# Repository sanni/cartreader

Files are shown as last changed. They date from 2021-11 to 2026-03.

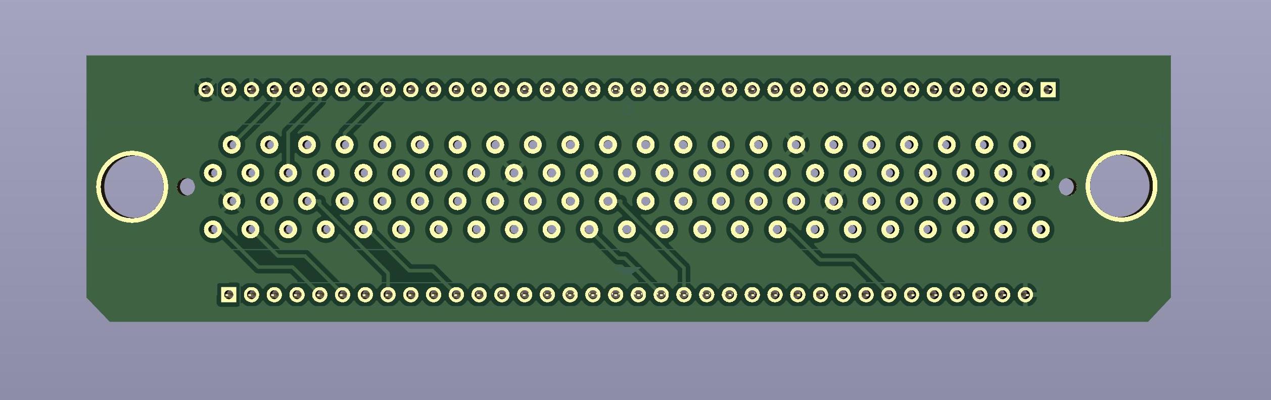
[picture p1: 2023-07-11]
hardware/loopy_adapter/loopy_adapter.jpg

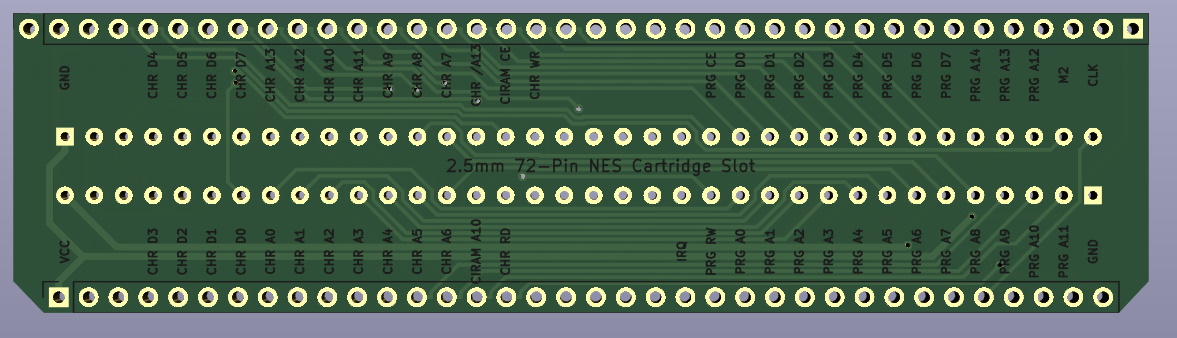
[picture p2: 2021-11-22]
hardware/nes_adapter/nes_adapter.jpg

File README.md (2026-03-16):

<br>    
<br>    
<br>   
<br>
We have moved, please visit us at https://github.com/oscartreader 🚀
<br>    
<br>    
<br>   
<br>
<br>    
<br>    
<br>   



# Open Source Cartridge Reader
This project represents a community-driven effort to provide an easy to build and easy to modify cartridge dumper.
Its main purpose is to dump a video game's ROM and save file to an SD card without the need of a PC.

For any questions you can use the [Discussions](https://github.com/sanni/cartreader/discussions) and/or [Issues](https://github.com/sanni/cartreader/issues) section here on GitHub, visit the accompanying thread in the [Arduino Forum](http://forum.arduino.cc/index.php?topic=158974.9001) or check out our [community discord server](https://discord.gg/YVxv7BnzXt), where you can reach most of the devs directly.

Also be sure to check the guides in the [Wiki](https://github.com/sanni/cartreader/wiki) too.

Happy making. 🔧🔨😊



#### Features:
- Modular design
- Stand-alone operation
- Easy to modify open-source code
- Portable when used together with a power bank



#### Supported Systems:
- NES/Famicom/Family Basic
- Super Nintendo/Super Famicom (including SF Memory, Satellaview, Sufami Turbo, and Game Processor RAM Cassettes)
- Nintendo 64 (including Controller Pak, Gameshark, and Xplorer 64)
- Game Boy Color (including GB Memory, Codebreaker, and Gameshark)
- Game Boy Advance
- Sega Mega Drive/Genesis
- Sega Master System



#### Supported with adapters:
- Virtual Boy
- Pokémon Mini
- Sega Game Gear
- Sega Mark III
- Sega SG-1000/SC-3000
- Sega Cards
- PC Engine/TurboGrafx-16/SuperGrafx
- WonderSwan (Color)
- NeoGeo Pocket (Color)
- Intellivision
- ColecoVision
- Benesse Pocket Challenge W
- Benesse Pocket Challenge V2
- Watara Supervision
- Atari 8-bit Computer (400/800/XL/XE)
- Atari 2600/5200/7800
- Atari Lynx
- Atari Jaguar
- Emerson Arcadia 2001
- Fairchild Channel F
- Magnavox Odyssey 2/Philips Videopac+
- Super A'Can
- MSX
- Casio PV-1000
- Casio Loopy
- Commodore VIC-20
- Commodore 64
- Vectrex
- Bally Astrocade
- Bandai Little Jammer
- Bandai Little Jammer Pro
- LeapFrog Leapster (L-MAX/Leapster2)
- RCA Studio II
- Texas Instruments TI-99
- Tomy Pyuuta
- TRS-80 Color Computer
- Vtech V.Smile (Baby/V.Motion)
- CPS3

#### Open Source Licenses:
- Software(everything in Cart_Reader folder) = GPL v3
- Hardware(everything in hardware folder) = CC BY 4.0
- Documentation(everything in the Wiki) = CC0 1.0

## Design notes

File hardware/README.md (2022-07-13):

## All the files in this directory are licensed under the Attribution 4.0 International (CC BY 4.0)     

### This means that you are free to:    
- Share - copy and redistribute the material in any medium or format    
- Adapt - remix, transform, and build upon the material for any purpose, even commercially.  

The licensor cannot revoke these freedoms as long as you follow the license terms.    

### Under the following terms:    
- Attribution - You must give appropriate credit, provide a link to the license, and indicate if changes were made. You may do so in any reasonable manner, but not in any way that suggests the licensor endorses you or your use.    
- No additional restrictions - You may not apply legal terms or technological measures that legally restrict others from doing anything the license permits.    

More details: https://creativecommons.org/licenses/by/4.0/

##

You can view the schematic and PCB files using [KiCad](https://www.kicad.org/).   
To design your own adapters you can follow this [tutorial](https://github.com/sanni/cartreader/wiki/Designing-your-own-Adapters)   
Also check out the user contributions for even more adapters: https://github.com/sanni/cartreader/discussions/354

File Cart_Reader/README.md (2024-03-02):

## This Arduino sketch is licensed under the GNU GENERAL PUBLIC LICENSE Version 3 (GPL v3)    

### This means that you are free to:    
- use, modify and distribute this software, even commercially    

### Under the following terms:    
- state changes   
- disclose source   
- same license   

### Limitations:
- Liability   
- Warranty   

More details: https://www.gnu.org/licenses/gpl-3.0.en.html    

## 

Every submodule has it's own setup_XX() function that configures the needed pins and a submenu that lets you choose what you want to do. 
The code directly addresses the pins via the DDR, PIN and PORT registers.   
Please also refer to the [pinout Open Office sheet](https://github.com/sanni/cartreader/blob/master/pinout.ods).    
```
void setup_N64_Controller() {  
  // Output a low signal  
  PORTH &= ~(1 << 4);  
  // Set Controller Data Pin(PH4) to Input  
  DDRH &= ~(1 << 4);  
}  
```

Would be the same as this in a more traditional Arduino sketch:  
```
int dataPin = 7;   

void setup(){    
  // Output a low signal   
  digitalWrite(dataPin, LOW);   
  // Set controller data pin to input  
  pinMode(dataPin, INPUT);  
}  
```
To preserve memory every string is saved into the flash of the Arduino, also called progmem. This is done by using the F() macro.   
```
println_Msg(F("Press Button."));  
```
Also all the menus are stored in progmem and are only recalled to sram when needed.  
```
// N64 controller menu items  
const char N64ContMenuItem1[] PROGMEM = "Test Controller";  
const char N64ContMenuItem2[] PROGMEM = "Read ControllerPak";  
const char N64ContMenuItem3[] PROGMEM = "Write ControllerPak";  
const char* const menuOptionsN64Controller[] PROGMEM = {N64ContMenuItem1, N64ContMenuItem2, N64ContMenuItem3, FSTRING_RESET};
```
In an effort to keep the codebase as portable as possible instead of using the functions supplied by the OLED library directly to print out text, auxiliary functions like `println_Msg` are being used. So if you want to change to another display library you don't need to change all the code but only the helper functions. 
```
void print_Msg(long unsigned int message) {
  if (ENABLE_OLED)
    display.print(message);
  if (ENABLE_SERIAL)
    Serial.print(message);
}
```

Before uploading the code to your Arduino you need to select your hardware version in Cart_Reader.ino        
```
//******************************************
// !!! CHOOSE HARDWARE VERSION !!!
//******************************************
// Remove // in front of the line with your hardware version
// #define HW5
// #define HW4
#define HW3
// #define HW2
// #define HW1
// #define SERIAL_MONITOR

```

For more info please have a look at [this wiki article](https://github.com/sanni/cartreader/wiki/How-to-flash-the-Arduino).   

Needed libraries(already included in the portable Arduino IDE under Releases)   

SD lib: https://github.com/greiman/SdFat    
LCD lib: https://github.com/olikraus/U8g2_Arduino     
Neopixel lib: https://github.com/adafruit/Adafruit_NeoPixel    
Rotary Enc lib: https://github.com/mathertel/RotaryEncoder    
SI5351 lib: https://github.com/etherkit/Si5351Arduino        
RTC lib: https://github.com/adafruit/RTClib (needs BusIO lib: https://github.com/adafruit/Adafruit_BusIO)     
Frequency Counter lib: https://github.com/PaulStoffregen/FreqCount

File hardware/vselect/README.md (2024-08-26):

# VSELECT: Automatic Voltage Selection Module

The VSELECT module automates voltage selection on HW5 by allowing the firmware to set the voltage. The module version is intended to be soldered in place of the voltage selection switch. You cannot use the VSELECT module and a power LED at the same time.

## Ordering the PCB and Installing the components

The VSELECT module requires SMD/SMC (surface-mounted devices/components) soldering. The pads have been extended slightly to aid in hand-soldering. While files suitable for use with JLCPCB's PCBA service have been included, these are unsuitable for most people to use due to the minimum order quantity. If you want fewer than 10 modules it will be cheaper to order them from someone selling pre-built ones.

## Installation

Instructions to build as well as to install the module have moved [to the wiki](https://github.com/sanni/cartreader/wiki/Automatic-Voltage-Selection).

## Configuration

The module requires code to function properly. The OSCR should still power on even without the code changes but the voltage will not automatically toggle. To enable automatic toggling, locate this bit of code:

```
/*==== HARDWARE MODULES ===========================================*/

/* [ Automatic Voltage Selection ---------------------------------- ]
    Enable this if you have the VSELECT module.
*/

//#define ENABLE_VSELECT
```

...and change it to:

```
/*==== HARDWARE MODULES ===========================================*/

/* [ Automatic Voltage Selection ---------------------------------- ]
    Enable this if you have the VSELECT module.
*/

#define ENABLE_VSELECT
```

After that simply update/program/flash your Arduino/OSCR as normal. Make sure you enable this every time you update. You can test that voltage switching is occurring with a multimeter by checking between ground and VCC.

## Updating
When the OSCR is using VSELECT-enabled firmware there are a few extra steps you need to take when flashing firmware. First, before connecting the OSCR to a computer, remove the SD card. Next, connect the OSCR to your computer and wait. Once it prompts you, press the button to set the voltage to 5V. Although you can flash the ATmega2560 while running at 3.3V it does not always work and seems more likely to cause the firmware to randomly be corrupt (sometimes right away, sometimes not for a few days). Although you can just reflash the firmware to it to resolve it, having to deal with it is rather inconvenient.

## Troubleshooting
If the 3.3V rail is not powered (i.e. you forgot to solder the jumper on the LCD) then when the module tries to switch to that it will power off the VCC rail. This will appear as a reboot loop where you'll see it briefly power on and then immediately power off only to immediately power on again. This is because the module starts in 5V mode and switches to 3.3V after the system boots and tells it to do so.

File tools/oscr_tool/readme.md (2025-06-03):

A small tool for Windows 10/11 that helps manage the portable release.

oscr_tool

Copy the files to the root directory of the portable release and double click on launch_oscr_tool.bat to start it.

launch

If you get an error you need to first allow the script to run by right-clicking oscr_tool.ps1, Properties and then tick the Unblock checkbox.

unblock

You can also create an apply_config.txt with the settings you always want to have applied, see example apply_config.txt.

This tool was made by ChatGPT, Claude AI and Github Copilot. Console descriptions are taken from the respective Wikipedia sites.

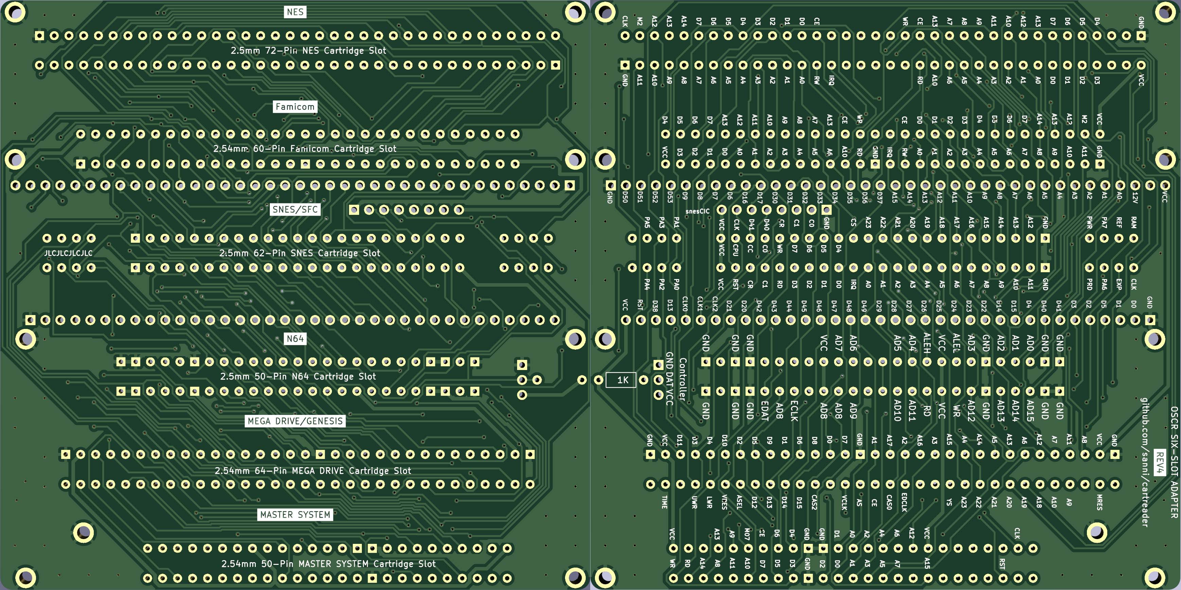
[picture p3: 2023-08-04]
hardware/six_slot_adapter/six_slot_adapter.jpg

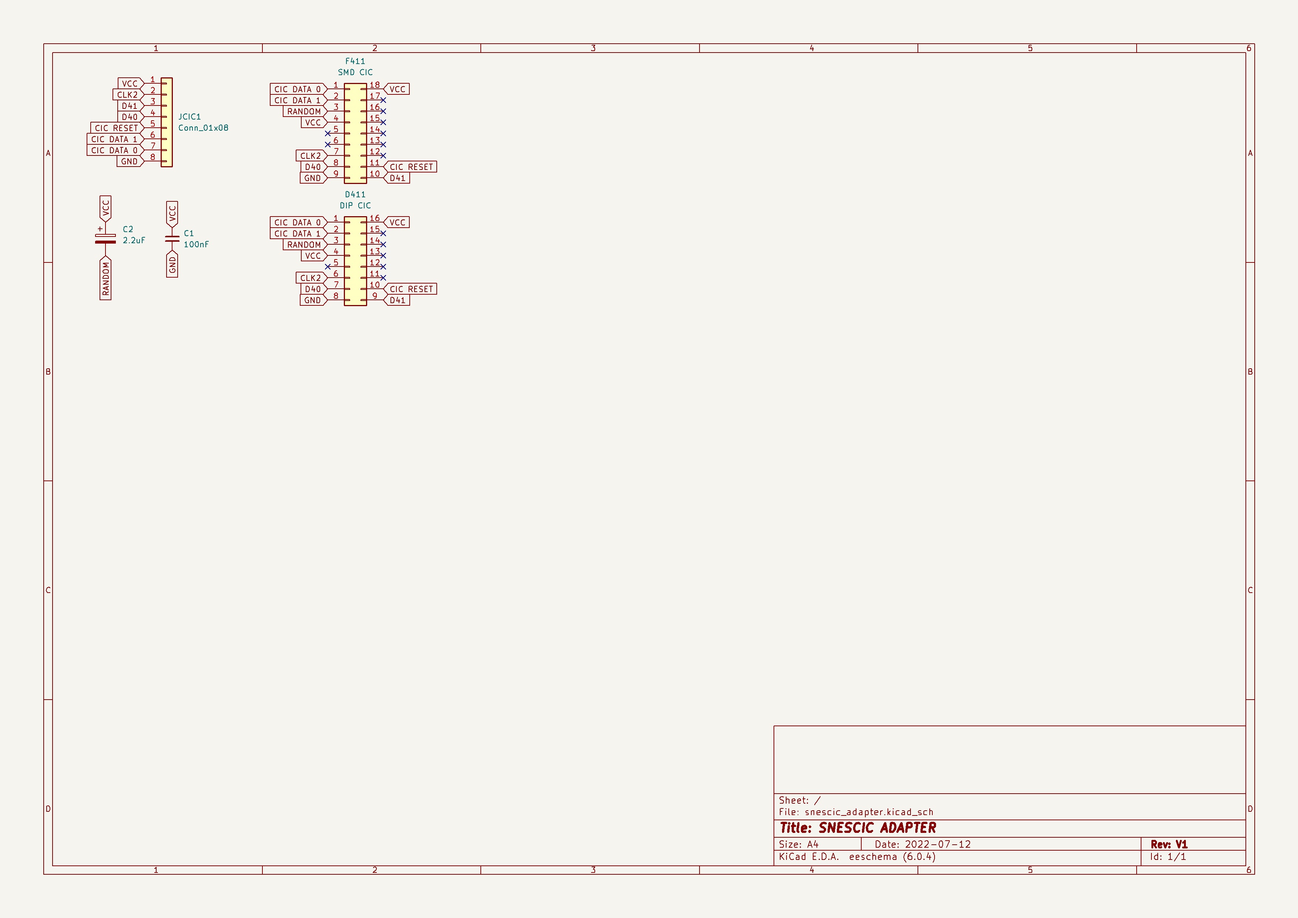
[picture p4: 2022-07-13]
hardware/cic_adapter/D411_F411_adapter_schematics.jpg

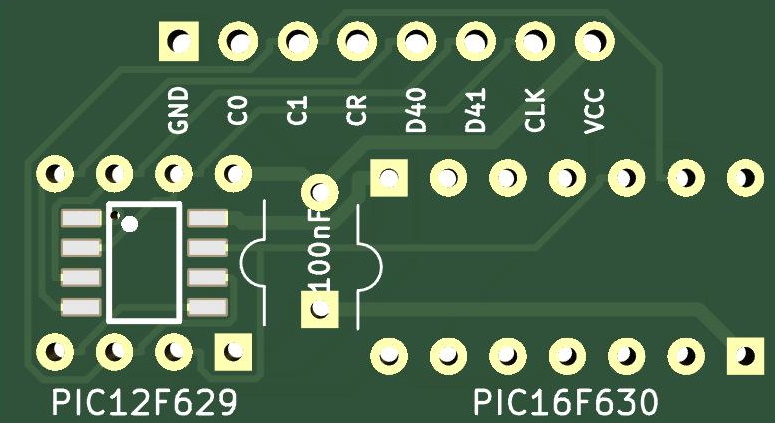
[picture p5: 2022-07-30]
hardware/cic_adapter/PIC_adapter.jpg

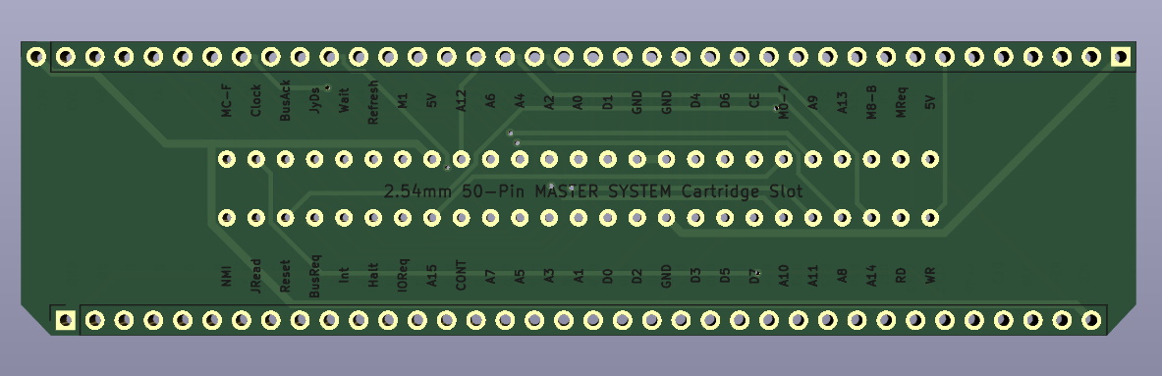
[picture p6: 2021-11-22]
hardware/mastersystem_adapter/mastersystem_adapter.jpg

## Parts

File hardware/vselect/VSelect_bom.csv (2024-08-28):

Designator | Footprint | Quantity | Value | LCSC Part #
C1, C2 | 0402 | 2 | 0.1u | C1525
C3 | 0402 | 1 | 10u | C15525
R1 | 0402 | 1 | 560R | C25123
U1 | IC - VSELECT - TPS2113 | 1 | TPS211x | C354512

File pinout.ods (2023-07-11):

Arduino | Alt. Arduino | ATMega2560 | Game Boy | GBA | NES | SNES | snesCIC | N64 ROM | N64 Controller | N64 EEP | Master System | Megadrive | PCE/TG16 | Wonderswan | Loopy | LED | SD Card | OLED | LCD | Button | Rotary Encoder | Neopixel | 16bit Flash | 8bit Flash | 16bit Flash in 8bit Mode | 27C322 Eprom
A0 | D54 | PF0 | A0 | AD0 | M2 | A0 |  | AD0 |  |  | A0 | A1 | A0 | A-1 | D10 |  |  |  |  |  |  |  | A0 | A0 | D15 | A0
A1 | D55 | PF1 | A1 | AD1 | PRG_CE | A1 |  | AD1 |  |  | A1 | A2 | A1 | A0 | D8 |  |  |  |  |  |  |  | A1 | A1 | A0 | A1
A2 | D56 | PF2 | A2 | AD2 | CHR_WR | A2 |  | AD2 |  |  | A2 | A3 | A2 | A1 | D6 |  |  |  |  |  |  |  | A2 | A2 | A1 | A2
A3 | D57 | PF3 | A3 | AD3 | CIRAM_CE | A3 |  | AD3 |  |  | A3 | A4 | A3 | A2 | D4 |  |  |  |  |  |  |  | A3 | A3 | A2 | A3
A4 | D58 | PF4 | A4 | AD4 | CHR_/A13 | A4 |  | AD4 |  |  | A4 | A5 | A4 | A3 | D14 |  |  |  |  |  |  |  | A4 | A4 | A3 | A4
A5 | D59 | PF5 | A5 | AD5 | CHR_RD | A5 |  | AD5 |  |  | A5 | A6 | A5 | A4 | D3 |  |  |  |  |  |  |  | A5 | A5 | A4 | A5
A6 | D60 | PF6 | A6 | AD6 | IRQ | A6 |  | AD6 |  |  | A6 | A7 | A6 | A5 | D2 |  |  |  |  |  |  |  | A6 | A6 | A5 | A6
A7 | D61 | PF7 | A7 | AD7 | PRG_RW | A7 |  | AD7 |  |  | A7 | A8 | A7 | A6 | RESET |  |  |  |  |  |  |  | A7 | A7 | A6 | A7
A8 | D62 | PK0 | A8 | AD8 | D0 | A8 |  | AD8 |  |  | A8 | A9 | A8 | A7 | D0 |  |  |  |  |  |  |  | A8 | A8 | A7 | A8
A9 | D63 | PK1 | A9 | AD9 | D1 | A9 |  | AD9 |  |  | A9 | A10 | A9 | A8 | A0 |  |  |  |  |  |  |  | A9 | A9 | A8 | A9
A10 | D64 | PK2 | A10 | AD10 | D2 | A10 |  | AD10 |  |  | A10 | A11 | A10 | A9 | A1 |  |  |  |  |  |  |  | A10 | A10 | A9 | A10
A11 | D65 | PK3 | A11 | AD11 | D3 | A11 |  | AD11 |  |  | A11 | A12 | A11 | A10 | A21 |  |  |  |  |  |  |  | A11 | A11 | A10 | A11
A12 | D66 | PK4 | A12 | AD12 | D4 | A12 |  | AD12 |  |  | A12 | A13 | A12 | A11 | A3 |  |  |  |  |  |  |  | A12 | A12 | A11 | A12
A13 | D67 | PK5 | A13 | AD13 | D5 | A13 |  | AD13 |  |  | A13 | A14 | A13 | A12 | A20 |  |  |  |  |  |  |  | A13 | A13 | A12 | A13
A14 | D68 | PK6 | A14 | AD14 | D6 | A14 |  | AD14 |  |  | A14 | A15 | A14 | A13 | A15 |  |  |  |  |  |  |  | A14 | A14 | A13 | A14
A15 | D69 | PK7 | A15 | AD15 | D7 | A15 |  | AD15 |  |  |  | A16 | A15 | A14 | A13 |  |  |  |  |  |  |  | A15 | A15 | A14 | A15
D0 | RX0 | PE0
D1 | TX0 | PE1 |  |  |  |  |  |  |  |  |  |  |  |  |  | build-in (LCD blink)
D2 | PWM | PE4 |  |  |  | WRAM |  |  |  |  |  | (YS) |  | IO | D11
D3 | PWM | PE5 |  |  |  | REFRESH |  |  |  |  |  | CAS2 |  | CLK | D9
D4 | PWM | PG5 |  |  |  | EXPAND |  |  |  |  |  | ASEL |  | Int | D15
D5 | PWM | PE3 |  |  |  |  |  |  |  |  |  | EDCLK
D6 | PWM | PH3 | CS | CS_ROM |  | CS |  |  |  |  | A15/M0-7 | CS | OE | CART | RAMWE |  |  |  |  |  |  |  | BYTE | OE | OE
D7 (1K Pullup) | PWM | PH4 | Sound | IRQ |  | IRQ |  |  | DATA | DATA |  | WR HIGH | IRQ2 | MMC | RAMCS2 |  |  |  |  |  |  |  | WE
D8 | PWM | PH5 | WR | WR |  | WR |  | WR |  |  | WR | WR LOW | WR | WE |  |  |  |  |  |  |  |  | WP | WE | WE | To NPN transistor controlling VPP 12V stepup regulator module
D9 | PWM | PH6 | RD | RD |  | RD |  | RD |  |  | OE | OE |  | OE |  |  |  |  |  |  |  |  | CE | CE | CE | CE
D10 | PWM | PB4 |  |  |  |  |  |  |  |  |  |  |  |  |  | Blue (OLED blink) |  |  | Reset
D11 | PWM | PB5 |  |  |  |  |  |  |  |  |  |  |  |  |  | Green |  |  | DC/A0
D12 | PWM | PB6 |  |  |  |  |  |  |  |  |  |  |  |  |  | Red |  |  | CS
D13 | PWM | PB7 |  |  |  |  |  |  |  |  |  |  |  |  |  | build-in (Serial blink) |  |  |  |  |  | Neopixel
D14 | TX3 | PJ1 |  |  |  | PAWR |  |  |  |  |  | AS |  |  | D12
D15 | RX3 | PJ0 |  |  |  | PARD |  |  |  |  |  | Time |  |  | D13
D16 | TX2 | PH1 | CLK | CLK |  |  |  |  |  |  | CLK | VCLK
D17 | RX2 | PH0 | Reset | CS_RAM |  | Reset |  | Reset |  | Reset | Reset | (MRES),VRES | RST | Reset |  |  |  |  |  |  |  |  | Reset | Reset | Reset
D18 | TX1 | PD3 |  |  |  |  |  |  |  |  |  |  |  |  |  |  |  |  |  |  | ENC1
D19 | RX1 | PD2 |  |  |  |  |  |  |  |  |  |  |  |  |  |  |  |  |  |  | ENC2
D20 | SDA | PD1 |  |  |  |  |  |  |  |  |  |  |  |  |  |  |  | SDA
D21 | SCL | PD0 |  |  |  |  |  |  |  |  |  |  |  |  |  |  |  | SCL
D22 |  | PA0 |  |  | A8 | PA0 |  |  |  |  |  | D8 |  | D8 | D1 |  |  |  |  |  |  |  | D8 |  |  | D8
D23 |  | PA1 |  |  | A9 | PA1 |  |  |  |  |  | D9 |  | D9 | A2 |  |  |  |  |  |  |  | D9 |  |  | D9
D24 |  | PA2 |  |  | A10 | PA2 |  |  |  |  |  | D10 |  | D10 | A4 |  |  |  |  |  |  |  | D10 |  |  | D10
D25 |  | PA3 |  |  | A11 | PA3 |  |  |  |  |  | D11 |  | D11 | A19 |  |  |  |  |  |  |  | D11 |  |  | D11
D26 |  | PA4 |  |  | A12 | PA4 |  |  |  |  |  | D12 |  | D12 | A18 |  |  |  |  |  |  |  | D12 |  |  | D12
D27 |  | PA5 |  |  | A13 | PA5 |  |  |  |  |  | D13 |  | D13 | A16 |  |  |  |  |  |  |  | D13 |  |  | D13
D28 |  | PA6 |  |  | A14 | PA6 |  |  |  |  |  | D14 |  | D14 | A17 |  |  |  |  |  |  |  | D14 |  |  | D14
D29 |  | PA7 |  |  |  | PA7 |  |  |  |  |  | D15 |  | D15 | A14 |  |  |  |  |  |  |  | D15 |  |  | D15
D30 |  | PC7 | D7 | A23 |  | D7 |  |  |  |  | D7 | D7 | D7 | D7 |  |  |  |  |  |  |  |  | D7 | D7 | D7 | D7
D31 |  | PC6 | D6 | A22 |  | D6 |  |  |  |  | D6 | D6 | D6 | D6 |  |  |  |  |  |  |  |  | D6 | D6 | D6 | D6
D32 |  | PC5 | D5 | A21 |  | D5 |  |  |  |  | D5 | D5 | D5 | D5 |  |  |  |  |  |  |  |  | D5 | D5 | D5 | D5
D33 |  | PC4 | D4 | A20 |  | D4 |  |  |  |  | D4 | D4 | D4 | D4 |  |  |  |  |  |  |  |  | D4 | D4 | D4 | D4
D34 |  | PC3 | D3 | A19 |  | D3 |  |  |  |  | D3 | D3 | D3 | D3 | A12 |  |  |  |  |  |  |  | D3 | D3 | D3 | D3
D35 |  | PC2 | D2 | A18 | CIRAM_A10 | D2 |  |  |  |  | D2 | D2 | D2 | D2 | A10 |  |  |  |  |  |  |  | D2 | D2 | D2 | D2
D36 |  | PC1 | D1 | A17 |  | D1 |  | ALE_H |  |  | D1 | D1 | D1 | D1 | A8 |  |  |  |  |  |  |  | D1 | D1 | D1 | D1
D37 |  | PC0 | D0 | A16 |  | D0 |  | ALE_L |  |  | D0 | D0 | D0 | D0 | A6 |  |  |  |  |  |  |  | D0 | D0 | D0 | D0
D38 |  | PD7 |  |  |  |  |  |  |  |  |  |  |  |  |  | HW5 status LED |  |  |  | Button1 (10K Pullup)
D39 |  | PG2 |  |  |  |  |  |  |  |  |  |  |  |  |  |  |  |  |  | Button 2 (10K Pullup) | ENC Button
D40 |  | PG1 |  |  |  |  | Reset In (Pin 4) |  |  |  |  |  |  |  | D5
D41 |  | PG0 |  |  |  |  | Reset Out Host (Pin 3) |  |  |  |  |  |  |  | D7
D42 |  | PL7 |  |  | A7 | A23 |  |  |  |  |  |  | Card Detect |  | CE
D43 |  | PL6 |  |  | A6 | A22 |  |  |  |  |  | A23 | Audio In |  | OE |  |  |  |  |  |  |  |  |  | A21
D44 | PWM | PL5 |  |  | A5 | A21 |  |  |  |  |  | A22 | HSM |  |  |  |  |  |  |  |  |  | A21 | A21 | A20
D45 | PWM | PL4 |  |  | A4 | A20 |  |  |  |  |  | A21 | CE |  |  |  |  |  |  |  |  |  | A20 | A20 | A19 | A20
D46 | PWM | PL3 |  |  | A3 | A19 |  |  |  |  |  | A20 | A19 | A18 | A11 |  |  |  |  |  |  |  | A19 | A19 | A18 | A19
D47 |  | PL2 |  |  | A2 | A18 |  |  |  |  |  | A19 | A18 | A17 | A9 |  |  |  |  |  |  |  | A18 | A18 | A17 | A18
D48 |  | PL1 |  |  | A1 | A17 |  |  |  |  | CE | A18 | A17 | A16 | A7 |  |  |  |  |  |  |  | A17 | A17 | A16 | A17
D49 |  | PL0 |  |  | A0 | A16 |  |  |  |  |  | A17 | A16 | A15 | A5 |  |  |  |  |  |  |  | A16 | A16 | A15 | A16
D50 | MISO | PB3 |  |  |  |  |  |  |  |  |  |  |  |  |  |  | MISO
D51 | MOSI | PB2 |  |  |  |  |  |  |  |  |  |  |  |  |  |  | MOSI |  | MOSI
D52 | SCK | PB1 |  |  |  |  |  |  |  |  |  |  |  |  |  |  | SCK |  | SCK
D53 | SS | PB0 |  |  |  |  |  |  |  |  |  |  |  |  |  |  | SS
CLK0 |  |  |  |  |  | CLK
CLK1 |  |  |  |  |  | CPUCLK |  |  |  | EEP CLK
CLK2 |  |  |  |  |  | CICCLK | CLK (Pin 2)
 |  |  |  |  |  | Reset In | Reset Out Slave (Pin 5)
 |  |  |  |  |  | CIC1 | CIC1 (Pin 6)
 |  |  |  |  |  | CIC0 | CIC0 (Pin 7)
GND |  |  |  |  |  |  |  |  |  |  |  |  |  |  |  |  |  |  |  |  |  |  |  |  | BYTE

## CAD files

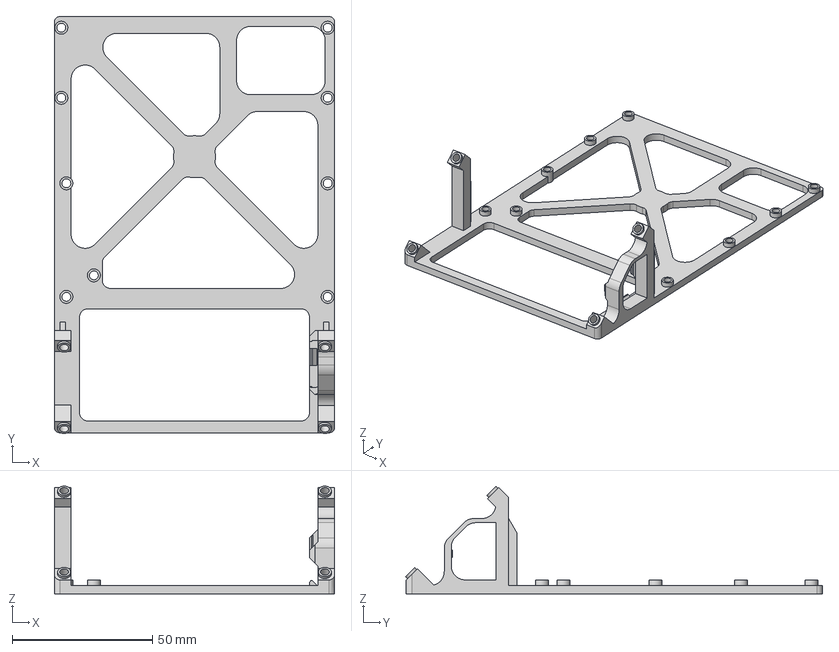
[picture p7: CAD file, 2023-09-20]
hardware/main_pcb_hw5/Main PCB Stand - Right N64 Adapter with Battery Access.step
100.0 x 148.7 x 38.5 mm

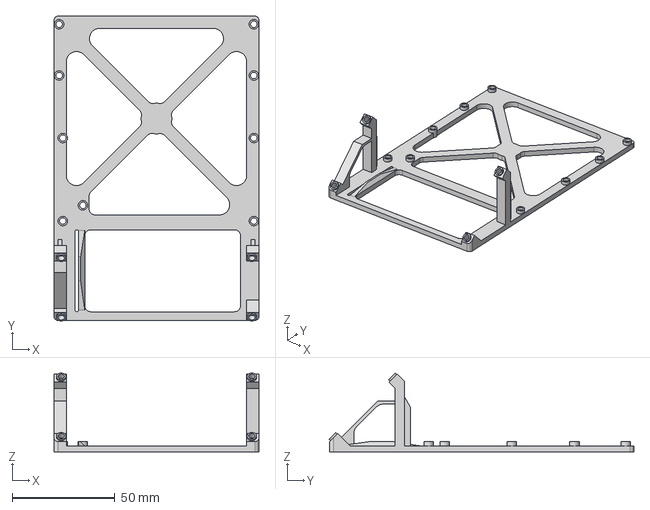
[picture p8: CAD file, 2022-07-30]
hardware/main_pcb_hw5/Main PCB Stand - Left N64 Adapter.step
100.0 x 148.7 x 38.5 mm

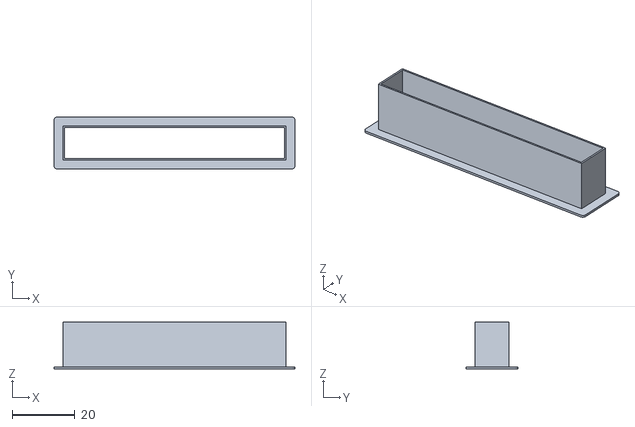
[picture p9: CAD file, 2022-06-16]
hardware/six_slot_adapter/n64sleeve.stl
77.0 x 16.6 x 15.0

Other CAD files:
hardware/main_pcb_hw5/Main PCB Stand - Right N64 Adapter.step
hardware/main_pcb_hw5/Main PCB Stand - No N64 Adapter.step
hardware/main_pcb_hw5/Main PCB Stand - Left N64 Adapter.stl
hardware/main_pcb_hw5/Main PCB Stand - No N64 Adapter.stl
hardware/main_pcb_hw5/Main PCB Stand - Right N64 Adapter.stl

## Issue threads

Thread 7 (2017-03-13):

PCB does not convert logic level of SD card

nvsofts, 2017-03-13:
cartreader PCB uses "LC Studio" SD card module.
This module does not convert logic level of SD card.
This will be damaged or caused unexpected behavior to SD card.

I used this module to fix the problem.

microSD card module (Parts no: MCSD125A)
http://www.aitendo.com/product/10192 (Sorry, this page is written in Japanese)

The module uses SN74LV125A buffer IC to convert logic level.
However, the module does not contain 3.3V pin.
Therefore I applied small hack to the module (desolder AMS1117, short 5V-3.3V solder pad).

nvsofts, 2017-03-13:
similar item found in US Amazon
https://www.amazon.com/dp/B00SL0QWDU/

tamanegitaro, 2017-05-30:
nvsoft is correct.
Level shifter is not implemented on LC studio SD card module if the schematic in this thread is correct:
https://forum.arduino.cc/index.php?topic=369079.0
So you need to use level shifter for CS, SCK, MOSI, MISO pins or use microsd card adapter nvsoft provided.
I don't think you need to remove AMS1117 though because microsd card adapter also support 3.3V.
You don't need to remove AMS1117.

So best solution is to use microsd adapter and connect 5V to VCC on microsd adapter. So all CS, SCK, MOSI, MISO, and VCC will be 5V in 5V mode and be 3V in 3V mode.

sanni, 2017-07-10:
I added an option to install the suggested microSD module to the pcb. Since the cartreader shield already has an AMS1117 I desoldered it from the microSD module and shorted the 5V-3.3V solder pads on the AMS1117's footprint.

But be aware that from my tests microSD cards are twice as slow as standard sized cards with the sdfat library I'm using for the cart reader. I don't know why though.

tamanegitaro, 2017-08-02:
Ahh my bad. Desoldering AMS1117 and connect 3.3V is best way to get around.

Supplying 3.3V to AMS1117 on micro SD card module is not enough because AMS1117 dropout voltage is 1.1V.
Which means voltage of sd card's signal line will become 2.2V and SD card require 2.7V-3.6V as minimum to maximum, respectively.
Another option will be to supply 5V (from slide switch) to AMS1117 on microsd module so I'm gong to try that.

Closed 2018-04-21.

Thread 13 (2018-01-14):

Gerber files

AireagoirSteam, 2018-01-14:
Are there Gerber files for the all in one variant? The wiki lists ones for another variant.

sanni, 2018-01-15:
The currently uploaded "github version" pcb design has been tested many times and works great.
The all-in-one variant is still in development and therefore no gerber files are available.
Both variants are functionally equivalent so you're not missing out on anything if you order the github version.

If you really really want the all-in-one then I can send you a prototype pcb, just the pcb no parts.
Message me on the Arduino forum in case you're interested.

Closed 2018-04-21.

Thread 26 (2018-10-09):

Status of firmware compatibility with SNES and N64 old version

vogelfreiheit, 2018-10-09:
Hi,

I have built an older version of the hardware, with N64 and SNES slots. Does the current firmware support that version? Or I need to modify any pin settings or such?

sanni, 2018-10-09:
It's 100% compatible with the newest firmware. I'm still using one of the earlier Cart Reader PCBs myself.

vogelfreiheit, 2018-10-09:
Thanks man! I might consider selling some kits or bare PCBs if you are OK with that. I just made too many. I can also send you some. Got photos of the silkscreening and all. I will flash the  board now and check back.

BTW I populated the capacitor at the USB input. I never saw it mentioned anywhere in the guides but it shouldn't hurt (the electrolytic).

vogelfreiheit, 2018-10-09:
One issue I encountered with some N64 carts: flashram unknown is reported. I have the external clock ref enabled and plugged in through a pin header. What could possibly cause this?

vogelfreiheit, 2018-10-09:
Re-tested with both Arduino-sourced power and using the port on the shield. I'm using 3.3V, no EEP and EEP and the clock settings turned off. No improvement there.

sanni, 2018-10-10:
Have you tested dumping the rom of the cartridge to make sure everything works with the N64 cart slot? Also try to write a save game to a cartridge with the sram save type to verify that writing to a N64 cartridge in general works so you can rule out a cold solder joint.

vogelfreiheit, 2018-10-12:
I will upload a patch later, I had to add support for two cartridges that use one of the 'alternative' configurations (they can either have a MN63F81MPN or 29L1100KC) that identify as different ICs, but are still supported by the present code for 29L1100KC-15B0.

The codes were 0x84 and 0x8e if I recall correctly. The hardware itself presents no issues. I get more problems out of the GBA/GBC slot adapter+cartridge setup than anything else. N64 carts and anything with direct slot plugging works fine.

It might be worth considering adding a PCB that takes a salvaged GBC cart slot, which are arguably the best for that system (no pin wear and no issues with the cart moving slightly and causing contact problems).

sanni, 2018-10-13:
Yes that's the reason why the current PCB design has both the MD and GB slot directly on the main PCB without any adapters.

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

Closed 2018-11-20.

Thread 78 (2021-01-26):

Only post issues with existing code for already supported stuff.

sanni, 2021-01-26:
For general questions or help with currently unsupported stuff please post in the Discussions section.

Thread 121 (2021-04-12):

Problem when reading save from Nintendo 64 EEPROM cartidges

parski, 2021-04-12:
I've been dumping Nintendo 64 SRAM games without issue but now attempting to dump EEPROM save files it appears to crash. These are my steps:

DIPS:

```
+-------+-------+
| 3V/5V | 3V  < |
+-------+-------+
| EEP   | ON  > |
+-------+-------+
| CLK0  | OFF < |
+-------+-------+
| CLK1  | OFF < |
+-------+-------+
```

1. Turn the unit ON.
2. Select **Nintendo 64**
3. Select **Game Cartridge**

```
N64 Cartridge Info

Name: MARIOKART64
ID: NKTJ Size: 12MB
Save: 4K Eeprom
Version: 1.0

Press Button...
```

4. Press button
5. Select **Read Save**

LED flashes blue maybe five times in rapid succession, then LED is persistently off. Stuck on the screen is the following:

```
Reading Eep...
```

I've tried leaving the unit on for a good 20 minutes and I'm assuming something is wrong and that this is not an overnight operation. How can I troubleshoot this? As previously mentioned, dumping SRAM is not a problem.

parski, 2021-04-12:
When checking the SD card after an attemt it has created a directory structure like so:
```
/N64/SAVE/{game}/{integer}/
```
With one `{integer}` directory per attempt. These directories are empty.

sanni, 2021-04-13:
Make sure its an original cartridge and not a Chinese reproduction.
Reading the eeprom needs two connections, data and clock. Try resoldering all the points on the PCB involved and make sure the 1K resistor in the data line is connected properly too.

You can also use a multimeter to check all the traces.

This is the clock line on the PCB, it comes from the Arduino pin D16 at the top, goes through the CLK1 switch(switched to off) and then finally into the CLK pin on the N64 cart slot:
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

This is the data line, it goes from Arduino pin D7 straight into the DAT pin on the N64 cart slot, but is also connected to the EEP switch and through the EEP switch(switched to on) it goes to the 1K resistor to VCC:
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

If you got the N64 controller plug installed you can also test the DAT pin with a N64 controller, if the controller test works the DAT pin is ok. However the CLK pin is not used with the controller.

If all the physical connections are ok you can clean the cart edge connector of the game with a q-tip and some rubbing alcohol.
Lastly you can try another eeprom game to see if the issue maybe is specific to the particular eeprom chip in Mario Kart. I always wanted to rewrite the current eeprom code to utilise the clock generator to be more precise, but so far all the carts I tested worked with the current somewhat crude implementation that doesn't need a clock gen.

parski, 2021-04-14:
Thank you for your exceptional response.

I get continuity between D16 on the Arduino and the CLK pin in the Nintendo 64 cartridge slot with the CLK1 switch set to the OFF position, as you described.

I also get continuity between D7 on the Arduino and the DAT pin in the Nintendo 64 cartridge slot regardless if the EEP switch is set to ON or OFF.

I've tried several cartridges including a launch copy of Super Mario 64 so I'm certain they are not counterfit.

I'll see if I can find an expansion pack and try to dumb saves via a controller since I'm less sure about the DAT pin as it involves a resistor and VCC.

I'll also grab a bottle of isopropyl alhohol and a few other EEPROM based games and report back.

sanni, 2021-04-14:
The EEP switch enables the 1K resistor on the DAT line. To test that, switch the Cart Readers On/OFF switch to OFF then use the multi-meter in Ohm mode and measure the resistance between the DAT pin and the VCC pin on the N64 cart slot. It should be around 1 kOhm when the EEP switch is set to ON.

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

parski, 2021-04-14:
I'm getting within reasonable tolerances the same 1kΩ I expect between DAT and VCC when the main power switch is set to OFF and EEP switch is set to on.
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

sanni, 2021-04-15:
I just added an alternative way to read/write the Eeprom if you have the Adafruit Clockgen module installed with V5.7:

In options.h change:
```
// Read N64 Eeprom with Adadruit clockgen, CLK1 switch needs to be switch to ON
//#define clockgen_installed
```

to:
```
// Read N64 Eeprom with Adadruit clockgen, CLK1 switch needs to be switch to ON
#define clockgen_installed
```

Then setup the switches like this:

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

parski, 2021-04-15:
I'm happy to report that your clockgen fix **solved the issue**. I've dumped the EEPROM saves of a PAL version of Super Mario 64 as well as an NTSC-J version of Mario Kart 64 successfully using what's currently the latest `master`.

Thank you for your kind help. This issue can be closed.

sanni, 2021-04-15:
Glad I could help. 👍

Closed 2021-04-15.

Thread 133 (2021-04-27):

Dumping N64

Coaleb2, 2021-04-27:
Dumping Pokemon Stadium 2 and Conkers Bad Fur Day Will give a crc error. Cleaning the port and cleaning the pins did not fix the issue. I tried multiple dumps to no avail

sanni, 2021-04-27:
- If those games are reproductions then the CRC error is to be expected.

- If they are original then please check the voltage between those two points, it needs to be 3.3V when the switch is in 3V mode:

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

Other than that I can only think of the cart being seated not perfectly centered into the cart slot.

Coaleb2, 2021-04-27:
Okay mine is staying at 5v so that could be my problem. The rest of my games worked fine which is weird

sanni, 2021-04-27:
My Pokemon Stadium does the same. It needs 3.3V to dump. Older/smaller carts also work with 5V.

Make sure you followed the [build guide](https://github.com/sanni/cartreader/wiki/How-to-build-the-PCB) and did not forget to desolder the 5V regulator and the transistor from the Arduino board:
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

Coaleb2, 2021-04-27:
Yeah thats where I am confused. I did de-solder that on mine. I re-soldered the points with a 470uf capacitor added in

Coaleb2, 2021-04-27:
I see what I did wrong. I missed removing the transistor. That explains a lot. I must have added it back in when I was flashing the Arduino.

Coaleb2, 2021-04-27:
Once I removed it it instantly worked dumping one of the games I could not before. Thank you for the help. I would not have noticed that transistor being there

Closed 2021-04-28.

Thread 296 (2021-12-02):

Gameboy dump issue

drpaneas, 2021-12-02:
I've just got mine (pre-assembled) but any Gameboy cartridge I try to dump is not recognized. No name, no rom, just some broken files. How can I troubleshoot what's wrong there?

sanni, 2021-12-02:
The most efficient way would be to contact your seller and ask for a replacement but if that is not an option or if you like the challenge of fixing it yourself then I found that the fastest way to troubleshoot the hardware is to compare a broken dump to a known good one of the same game in an hex editor and then try to see a pattern which points to a specific address or data line being the culprit.

It's important to know that with the hardware V3 all slots are connected in parallel so the hardware defect could be on any of the slots and still have an effect on the Gameboy slot. This is something I changed with hardware V4.

To find the issue you should use a standard Game Boy (Color) game, not Game Boy Advance since GB(C) has an easier protocol where address lines and data lines are split.

Here is an example of this way to troubleshoot from the perspective of the N64 slot: https://forum.arduino.cc/t/rom-reader-for-super-nintendo-super-famicom-game-cartridges/155260/1270?u=sanni

And here the same issue but seen from the GB slot: https://forum.arduino.cc/t/rom-reader-for-super-nintendo-super-famicom-game-cartridges/155260/1272?u=sanni

So using different slot you can also crosscheck the issue. In this case the user had a bad solder connection on Arduino Pin A8.

Dakkaron, 2021-12-03:
Looks like the kickstarter mess is rolling in... If you can't get the device fixed by the seller, try to resolder every single solder connection on the board.

Androxilogin, 2021-12-03:
> Looks like the kickstarter mess is rolling in... If you can't get the device fixed by the seller, try to resolder every single solder connection on the board.

Unfortunately this is my problem. I used Kester solder rosin core. The flux apparently backfed into the switches and hardened even after vigorously cleaning the board and components afterwards. So it was working fine while in my hands then presented itself later on. We've been in contact about this issue and walking through it.

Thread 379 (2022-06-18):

5V works, 3.3V does not

sanni, 2022-06-18:
### As discussed in https://github.com/sanni/cartreader/discussions/369

There seems to be a new Mega 2560 Pro variant that does not turn on when the Cart Reader is switched to 3V.

# Update 2:
This method now has been confirmed to work with HW5 too. You just need to take 3.3V from another point on the PCB since the Cartridge Port Adapter pin header doesn't carry 3.3V with HW5 anymore.

HW5 Rev3: Close solder jumper TP3/TP4

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

HW5 Rev2: Connect 3V from voltage switch on right side to 3V of Arduino

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

HW5 Rev1: Connect 3V from voltage switch on left side to 3V of Arduino

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

Reminder: This is only needed if your Mega 2560 Pro has the "new PCB design" that does not turn on with the switch set to 3.3V.
Why this works is unknown so far. According to the schematics the 3.3V pin of the Arduino does not power anything so it should not be needed.

# Update 1:
A first clue has been found as to what could be causing the issue (HW4):

[0xyzzyx wrote](https://github.com/sanni/cartreader/discussions/369#discussioncomment-3005485):
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

sanni, 2022-06-18:
It seems that newer Arduino Mega Pro's can't be run at 3.3V anymore. I have ordered one and will have a look as to why.

sanni, 2022-06-24:
A first clue has been found as to what could be causing the issue:

[0xyzzyx wrote](https://github.com/sanni/cartreader/discussions/369#discussioncomment-3005485):
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

stewartspicer, 2022-06-27:
Hey there,

I'm having a similar issue, and I'd just like to try to verify that it's the SAME issue before I attempt the same fix.

I'm just now starting to build my reader. The only parts I have installed on the main PCB are the battery holder and the GBA reader board (with slot, headers, and switch).

5v mode, works fine. Same voltage as the 5v out on the battery. 3v mode, I get nada. Looking at the traces, I also fail to see how the power gets from the battery mount to the 3V pin there. I've read through the schematics and followed the traces, but I don't see how the 3.3V actually gets to the 3V pin

stewartspicer, 2022-06-28:
I think I'm an idjit and the power comes from the screen. Identified the voltage regulator on the LCD module, and it looks like it has a 3.3V output. I just assumed it was input, but I think I'm just gonna send it and try the above fix if I don't have voltage after the screen in installed

Closed 2022-08-19.

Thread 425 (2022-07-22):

Problems with STL files (frame & n64sleeve)

Ancyker, 2022-07-22:
I'm having issues with getting the STL files for the frame and N64 sleeve printed. I ordered my PCBs from JLCPCB and also tried to order the 3D prints from them as well.

Here's what they said about...

**frame.stl**
Automated: https://prnt.sc/Ea2gph5ZHrud
Human reviewed: https://prnt.sc/nEG_2CumNznb

**n64sleeve.stl**
Automated: https://prnt.sc/C4l1jcY--la5
Human reviewed: https://prnt.sc/0hOJn1jjVEEA

I'm not sure if I'm doing something wrong as I'm not super familiar with 3D printing so I apologize in advance if this is some sort of user error. Also, since I'm posting anyway, what's the recommended material/method for these?

sanni, 2022-07-23:
I just fixed the frame.stl, can you please try again.

The n64sleeve.stl I can't fix, it needs 0.4mm thick walls or else the N64 cartridge won't fit over it. Just make sure you get the correct 2.5mm N64 slot, then you won't need it.

Ancyker, 2022-07-25:
They did approve it but it has a warning for the walls only being 0.8mm. I think they want 1mm, but I'll have them print it anyway and see what happens.

Closed 2022-08-19.

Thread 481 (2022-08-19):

Unable to dump SA1 games with Six Slot Adapter Rev1.

splash5, 2022-08-19:
In six slot adapter, snes slot pin 25 connects to D40, but in HW4 or HW3 it connects to CIC_RESET.
After rewiring pin 25 back to CIC_RESET, I can dump SA1 games with HW5 flawlessly.
Is there any reason that pin 25 connects to D40?
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

sanni, 2022-08-19:
You're absolutely right. My mistake. I uploaded a fixed Six Slot Adapter Rev2.

Summary: CIC Reset (marked CR on PCB) was not connected between CIC adapter and SNES slot. Instead D40 was connected both to D40 and CIC Reset. Two cuts to traces need to be made and D40 and CR need to be rewired on Rev1.

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

kamalawala, 2022-08-20:
Wait, so can SA1 games be dumped with HW5 now? How to build wiki page still says the snesCIC adapter hasn't been made yet.

Mythris29, 2022-08-20:
I'm not sure if this is helpful or not but I built the v3 CIC adapter and put it on a rev1 6 slot adapter board and have been able to dump the 1 SA game I have (Super Mario RPG). I've had to reboot 5-6 times in some cases but it does seem to have worked or at least the CRC check passed. I haven't had time to actually try it in an emulator yet.

splash5, 2022-08-21:
@kamalawala I build CIC adapter using universal PCB. You can check [https://github.com/sanni/cartreader/tree/master/hardware/cic_adapter](url) which sanni uploaded last month.

@Mythris29 After I built CIC adapter I first test "Super Mario RPG" but it just not recognized even I reboot about 10 times. After correcting wiring around CIC_RESET all my SA1 games can be correctly detected and dumped without problem (both checksum and CRC32 passed).

TCorgard82, 2022-08-23:
So this was really helpful, I just checked my Rev 1 board and they have this issue, so that might be my issue with SA-1 games. thank you, will update if it fixes my issue.

TCorgard82, 2022-08-23:
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

So the mod got me to read SA-1 games, but I get checksum and CRC32 error, but I took a close up of the PCB and marked the traces to be cut.

Mythris29, 2022-09-17:
Not to necro this topic but has anybody ordered revision 2 and tested it yet? I just got mine a few days ago and I can't dump my SA1 game but I was able to on revision 1 it just took 4-5 times of rebooting for it to work.

I'm testing with Super Mario RPG. I'm able to read non SA1 games just fine but after 20 reboots I still haven't been able to read Super Mario RPG once with my revision 2 six slot on HW5.

TCorgard82, 2022-09-18:
So I think I have rev 1 6 slot, and I had to modify the pcb to get the
right connections to the CIC PCB.

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

KytorIndustries, 2023-02-11:
Thank you this was very helpful, I was able to get CIC working on HW5 rev 1.

Closed 2022-08-24.

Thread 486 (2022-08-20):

Famicom Wars won't write save dump

sanni, 2022-08-20:
### Discussed in https://github.com/sanni/cartreader/discussions/485

<div type='discussions-op-text'>

<sup>Originally posted by **Mythris29** August 20, 2022</sup>
So I think the dump is working for sram on my copy of Famicom Wars because it has info in it if I look at it in a hex editor but I can't seem to write the file back to the cartridge.

I don't get any errors during the process so I'm unsure what the issue is. I have 2 famicom carts and both dump the carts just fine so I don't think the slot and or ver5 cart reader is the issue but I only have a sample size of 2 and only a sample of 1 for this sram issue so I'm unsure if this is a hw5 issue or an issue just with my setup

I'm attaching a copy of the sram dump is case it helps.

[RAM.zip](https://github.com/sanni/cartreader/files/9386408/RAM.zip)
.</div>

PsyK0p4T, 2022-08-25:
Don't know if I can help on anything here, tests or so...
I've a Famicom Wars cartridge here, and hw v3 + FC adapter.

sanni, 2022-08-25:
Would be great if you could play the game until there is a save on the cart. Then dump the save. Then overwrite a copy of the save with 0xFF on all bytes and flash that 0xFF copy back to erase the save in the cartridge. Confirm there are no write errors and that the save is gone when playing the game and then write the backed up save back to the cartridge and confirm that the save is there again when playing the game.

PsyK0p4T, 2022-08-25:
Understood your plan. Unfortunately I have the cart, but not a Famicom to play it.
I can eventually :
- dump the current save, whatever is on it
- Then prepare a 0xFF save. Flash it to the cart.
- Try to dump the save from cart, confirm it is 0xFF
- Flash back the original save.
- Dump it again to confirm the content ?

Mythris29, 2022-08-25:
I'm happy to do this I would just need to know how to prepare a 0xFF save. I have a retron that I can create and test the save with.

Mythris29, 2022-08-25:
[RAM.zip](https://github.com/sanni/cartreader/files/9428767/RAM.zip)

If it's easier to just modify this file and send it back to me that's fine as well (just dumped this save from my cart). But I'd love to learn how to be more helpful testing this so either way is fine with me :)

sanni, 2022-08-26:
> I can eventually

That would work too

PsyK0p4T, 2022-08-26:
@Mythris29 I grabbed your bin file to get the expected RAM size, then made another one fully filled with 0xFF value.
As listed above, the goal would be to flash it to the cart, then read the cart again to confirm 0xFF save it was written fine.
Then upload the original bin save you did. Dump it again, and confirm than old save was written fine.

@sanni Ok i will try it and let you know the results

Mythris29, 2022-08-26:
Writing the 0xFF file didn't erase my save game. (I assume that's what it was supposed to do)

PsyK0p4T, 2022-08-29:
Finally took the time to test this. Here are my results :
- used Famicom Wars (HVC-FW) on hw3 + Famicom-to-SNES adapter + software v9.6
- switches set to NES mode (right left left left)
- game is automatically recognized and info loaded from database
- dumping rom worked
- dumping sram worked : "RAM.bin"
- created a 8KB file "blank.bin" only filled with 0xFF and put it on my sd
- flashed that blank file to the cartridge SRAM
- dumped again the SRAM
- the file obtained was matching "blank.bin"
- then flashed the original save back to SRAM
- dumped again the SRAM
- the file obtained was matching "RAM.bin"

So everything worked as expected from my side. SRAM backup and restore operations had no problem.

Also adding my files here, even if they will not be really useful... can you maybe retry once more by using the blank.bin file @Mythris29  ?
[saves.zip](https://github.com/sanni/cartreader/files/9448378/saves.zip)

Mythris29, 2022-09-05:
Still troubleshooting this but I may need to get my hands on some original famicom hardware to troubleshoot this.

1. Backed up current save on cartridge
2. Wrote blank save to cartridge
3. Backed up save again then compared hex files
4. First backup has data as expected second backup is blank or all 0xFF as expected
5. Put Famicom wars into Retron 5 to play and the save is gone
6. Put Backup save with data back onto the cartridge and did another dump to confirm it's on the cartridge. No save game data is on the cartridge though when I try to play it on the retron. If I look at the CRCs they don't match even though the save data looks similar via hex editor view.

I've disabled save states and save backups on the Retron and wipes it's directories but something still isn't right and I can't rule out the retron might be messing with something but the CRCs not matching is very strange.
[Saves.zip](https://github.com/sanni/cartreader/files/9492283/Saves.zip)

sanni, 2022-09-06:
Judging from PsyK0p4Ts and your test it seems to me like either the battery in the cartridge is empty or the Retron is messing with the save somehow.

Mythris29, 2022-09-07:
Just to leave some useful notes. I got a Famicom to NES adapter today to test this out with and it seems to work perfectly. Even with save states and save backups turned off the retron5 seems to still do strange things with saves and can't be trusted to test saving issues.

Closed 2022-09-06.

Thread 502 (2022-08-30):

Release 9.5 Screen Corruption on 3V HW5 R3

WindyBison, 2022-08-30:
Software
- Release 9.5 (then downgraded to 9.4 to solve the issue)
- Portable method used for flashing the Arduino via the "How to Flash"
- Windows OS used for the Arduino flashing operations

Hardware (PCB from JLPCB and Parts from "What to order" links)
- 2 slot configuration (GBX, N64)
- HW5 R3
- N64 Adaptor
- KeyStudio MEGA PRO 2560
- SI5351 clock generator
- MKS MINI12864 V3 LCD

Please excuse me for I am new to GitHub. If this is not the right place to report issues, I apologize.

5volt worked perfectly, no screen issues and was able to read the ROMs of Tetris (Gameboy) successfully

3volt, however, showed corruption on the letter "b". (attached 2 photos) and would have a checksum error when trying to look up GBA Games from the database file (Tested 3 cartridges, all failed)

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

I decided to re-flash the Arduino with Version 9.4 with NES module disabled and Megadrive disabled in the code

Refreshing the Adrino with Version 9.4 solved the corruption and I was to dump GameBoy, GBA, and N64 cartridges no problem.

Could this be an issue only in release 9.5?

Edit 1: Fixed spelling of Arduino

sanni, 2022-08-31:
Can you try what happens when you reduce the file name character limit in 9.5 again to the same as it was in 9.4?
The setting is found in [Cart_Reader.ino in line 363](https://github.com/sanni/cartreader/blob/master/Cart_Reader/Cart_Reader.ino#L363)

Change:

````
// File browser
#define FILENAME_LENGTH 100
#define FILEPATH_LENGTH 132
#define FILEOPTS_LENGTH 20
````

to:

````
// File browser
#define FILENAME_LENGTH 32
#define FILEPATH_LENGTH 64
#define FILEOPTS_LENGTH 20
````

WindyBison, 2022-08-31:
```
// File browser
#define FILENAME_LENGTH 32
#define FILEPATH_LENGTH 64
#define FILEOPTS_LENGTH 20
```
The above change you suggested resolved the screen letter "b" corruption on version 9.5 while 3V was selected. I was able to dump Bomberman Tournament (GBA) and also read the save

Tested the ROM on mGBA and it worked no problem.

sanni, 2022-09-06:
If you find the time it would be interesting to see when exactly the issue appears. E.g. you could try only changing either #define FILENAME_LENGTH 32 or #define FILEPATH_LENGTH 64 to see which line is causing it. And then once the culprit is found slowly increase the size until it breaks.

Also interesting would be if using shorter cables from the display to the main PCB changes anything.

WindyBison, 2022-09-13:
I had to re-download the latest v9.5 portable release as I deleted the previous one due to cleanup.

Not sure if there were any changes to v9.5 between now and when I opened the issue, but I cannot replicate the issue anymore. (I also did not change anything hardware wise)

To try and replicate the base issue to test out changing FILENAME_LENGTH or FILEPATH_LENGTH, I flashed the Arduino with the latest v9.5 release (on Sept 12) with no edits on FILENAME_LENGTH or FILEPATH_LENGTH and only edited the code to define HW5.

I did not get any screen corruption issues on the letter "b" as before with 3volt.

I also tried disabling all modules but n64, GBX, flash, and flash16 and flashing the Arduino again.

I still was not able to replicate the issue, everything worked just fine for dumping a n64 cart, gba cart, gba save, and Gameboy cart.

Closed 2022-09-18.

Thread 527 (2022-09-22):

Issue dumping Sega Master System Carts with memory paging chip

ccfman2004, 2022-09-22:
Every time I try to dump a Master System cart I get a different CRC value which is not found. I have the HW5 R3 board with the Rev1 Six Slot Board.  The one cart I tried to dump was Mono Poly which is in the database on the SD card but the CRC value is different every time I dump. When I open what is dumped it does have some plaintext that is definitely from the game.

I select SMS and then the first option and click to read rom but each dump yields a different CRC value.

I have no issues dumping SNES games including SA1 games and as far as I can tell the solder joints look good so I'm not quite sure what is wrong.

Also the WIKI NEEDS to be updated with instructions for using the HW5 boards since there are a number of differences between HW3 and HW5.

sanni, 2022-09-22:
Monopoly is one of those special games with a ton of additional chips, it most likely will need some extra code to be dumped correctly.

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

List of more games that use Sega's 315-5208, 315-5235 or 315-5365 memory paging chips:
Action Fighter
After Burner
Alex Kidd in Miracle World
Altered Beast
Astro Warrior
Bubble Bobble
Casino Games
Chase HQ
Galaxy Force
Gangster Town
Ghostbusters
Golden Axe
Hang-On/Astro Warrior
Kenseiden
Mercs
Monopoly
Operation Wolf
Penguin Land
Phantasy Star
R-Type
Rastan
Sagaia
Space Gun
Space Harrier
Spellcaster
The Ninja
Wonder Boy III: The Dragon's Trap
World Grand Prix
Source: https://www.smspower.org/Development/SMSPagingChips

ccfman2004, 2022-09-22:
Of course the 3 games I have are on that list. Although the 3rd game is Hang Out/Safari Hunt not Hang Out/Astro Warrior.

Can I send you one of the games or send it to someone who can help develop the code? I bought the games to make sure the cart reader I was building was 100% working. Had no idea there were games that couldn’t be dumped.

PsyK0p4T, 2022-10-20:
I looked a bit around this. Not sure if it's only due to these games having paging chips embedded, but more that it's hard to detect/predict the exact rom size for SMS/GG.

The current SMS.ino tries to read the info in rom header first, by checking the checksum area value. This often gives a correct size, but not always.
Then makes an additionnal check to see where the "TMR SEGA" string is repeated. This will eventually correct/adjust the rom size and will work for the very large majority of games (Ex : "Double Dragon" or "Super Monaco GP" need this).

But this adjustment sometimes oversizes other games, like the ones you're discussing here. As a temporary solution, I commented the "size fix" part. Try to use the SMS.ino attached and let us know the results. I dumped "Operation Wolf" or "Altered Beast" correctly with it.
But be warned that by using this ino, some other games will now have their size badly detected.

Hope that someone here can figure out an universal trick...

[SMS.zip](https://github.com/sanni/cartreader/files/9827885/SMS.zip)

PsyK0p4T, 2023-02-13:
Just deleted my previous old post here, where I reported issues to dump "Galaxy Force".
I retried today after cleaning the cart once again. And it dumped fine with the current code (v12.2), and all the different adapters tested so far (raphnet, retrode, retron).

The PCB only includes two chips : the MPR-12566A (game) and a 315-5235 (paging).
So "just" a paging chip is not a problem. But Monopoly or others games which contain more chips, could be...

Ancyker, 2023-03-23:
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

PsyK0p4T, 2023-04-11:
@sanni we can probably close this issue ?
Paging chips seem to be out of cause, since I dumped Galaxy Force and Ancyker did Monopoly too.

If @ccfman2004 comes back on this topic, try to update to v12.5 and follow the quick guide posted above to get the expected crc.

Closed 2023-04-11.

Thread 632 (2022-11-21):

[NES] 72-pin slot too shallow for some carts

nsx0r, 2022-11-21:
There are reports of contact issues with some (early?) NES PCB versions that have shorter contact pins, and I can confirm this myself.

bad contact "no data found" when fully inserted:
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
same game, different (newer?) PCB, good dump:
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

It seems like the 72-pin slot isn't deep enough to allow proper contact with these shorter pins.
I'm trying to find a different slot than the one recommended on the wiki, but they all look the same and rarely specify their exact dimensions.

Meanwhile you can *force* the pins to make contact but I don't like pushing/yanking the PCB in the slot and the results are random.

Stanton54, 2022-12-13:
I had an issue like this with my dragon warrior and when I took off the back screws it worked for my v5.

MattroidPrime, 2022-12-17:
I too had this issue with my Dragon Warrior cart along with a couple of others. While the others I was able to dump by holding down on the cart with a bit of force, The DW cart just wouldn't have it, even when removed from the shell. I ended up getting an adapter board and pushing the back row of pins up using a pair of needle nose pliers just to the edge of the socket before soldering it to the board (I pushed all the back pins up even though they're not all necessary for this particular game which is all I needed it for but hey, I was on a roll).

It still took a bit of fiddling but my v5 finally auto-recognized the cart and I eventually managed to get successful ROM and SRAM dumps.

If I do another full build at some point, I might just push those pins up from the start unless another socket can be found by then.

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

Cephiros, 2023-02-04:
I did this on my second build, i cut the stands off so the connector was flush with the board and pushed all the back pins up to sticking up about 1mm above the top. Reads everything without an issue. If you add this as a step in the build process wiki, you can probably close this, otherwise I wouldnt count on a fixed slot from the famiclone producers.

PeteCologne, 2024-08-01:
The EUR Version of Megaman 1 PAL B also doesn't work. It's an UNROM-08 pcb https://nescartdb.com/profile/view/1416/mega-man - the only game of my collection. Rest works great.

Closed 2023-02-10.

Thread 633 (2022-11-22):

NP GB Flashcart

dannygonzalez0861, 2022-11-22:
Hi,

I am having an issue flashing to a Nintendo Power Gameboy memory Cartridge.

I purchased the cartridge with only one large ROM file so I had to start from scratch. I am trying to load Pokemon Blue alone w/o the menu but when I try and flash the ROM or MAP files, the Cart reader reboots.

When I "Erase Flash" I get the warning message and press to confirm, the next page shows Erasing... but no "OK" and then asks to press the button.

Next, I Blankcheck which immediately says "Blankcheck...OK" and asks to press the button to continue..

Pressing Read Flash and Read Mapping, generate corresponding files in the NP folder of the SD card.

Please help me, literally purchased this cart and built your reader for each other.

Thanks!

Daniel G.

sanni, 2022-11-22:
Try updating to [V11.4](https://github.com/sanni/cartreader/archive/refs/heads/master.zip)

dannygonzalez0861, 2022-11-22:
> Try updating to [V11.4](https://github.com/sanni/cartreader/archive/refs/heads/master.zip) And if that doesn't fix it you can disable some modules that you don't need and see if that resolves the issue.

Hello,

So I am writing this for future reference but to save those who don't care, yes this V11.4 did indeed work with the NP GB Memory Cart and the menu allowed me to select the appropriate files on the SD card.

Well to dive into what I did, my Arduino is modified (Fuse removed) so I simply left it installed on the main board and powered it on via USB as normal. I then followed the steps to flash a new Arduino as on the instructions but the files above do not contain the libraries nor portable IDE so I simply installed a fresh copy of IDE and used the libraries folder found in the prior (V10) version. Note I had to transfer the files from the download location to the Arduino IDE files in the My Documents Folder, again the instructions page was extremely helpful here in finding the location of the folders in question (The bottom of the page describes IDE standalone install vs. Portable). After IDE updated the libraries and added the Cart_.... file to IDE I defined v5, installed drivers, and selected the board and port verbatim to the instructions. I did remove a few unused modules as well but my prior version also excluded these modules so I do not think that was the issue. Once flashed the Arduino and the screen rebooted and like magic, I was able to erase the flash, Blankcheck...OK and then when writing to the GBMC instead of rebooting as before, I am welcomed to a file browser and allowed to select the appropriate ROM and MAP files.

All is well in my world again and I want to formally thank you Sanni for the assistance, the project, and the joy it has been to put together and get working.

Thanks!

Daniel G.

Closed 2022-11-22.

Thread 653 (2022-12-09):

Sega Genesis/Master Drive /Cart - D40 Pin Issue

dannygonzalez0861, 2022-12-09:
Hi Sanni,

I think I might have just discovered an issue with the six-slot PCB Rev. 3.

I have been trying, w/o success, for the past week to get Mega Drive/Genesis Carts to read but the moment I plug one in and try to turn the reader on, it just stays off. I disconnect the game and try again and the reader powers on like usual. If the reader is powered on and I try to connect the game, it just shorts out and turns off.

I had a bit of free time and decided to see if I could find a short on my PCB but did not find a defect from my soldering. Well after a few hours of testing/probing for shorts and looking over your schematics/ Sega PCBs I physically have, I noticed that D40 which has continuity to VCC goes connected to the /cart pin of the genesis port which on all of my games is actually a ground pin.

I confirmed the result by applying a piece of tape to the /cart pin to avoid getting VCC to the pin as it shares ground on the game itself and the reader stays on as well as successfully pulls the ROM and passes the checksum.

Can you confirm if this is a one-off or a design issue?

dannygonzalez0861, 2022-12-09:
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

Ancyker, 2022-12-09:
D40 should not have continuity to VCC.

Ancyker, 2022-12-09:
I was looking over the PCB layouts and the only place I see D40 ever getting close enough to VCC that it could accidentally be bridged is on the CIC adapter:

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

dannygonzalez0861, 2022-12-13:
I can't seem to find where the short on this board is. It is not on the CIC unfortunately, I disconnected the board as a quick test and the short still exists. I half-built a second unit over the weekend with the spare parts I had and it does not present these issues. It must be a one-off problem with this PCB.

Thanks for the help!

Ancyker, 2022-12-13:
I think I had a similar issue with my first one. It was caused by a bridge
under one of the headers. You could try reflowing all the headers to see if
it helps.

On Tue, Dec 13, 2022, 12:58 PM dannygonzalez0861 ***@***.***>
wrote:

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

dannygonzalez0861, 2022-12-30:
Well, i though i would share what I found was the issue after all. I have no idea how this happened but the header for the SNES_CIC PCB was shorted almost completely. Not sure if I had a few too many that day but here is what I found when I started to disect the PCB, hope you all can laugh at my pain LMAO
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

@Ancyker your help was much appreciated, all of your ideas were indeed acurate and I just needed to fins exactly where the isse was.

Thanks!

Closed 2022-12-13.

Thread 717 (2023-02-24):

GB(C): Add support for EEPROM save (Kirby Tilt 'n' Tumble/Koro Koro Kirby)

PW5190, 2023-02-24:
Hey there. I recently got my hands on the Open Source Cartridge Reader. I put Kirby Tilt 'n' Tumble into the Game Boy slot, and I was able to dump the ROM. But, when I attempted to backup the save file, I get an error message.

```
Cart has no Sram

Press Button...
```

Any chance this issue can be fixed? I really need to backup my save file. As far to my knowledge, this is one of the few Game Boy (Color) games to not use battery-backed SRAM for saving, and instead utilizing EEPROM. And this is one of two Game Boy Color games to have a tilt sensor. The other game that has it is Enix's Command Master.

Trust me, I followed the guide on the PCB. Made sure the voltage switch was in 5V, and the EEP, CLK0, and CLK1 switches are off. Do I also need to turn the EEP switch on, since the cart used EEPROM?

sanni, 2023-02-25:
There currently is no code to read/write eeprom in GB.ino.
If you wanna give it a try yourself here is the needed information about the eeprom: https://gbdev.gg8.se/wiki/articles/MBC7#Ax8x_-_EEPROM_.28Read.2FWrite.29

Closed 2023-06-08.

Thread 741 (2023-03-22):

Order list mistake?

BenoitCaron, 2023-03-22:
I recently purchased all the items on the list, assembled my cart reader, and realized those long male pin headers are actually too long?

```
Male pin headers:
two 1x40 2.54mm 20mm long(total length)
```

The PCB can't sit flush with the 18mm spacers, because male pin headers + female pin header combined are 18.5mm. I triple checked, I did order according to the list, my male pin headers are indeed 20mm long.

At that point, I would advise either to change the list to 19mm long spacers, or 19mm long male pin headers :)

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

Ancyker, 2023-03-22:
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

Ancyker, 2023-03-22:
Mine is like that too, I just screwed it down anyway 🤷‍♀️

Ancyker, 2023-03-22:
I think it's fine, but I also didn't wrench them down super tight; I just made them snug on both sides; there's still a tiny gap.

Ancyker, 2023-03-22:
@sanni  I checked a few, and with the variance, I think increasing it more might lead to being too short at 19mm. I don't think that will affect usage, but I'm not sure. Since washers are on the list, anyone concerned could just add washers between the PCB and standoffs...

BenoitCaron, 2023-03-22:
Huh, that's strange, I had the feeling that it could be shortened even more, like 18mm pins wouldn't be an issue :o

Ancyker, 2023-03-22:
If you are super concerned, you can just put a washer between the top PCB and standoff. I just didn't tighten them all the way, but if you are worried about it, then it's an option. If you bought everything on the list, you likely have a huge pack of washers sitting around doing nothing anyway, lol.

BenoitCaron, 2023-03-22:
Maybe we misunderstand each other. My only concern is the flex. I'm not concerned about shortening the pins (which I did) nor using washers. I'm designing a shell that I might release. If people use my shell, I'll need them to have the exact same height as I do, and the more reliable way to have the same height, in my opinion, is to use shorter pins, as different washer might vary in height. Either way, both solutions are perfectly valid I think :)

Ancyker, 2023-03-22:
The washers are nice because of the material they are made of they do compress a little unlike metal. This means you can get a pretty reliable height out of them. None of these things are super high tolerance, though. These are cheap parts from China. I'd expect a 0.1-1mm variance on both the standoffs and headers. Hell, I've accidentally pushed the header pins through their plastic holder.

1-2mm shouldn't affect your housing as long as you design it for the max height/worst case, as either way, the cutouts for the slots need to allow the entire cart to pass through. You shouldn't design it so that the housing is touching the PCB. There's a reason no consoles (that I know of, at least) do that. Even the GBA isn't completely flush.

BenoitCaron, 2023-03-22:
You have a point.

Ancyker, 2023-03-22:
Also, what is your housing doing differently? There's already a full-enclosure available if that's what you wanted.

I'd like to see one for SLA, as I don't have an FDM printer, and I'll be getting an SLA printer soon. But resin doesn't melt; it burns, so it will need a different design for mounting the LCD.

BenoitCaron, 2023-03-22:
My printer's bed is 150mm long, so I can't print the ones that I have found so far, which are a tad too long. Plus, I'm often not satisfied with the models I find, and try to make my own both as practice and to get better results than current offerings :)

Ancyker, 2023-03-22:
Ah, that's fair. The one someone posted a few weeks ago (#723) is a bit larger @ ~162mm. The printer I'm looking at is 250x123x219mm (HWD, supposedly, but I'm pretty sure they meant WDH, though I'm not totally sure).

The OSCR has seemed a bit chunky looking when it has fully enclosed housing on it. I'm interested in seeing what you come up with. ☺

Ancyker, 2023-03-22:
I saw a cart reader with this housing on eBay:

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

It looks smaller like it would fit on your printer, but as far as I know, the creator did not make the files available. Still, could be used for inspiration, perhaps.

BenoitCaron, 2023-03-22:
Yep, this one would most definitely fit ! But I'm almost done, so I don't think I will draw much inspiration from it :/
At first glance I though "oh the 3V and 5V labels are a smart addition", but then remembered that the software actually tells you which cartridges are 3V.
Thanks for sharing this!

Ancyker, 2023-03-22:
Yeah, I'm pretty sure that was listed/created before the software said that. Also, if you use Vselect, you don't even have a voltage switch, lol.

I put my N64 controller port in a different place as well.

BenoitCaron, 2023-03-22:
I wanted to put it in the back near the GBA port, on the site. I was almost perfect, but ultimately just too tight.

Ancyker, 2023-03-22:
I put mine on the side under the six-slot, lol.

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

Also, now that you mentioned the flex, I can't unsee it 😅

BenoitCaron, 2023-03-22:
Yeah that's exactly what I wanted to do, but on the opposite side ;)
Hope you still have those spacers somewhere :D

Closed 2023-03-23.

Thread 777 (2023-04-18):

Flashrom Progammer : Can't flash + Menu error 255

Slyazku, 2023-04-18:
When using the flashrom PCB adapter with a 29L3211 inside, plugged into the SNES port, I've got no result.
Blanckcheck, reading, etc takes 0sec and dumped files are blank.
When the first operation is complete, and after "Press Button..." prompt, I've got a
"MenuError
Mode = 255
Press BUtton..."
Then to the tiel screen.

Did someone managed to flash a flashchip with 12.4 HW5 ?

Thanks !

sanni, 2023-04-20:
There was an error in the menu resulting in the flash ID function being skipped. Fixed now.

Also since there are currently no HW4/5 flash adapters you have to modify the HW3 adapter:
- cut the trace going to SNES CPU Clock and rewire Flashrom OE to SNES CS
- cut the trace going to SNES IRQ and rewire Flashrom WE to SNES WR

(you need to scratch away the solder mask of the edge connector pins to expose the copper to solder to)

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

sanni, 2023-04-20:
You can update to the current github code like explained here: https://github.com/sanni/cartreader/wiki/Troubleshooting#updating-to-the-latest-github-code

Slyazku, 2023-04-21:
Thanks !
I may be late but did you plan to make the eeprom  section appear again in the wiki, since the menu is able to do it ?

sanni, 2023-04-22:
You can always enable the eprom menu option by setting #define enable_FLASH16 in [config.h line 108](https://github.com/sanni/cartreader/blob/master/Cart_Reader/Config.h#L108)

I have updated the [M27C322 wiki entry](https://github.com/sanni/cartreader/wiki/M27C322-Adapter) with the notion that it doesn't work, just so people don't order it and get disappointed.

Closed 2023-04-21.

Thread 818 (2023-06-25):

vSelect not working beyond 12.4 - stuck on 3.3v

PsychoFox11, 2023-06-25:
I know 12.4 is the latest stable release, but wanted to note this as I've been using 12.5 and now 12.6. I just got a new Sanni with vSelect in addition to the one I already had (both HW5). I always comment out the line to enable vSelect in the appropriate file (different place in 12.4 than later). I'm enabling that, clockgen, and 4 additional systems for adapters.

Using a multimeter, the voltage only ever switches to 5v when using 12.4. Anything later, 12.5 or 12.6, and it stays at 3.3. I've tested this on the Coleco and Intellivision adapters while dumping a real cart. I've tested this on the SNES and Genesis slots while dumping with an empty slot (easier to get to with the multimeter). It only goes to 5v on 12.4.

It isn't especially apparent as many of the built-in slots that are 5v still usually give decent dumps at 3.3v. I have tried SNES and NES and they dumped just fine. I also tried them in my older one with the physical switch set to 3.3v and they dumped fine there as well. Probably not the best for them, but they don't make the issue obvious.

However, Intellivision and ColecoVision will not give me consistent CRC32 at all, unless I use 12.4, or my older HW5 with the manual voltage switch. They seem to really need 5v. Just trying all my adapters, Game Gear, PCE, and Atari gave me good dumps (only tried one cart each) at 3v as well. So even if you're getting good dumps, and have vSelect, you should probably stick with 12.4 until this is changed, for any 5v systems. At least test with a multimeter, as I doubt it is any issue with my setup, given that 12.4 works. I think it would affect everyone.

To note how I'm flashing 12.5/6, I'm downloading the file at:
https://github.com/sanni/cartreader/archive/refs/heads/master.zip
Using a 12.5 that was there a few days ago, and now the current version which reports 12.6. Tested those plus the official 12.4 release.

I'm replacing the contents of my portable/sketchbook/Cart_Reader folder with the contents of the above file's Cart_Reader folder, then launching the Arduino software, setting my config options, and flashing.

By the way I've checked and reflashed back and forth a lot and am positive I'm uncommenting the line to enable vSelect every time, and recommenting it for my older reader. I've verified the heck out of that, unless more than one line needs uncommented in 12.5/6 that I'm missing.

sanni, 2023-06-26:
Can you try the latest commit?  I moved the automatic voltage switching forward in the code so it now switches in the setup function instead of the menu function of the module.

Ancyker, 2023-06-26:
This is now fixed. I made the image below to explain what the issue was, for anyone curious:

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

I probably shouldn't have used "volts" as the input, I should change that to something like "requestedVoltage" or "newVoltage" as that would have likely made the issue more clear. My fault, this is why what you name variables is important and I definitely know better 😅

Closed 2023-06-26.

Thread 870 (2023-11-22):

Vselect doesn't work as expected

Snkfear, 2023-11-22:
### OSCR firmware version

13.1

### OSCR hardware version

HW5 Rev5

### Attach OSCR_LOG.txt file here

_No response_

### System used

all/none/doesn't matter

### Describe the issue.

I've populated everything like the wiki says but when I do the last test, Pin 8 doesn't switch to 3.3V it remains 5V.
When I poer on the system, I measure the expected voltages:
Pin 6 and GND -> 5V
Pin 8 and GND -> 3.3V
Pin 7 and GND -> 3.3V
Once I select "Mega Drive/Genesis" :

Pin 6 and GND -> 5V
Pin 8 and GND -> 3.3V (should be 5V)
Pin 7 and GND -> 3.3V

All smd components are soldered as they should and there isn't any bridge between the legs of the IC.

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

What else should I check?

sanni, 2023-11-23:
I don't use Vselect myself so I can't really help but to me it sounds like a typo in the Wiki.

Pin 8 is a voltage input so it should always be 3.3V.
Pin 7 should be 3V in the main menu and 5V after Mega Drive/Genesis->Game Cartridge was chosen.

Can you check the voltage on pin 7 again after Mega Drive/Genesis->Game Cartridge was chosen?

Snkfear, 2023-11-23:
Yeah, like you said, it was a typo on the Wiki. It's working great and I've dumped GBA/GBC game without issues.

The only thing that annoys me is that the menu isn't displayed correctly.

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

But as you can see on the last photo, some menus are displayed perfectly.

sanni, 2023-11-25:
Is there a pattern like it only happens with 3V systems but 5V systems are ok?

The Vselect by default switches the Cart Reader to 3V and only after a 5V system has been setup it switches to 5V.
In case of Mega Drive, the "Mega Drive Reader" menu would be the first menu where the Cart Reader running at 5V.
By this logic the menu should be ok again e.g. when you select Game Boy (Color).

If this is the case then it might be that your Mega Pro can't run at 3V. This seems to happen more frequently in the last years.

Snkfear, 2023-11-25:
You nailed it!

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

This is weird because I ordered the mega with a row of 5 smds according to the Wiki... and I've dumped GBA and N64 games that work without issues.

Ancyker, 2023-11-25:
@Snkfear try enabling 3V3FIX in the config. It might help as I wrote it to try to address the 3.3V issue but no one has reported if it helps or not.

```c
/* [ 3.3V Stability Fix (3V3FIX) ---------------------------------- ]
    Enable this if you are having stability issues when using 3.3V,
    works best with VSELECT.

    If not using VSELECT, always turn the cart reader on with the
    voltage switch set to 5V and switch to 5V before selecting a
    cartridge from the menu.
*/

#define ENABLE_3V3FIX
```

Snkfear, 2023-11-26:
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

The fix solved my problem!

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

I had to remove the mega and bridge the fuse because the board was restarting every time the ide started uploading the sketch... I guess it's because of the Vselect.

By the way, would  be great to add test points for the TPS in future hardware revisions, it was a nightmare to test each leg for shorts.

Closed 2023-11-26.

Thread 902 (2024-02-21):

Handling of GAME and EXROM lines of C64 cartridges is wrong

pdaehne, 2024-02-21:
### OSCR firmware version

all versions affected

### OSCR hardware version

HW5 Rev6

### Attach OSCR_LOG.txt file here

_No response_

### System used

all/none/doesn't matter

### Describe the issue.

The handling of GAME and EXROM lines of C64 cartridges is wrong (in C64.ino). The code configures the lines as output (going from the cartreader to the cartridge), and pulls the lines up or down. Actually, these lines are inputs, going from the cartridge to the cartreader. They are pulled to GND on the cartridge or left open to tell the C64 which memory configuration the cartridge uses (8k cartridge, 16k cartridge, Ultimax cartridge, C128 cartridge). See the schematics in the following link for more information (blog post "Making a C64 Cartridge" on "World of Jani"):

http://blog.worldofjani.com/?p=879

So currently, when the cartridge pulls these lines to GND and the code tries to pull them high, a direct short is created. I do not know how robust the output pins of the Mega 2560 are, but this does not seem to be a good idea.

I'm willing to create a pull request which removes the whole GAME/EXROM code from C64.ino, but I would like to get a "go" first before I put some effort into this.

BTW, I cannot select "C64" in the "System used" drop down of this issue, the template needs to be extended.

sakman55, 2024-04-26:
I've made the changes to the handling of the GAME and EXROM lines.

I still have to test the modified code with Normal and Ultimax carts.

If everything works as expected, I'll update the sketch in the repository.

Thanks for posting the info on the issue!

pdaehne, 2024-04-26:
Thanks for working on this issue @sakman55.

Unfortunately, there is an even worse problem with the adapter PCB. The C64 cartridge line PHI2 (pin E) is crucial for more complex cartridges that use bank mapping. PHI2 is a delayed copy of the CPU clock, but more importantly it tells external components when the CPU address and data lines as well as R/W and other signal lines are stable/valid (namely at the falling edge of PHI2). PHI2 is not needed for simple 8K/16K cartridges that can only be read from, but needed when writing to a cartridge, e.g. when setting bank registers.

Currently, pin E of the cartridge is connected to pin 57 of the SNES connector, which in turn is connected to CLK1 of the SI5351 clock generator. Since a few days there is a commit 4c8f826 by @smesgr9000 which initializes the clock generator, but what is the point of a clock signal which is completely out sync with all the other lines controlled by the Atmega? In my opinion, the adapter PCB needs to be changed to connect PHI2 to a regular Atmega output, and the code needs to toggle that output after setting the address and R/W lines.

sakman55, 2024-04-26:
Control of the CPU clock line depends on the HW version.  Older HW versions included a switch that allowed manual control of the clock line.  For newer HW versions, users have been able to configure the clock generator to provide the necessary signals needed by other systems.

smesgr9000, 2024-04-27:
yeah I'm also not happy with the clock gen stuff. I have the gut feeling this messes up dumping with other systems too. Couldn't proof it yet. But what to do? Without the code dumping of back switch games does not work on HW5.

sakman55, 2024-04-27:
One thing to keep in mind is that we don't need cycle accurate emulation of the clock.  For the most part, the clock just needs to be close enough to get the cart to respond.

For instance, I'm currently working on the Atari 8-bit carts and the XE bankswitch only needs a single clock pulse to latch the bank.  Another system that I worked on recently was the TI-99 that only needs a short sequence of pulses to latch the GROM address.  For these systems, the manual clock signal is only called when needed.

A recommendation that I would make for the HW versions that don't have the manual CPUCLK switch is to disable the clock generator line and only enable it for the routines that need it.  This could also prevent random effects due to the clock running out of sync where it isn't needed.

The change to the dedicated clock generator connection is not something that I would have adopted since we lose the ability to finely control the clock pulses.  I mainly worry about breaking support for serial EEPROMs.

A solution might be to adjust the clock frequency to where an enable/disable cycle equates to a single clock pulse.  If it could be timed right, then an enable/disable cycle can be invoked when we need a clock pulse (basically acting like a manual pulse).

sakman55, 2024-04-27:
I redumped all of my C64 carts (Normal, Ultimax, Ocean) and they all dump properly with the new code.

I'll update the C64.ino later today.

The c64cart.txt for the SD card will also need to be replaced since we eliminate the port state from the file.

smesgr9000, 2024-04-28:
I can confirm my few cards are working to.

pdaehne, 2024-04-28:
@sakman55: Why did you remove the information about the EXROM/GAME lines from the database? That's valueable information which could be used to filter the cartridges in the selection menu...

sakman55, 2024-04-28:
It wasn't needed anymore since we read the port state from the cart.

There's no stopping someone from adding the info back if they write code to filter the cart list by port state.

I can't see an overall benefit with saving a little time scrolling the cart list versus adding code to do the filtering.

As an alternative, you could probably achieve similar results by filtering by mapper.

Closed 2024-07-14.

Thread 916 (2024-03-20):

Support for Atari 7800 Bankset Bankswitch (needs adapter update)

smesgr9000, 2024-03-20:
### OSCR firmware version

main 2024-03-24

### OSCR hardware version

HW5 Rev1

### Attach OSCR_LOG.txt file here

_No response_

### System used

all/none/doesn't matter

### Describe the issue.

I have extended the current code to support Bankset Bankswitch
http://7800.8bitdev.org/index.php/Bankset_Bankswitching

needs some hardware modification on the adapter. Currently @sakman55  7800 adapter has HALT not wired in v0.1. Thus I used a jumper wire 7800 /HALT (pin 2) to SNES /RST (Pin 26)
I have also added some additional NOPs at write bank switching code. Without switch those 16k was not reliable for me. Those seems to be more stable now for me - also for normal supercard games.
I have successfully dumped Petscii robot with the diff below.

```diff --git a/Cart_Reader/7800.ino b/Cart_Reader/7800.ino
index c8584f0..73078a2 100644
--- a/Cart_Reader/7800.ino
+++ b/Cart_Reader/7800.ino
@@ -44,6 +44,7 @@
 // CONTROL PINS:
 // CLK(PH1) - SNES CPUCLK
 // R/W(PH6) - SNES /RD
+// HALT(PH0) - SNES /RESET

 //******************************************
 //  Supported Mappers
@@ -58,9 +59,10 @@ static const byte PROGMEM a7800mapsize[] = {
   4, 4, 4,  // Double Dragon/Rampage 128K [78AC]
   5, 3, 3,  // Realsports Baseball/Tank Command/Tower Toppler/Waterski 64K [78S4]
   6, 3, 3,  // Karateka (PAL) 64K [78S4 Variant]
+  7, 1, 4,  // Bankset switching
 };

-byte a7800mapcount = 7;  // (sizeof(a7800mapsize) / sizeof(a7800mapsize[0])) / 3;
+byte a7800mapcount = 8;  // (sizeof(a7800mapsize) / sizeof(a7800mapsize[0])) / 3;
 byte a7800mapselect;
 int a7800index;

@@ -96,7 +98,7 @@ void setup_7800() {
   DDRL = 0xFF;

   // Set Control Pins to Output
-  //       ---(PH0)   ---(PH3)   ---(PH4)   ---(PH5)   R/W(PH6)
+  //       HALT(PH0)  ---(PH3)   ---(PH4)   ---(PH5)   R/W(PH6)
   DDRH |= (1 << 0) | (1 << 3) | (1 << 4) | (1 << 5) | (1 << 6);

   // Set TIME(PJ0) to Output (UNUSED)
@@ -106,7 +108,7 @@ void setup_7800() {
   DDRC = 0x00;

   // Setting Control Pins to HIGH
-  //       ---(PH0)    ---(PH3)   ---(PH4)   ---(PH5)   R/W(PH6)
+  //       HALT(PH0)   ---(PH3)   ---(PH4)   ---(PH5)   R/W(PH6)
   PORTH |= (1 << 0) | (1 << 3) | (1 << 4) | (1 << 5) | (1 << 6);

   // Set Unused Data Pins (PA0-PA7) to Output
@@ -263,7 +265,32 @@ void writeData_7800(uint32_t addr, uint8_t data) {
   NOP;
   NOP;
   NOP;
+  NOP;
+  NOP;
+  NOP;
+  NOP;
+  NOP;
+  NOP;
+  NOP;
+  NOP;
+  NOP;
+  NOP;
   PORTH |= (1 << 6);  // R/W(PH6) HIGH = READ
+  NOP;
+  NOP;
+  NOP;
+  NOP;
+  NOP;
+  NOP;
+  NOP;
+  NOP;
+  NOP;
+  NOP;
+  NOP;
+  NOP;
+  NOP;
+  NOP;
+  NOP;

   DDRC = 0x00;  // Reset to Input
 }
@@ -321,20 +348,11 @@ void readROM_7800() {

   switch (a7800mapper) {
     case 0:  // Standard 16K/32K/48K [7816/7832/7848]
-      if (a7800size > 1)
-        readSegment_7800(0x4000, 0x8000);  // +16K = 48K
-      if (a7800size > 0)
-        readSegment_7800(0x8000, 0xC000);  // +16K = 32K
-      // Base 16K
-      readSegment_7800(0xC000, 0x10000);  // 16K
+      readStandard_7800();
       break;

     case 1:  // SuperGame 128K [78SG]
-      for (int x = 0; x < 7; x++) {
-        writeData_7800(0x8000, x);         // Banks 0-6
-        readSegment_7800(0x8000, 0xC000);  // 16K * 7 = 112K
-      }
-      readSegment_7800(0xC000, 0x10000);  // Bank 7 +16 = 128K
+      readSupergame_7800();
       break;

     case 2:                              // SuperGame - Alien Brigade/Crossbow 144K [78S9]
@@ -392,6 +410,24 @@ void readROM_7800() {
         readSegment_7800(0x8000, 0xC000);  // 16K * 4 = 64K
       }
       break;
+
+    case 7: // Bankset switching
+      if (a7800size > 3) {
+        setHalt_7800(1);
+        println_Msg(F("READ Supergame"));
+        display_Update();
+        readSupergame_7800();
+        setHalt_7800(0);
+        println_Msg(F("READ Supergame"));
+        display_Update();
+        readSupergame_7800();
+      } else {
+        setHalt_7800(1);
+        readStandard_7800();
+        setHalt_7800(0);
+        readStandard_7800();
+      }
+      break;
   }
   myFile.close();

@@ -405,6 +441,38 @@ void readROM_7800() {
   wait();
 }

+void readStandard_7800() {
+  if (a7800size > 1)
+    readSegment_7800(0x4000, 0x8000);  // +16K = 48K
+  if (a7800size > 0)
+    readSegment_7800(0x8000, 0xC000);  // +16K = 32K
+  // Base 16K
+  readSegment_7800(0xC000, 0x10000);  // 16K
+}
+
+void readSupergame_7800() {
+  for (int x = 0; x < 7; x++) {
+    writeData_7800(0x8000, x);         // Banks 0-6
+    readSegment_7800(0x8000, 0xC000);  // 16K * 7 = 112K
+  }
+  readSegment_7800(0xC000, 0x10000);  // Bank 7 +16 = 128K
+}
+
+void setHalt_7800(byte on) {
+  if(on == 1) {
+    PORTH |= (1 << 0);  // HALT(PH0) HIGH = SALLY
+  } else {
+    PORTH &= ~(1 << 0); // HALT(PH0) LOW = MARIA
+  }
+  NOP;
+  NOP;
+  NOP;
+  NOP;
+  NOP;
+  NOP;
+  NOP;
+}
+
 //******************************************
 // ROM SIZE
 //******************************************
@@ -560,6 +628,8 @@ void checkStatus_7800() {
     println_Msg(F("BASEBALL/ETC [78S4]"));
   else if (a7800mapper == 6)
     println_Msg(F("KARATEKA(PAL)[78S4]"));
+  else if (a7800mapper == 7)
+    println_Msg(F("BANKSET"));
   print_Msg(F("ROM SIZE: "));
   print_Msg(a7800[a7800size]);
   println_Msg(F("K"));
@@ -582,6 +652,8 @@ void checkStatus_7800() {
     Serial.println(F("Realsports Baseball/Tank Command/Tower Toppler/Waterski [78S4]"));
   else if (a7800mapper == 6)
     Serial.println(F("Karateka (PAL) [78S4 Variant]"));
+  else if (a7800mapper == 7)
+    Serial.println(F("Bankset"));
   Serial.print(F("ROM SIZE: "));
   Serial.print(A7800[a7800size]);
   Serial.println(F("K"));
@@ -637,6 +709,8 @@ void setMapper_7800() {
         println_Msg(F("BASEBALL/ETC  [78S4]"));
       else if (a7800mapselect == 6)
         println_Msg(F("KARATEKA(PAL) [78S4]"));
+      else if (a7800mapselect == 7)
+        println_Msg(F("BANKSET"));
       display_Update();
       if (i == (a7800mapcount - 1))
         i = 0;
@@ -665,6 +739,8 @@ void setMapper_7800() {
         println_Msg(F("BASEBALL/ETC  [78S4]"));
       else if (a7800mapselect == 6)
         println_Msg(F("KARATEKA(PAL) [78S4]"));
+      else if (a7800mapselect == 7)
+        println_Msg(F("BANKSET"));
       println_Msg(FS(FSTRING_EMPTY));
 #if defined(ENABLE_OLED)
       print_STR(press_to_change_STR, 1);
@@ -702,6 +778,8 @@ void setMapper_7800() {
         println_Msg(F("BASEBALL/ETC  [78S4]"));
       else if (a7800mapselect == 6)
         println_Msg(F("KARATEKA(PAL) [78S4]"));
+      else if (a7800mapselect == 7)
+        println_Msg(F("BANKSET"));
       println_Msg(FS(FSTRING_EMPTY));
 #if defined(ENABLE_OLED)
       print_STR(press_to_change_STR, 1);
@@ -738,6 +816,8 @@ void setMapper_7800() {
         println_Msg(F("BASEBALL/ETC  [78S4]"));
       else if (a7800mapselect == 6)
         println_Msg(F("KARATEKA(PAL) [78S4]"));
+      else if (a7800mapselect == 7)
+        println_Msg(F("BANKSET"));
       println_Msg(FS(FSTRING_EMPTY));
 #if defined(ENABLE_OLED)
       print_STR(press_to_change_STR, 1);
@@ -770,7 +850,8 @@ setmapper:
   Serial.println(F("4 = Double Dragon/Rampage [78AC]"));
   Serial.println(F("5 = Realsports Baseball/Tank Command/Tower Toppler/Waterski [78S4]"));
   Serial.println(F("6 = Karateka (PAL) [78S4 Variant]"));
-  Serial.print(F("Enter Mapper [0-6]: "));
+  Serial.println(F("7 = Bankset"));
+  Serial.print(F("Enter Mapper [0-7]: "));
   while (Serial.available() == 0) {}
   newmap = Serial.readStringUntil('\n');
   Serial.println(newmap);
```

PsyK0p4T, 2024-03-20:
Hey, thanks for that !
Could you attach the full 7800.ino file please ? and some pics of your adapter once modified, it could help people to do the same :)

sakman55, 2024-03-21:
Updated Gerbers uploaded (UNTESTED):  [Atari 7800 Adapter v0.2.zip](https://github.com/sanni/cartreader/files/14680657/Atari.7800.Adapter.v0.2.zip)

PsychoFox11, 2024-03-21:
I would like a pic - I don't know the first thing about Gerber files, but if someone could explain the modification to me or show pics, I've got a few carts this would likely help

smesgr9000, 2024-03-22:
> Updated Gerbers uploaded (UNTESTED): [Atari 7800 Adapter v0.2.zip](https://github.com/sanni/cartreader/files/14680657/Atari.7800.Adapter.v0.2.zip)

great thanks :)

smesgr9000, 2024-03-22:
> Hey, thanks for that ! Could you attach the full 7800.ino file please ? and some pics of your adapter once modified, it could help people to do the same :)

please either download the file and do in your local repository:
git apply patch.diff
or copy the stuff via button into your clipboard and do, paste clipboard, enter and CTRL+D
git apply -

PsychoFox11, 2024-03-22:
@sakman55 Are you adding this to the ino permanently as well, since you updated the gerbers? Viewing the diff I could make a good guess but worried I'll make a mistake there and don't use git myself currently. Also not sure what version that diff applies to as I'm always on the latest nightly build and sometimes an ino from 2 days ago won't work anymore.

Sharing the full one should just be a drag and drop if it isn't too much to ask, but if it gets merged into the project, that works too!

sakman55, 2024-03-23:
> @sakman55 Are you adding this to the ino permanently as well, since you updated the gerbers? Viewing the diff I could make a good guess but worried I'll make a mistake there and don't use git myself currently. Also not sure what version that diff applies to as I'm always on the latest nightly build and sometimes an ino from 2 days ago won't work anymore.

Sorry, no.  I'm not running the latest version.

smesgr9000, 2024-03-23:
@PsychoFox11 I created a pull request. Maybe that is easier for you? With this I also removed two additional debug lines still left in the above diff.

PsychoFox11, 2024-03-23:
Thanks, I just want to be sure I get it right and haven't used git for actual coding in about a decade!
Hopefully it can be merged in, though I'd still love to see a pic of that bodge. I understand the instructions and can count pin numbers haha, but it is always good to see just to ensure that like we aren't referring to pins somehow differently or anything.

PsyK0p4T, 2024-03-24:
Fix merged ! I don't have retail carts anymore under my hands so... I can't test if it brokes anything, I'm relying on you ^^
Yup as PsychoFox said, a picture of the adapter fix would be welcome :)

smesgr9000, 2024-03-24:
i have tested one 32k, 48k game and one "supergame". The bankset with normal is not tested atm, because afaik there is no cartridge yet.
I close this issue

PsychoFox11, 2024-03-29:
@smesgr9000  I bodged mine and testing with Pescii Robots. Can you tell me what the proper CRC32 you got was? Or the header user to test the dump? I think I'm just not applying to right header info but would like to confirm this is working.

PsychoFox11, 2024-03-30:
@smesgr9000 @sakman55 I'd appreciate some help - sorry for the double tag - I realized my dump is garbage, but also this doesn't make sense. You stated the tested game as Petscii Robots, which is 256kb, but this only allows selection up to 128kb. What option did you choose to dump it with this diff? I still think I made the bodge right but getting garbage dumping at 128kb setting.

PsychoFox11, 2024-03-30:
Ok sorry for all the noise - I got it to work. I think I had a cart seating issue at one point. I found the demo was the same size and used its header which worked great.
Though it was not clear at all that I'd get a 256kb dump by picking 128kb. Does it just autodetect at that point, or are these supposed to be twice size?

Closed 2024-03-24.

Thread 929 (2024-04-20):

Atari 2600 menu broken

plaidpants, 2024-04-20:
### OSCR firmware version

built latest from github and V13.1

### OSCR hardware version

HW3

### Attach OSCR_LOG.txt file here

NA

### System used

Atari 2600

### Describe the issue.

Atari2600 menu does not work, cannot move menu selection dot to next item, present in V13.1 and latest github release. Last working version was V12.8

smesgr9000, 2024-04-27:
I have reworked cart selection today. Could you retest - please update your SD card with the newest files. If not could you describe your issue in more detail. I see no change between 12.8 and 13.1 with menu interaction.

plaidpants, 2024-04-28:
Thanks, I will give it a go tomorrow.

plaidpants, 2024-04-28:
Sill not working, here is a video of both the atari2600 menu not working and the SNES menu working from the same build.

https://github.com/sanni/cartreader/assets/8979271/38e9b746-215b-4ded-8c2b-d0e6e8709adf

https://github.com/sanni/cartreader/assets/8979271/9696f09c-b4f4-462e-ad48-2b591bda2d98

smesgr9000, 2024-04-29:
thats odd. The code handling the menu is the same for SNES and Atari 2600.  Could you please check if all other systems are working. Sadly I don't have the hardware to debug this issue. Another solution to pinpoint the issue would be to https://git-scm.com/docs/git-bisect this issue until the commit can be narrowed down.

sanni, 2024-04-30:
I am not able to recreate this issue with my HW3. Both V13.1 and the current GitHub code work fine. Also the Atari 2600 module was not changed between V12.8 and V13.1, it's the same file.

Have you enabled any other additional modules or options besides Atari 2600? If not try disabling a big module like NES to see if it's a memory issue.

Are you using the portable Arduino IDE from the release section or your own Arduino IDE setup? If you're using your own Arduinio IDE try using the libraries from of the portable release.

plaidpants, 2024-04-30:
Gameboy menu works
**NES menu does not work**
SNES menu works
N64 menu works
Genesis menu works
Sega Master System menu works
**Atari 2600 menu does not work**

plaidpants, 2024-04-30:
[Config.h.txt](https://github.com/sanni/cartreader/files/15172054/Config.h.txt)
Here is the modified config.h file I used.

plaidpants, 2024-04-30:
OK, I think I figured it out, if I turn off ENABLE_VSELECT the atari 2600 menu works, now the question is do I have the ENABLE_VSELECT or not?

PsychoFox11, 2024-04-30:
Not sure what you're asking, but if you have a voltage switch, vselect is off. Vselect is an optional board that sets the voltage for you. If you don't have a voltage switch you probably have one, and can test its functionality with a multimeter, should be 5v on most and 3.3v on GBA/N64.
I have no idea what happens if you configure it incorrectly. I have one unit with it, one without it, but always set it for the specific one.

smesgr9000, 2024-05-01:
@PsychoFox11  could you check with his configuration on your device? I think @sanni is right and has properly something to do with rom used. VOLTAGE_SELECT does require more program memory than without.

PsychoFox11, 2024-05-01:
> @PsychoFox11 could you check with his configuration on your device? I think @sanni is right and has properly something to do with memory used. VOLTAGE_SELECT does require more program memory than without.

@smesgr9000 Sure, though I'm on HW5 - is vSelect a HW3 option? (I haven't really paid attention to pre-HW5 stuff as it is where I came in).

I can try with vSelect enabled when it shouldn't be though, and use the config file but changing the HW version. Will try to look into that tomorrow (well much later today as it is 4am) most likely.

smesgr9000, 2024-05-01:
ah ok sorry thought you had a HW3 - no i don't think this is useful.

PsychoFox11, 2024-05-01:
@smesgr9000 @plaidpants From the page on vSelect - [https://github.com/sanni/cartreader/wiki/Automatic-Voltage-Selection](https://github.com/sanni/cartreader/wiki/Automatic-Voltage-Selection) - it is only an option for HW5, so if they say it works when disabled, and are on HW3, it sounds like working as intended...

PsychoFox11, 2024-05-01:
It does seem like a good update to throw a compile error of some sort if vselect is enabled and HW is <5

Ancyker, 2024-05-01:
> It does seem like a good update to throw a compile error of some sort if vselect is enabled and HW is <5 I'd prefer that over having the code ignore it cause people need to know what they are setting.

A warning would also work, i.e.
```c
#warning VSELECT enabled but is only supported on HW5, disabling.
```

Ancyker, 2024-05-01:
> @smesgr9000 @plaidpants From the page on vSelect - https://github.com/sanni/cartreader/wiki/Automatic-Voltage-Selection - it is only an option for HW5, so if it works when disabled, on HW3, it sounds like working as intended...

There's nothing technically preventing someone from using VSELECT on HW3, it's just that it doesn't make much sense to since you'd still need to switch the clock. I targeted HW5 with it because it was the only switch left on it other than the power switch.

Ancyker, 2024-05-01:
@plaidpants I'm curious, what happens if you update with https://oscr.tools/update ?

Ancyker, 2024-05-01:
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

Reset your `Config.h` to untouched and only enable the options you checked in the updater.

Specifically, you probably want `HW3`, `ENABLE_UPDATER`, and `clockgen_installed` (if you have the clock generator). Don't enable anything else.

Once you do that, see if it still works. If it does, enable the Atari core (`ENABLE_2600`) and see if it continues to work.

Don't touch anything other than those options while testing. Enable things one at a time so that if it breaks you know the last option you enabled is what broke it.

-

The Firmware Updater on OSCR.Tools is a good test because the binaries are cached forever once built -- that means anyone selecting the same options as you is getting literally the exact same binary. This helps rule out a compilation bug specific to your system.

plaidpants, 2024-05-01:
Rebuild with HW3, ENABLE_UPDATER, and clockgen_installed, all menus work, added ENABLE_2600, still works.

smesgr9000, 2024-05-20:
is there a TODO open?

plaidpants, 2024-05-20:
There was a discussion about adding a compile warning or error if the wrong
combinations of defines was encountered. That's all I think was to-do.

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

Ancyker, 2024-05-20:
Yeah, there's not much to do here. They enabled a hardware option in the firmware that their hardware doesn't have.

Ancyker, 2024-05-20:
Btw, the reason it caused that is VSELECT on HW5 connects to PD7 for toggling the voltages. On HW5 this was the status LED, but on HW3 it's the input button:

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

So on HW3, a different pin would need to be chosen for VSELECT's toggle if we were to want to add support for it on HW3.

Closed 2024-06-02.

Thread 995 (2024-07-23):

Support for Evercade

TopHatHipster, 2024-07-23:
### OSCR firmware version

14

### OSCR hardware version

HW3 Alter

### Attach OSCR_LOG.txt file here

_No response_

### System used

all/none/doesn't matter

### Describe the issue.

Would it be possible to add Evercade cartridge support at some point?

Doing a bit of searching, it should be possible to read Evercade cartridges for backing up and possibly restoring corrupted ones.

- The Evercade cartridge looks like to be a "[microSD card flash soldered onto a GBA cartridge](http://retrotechr.blogspot.com/2020/06/evercade.html?m=1)" with the layout being known as:
    - Pin 1 - DAT2
    - Pin 2 - DAT3
    - Pin 3 - CMD
    - Pin 4 - VDD
    - Pin 5 - CLK
    - Pin 6 - GND
    - Pin 7 - DAT0
    - Pin 8 - DAT1
- The same article as above also points out that the cartridge is formatted as FAT16 - which should be possible with the [SdFat library existing out there for Arduino devices](https://github.com/greiman/SdFat). I'm unsure if this is used for regular SD card support on the cartreader?
- [No-Intro seemingly suggests dd'ing cartridges](https://forum.no-intro.org/viewtopic.php?t=5248) for proper back up.

Would adding this as a software update feature be feasible, with the pre-existing GB/GBA slot present in cartreader builds?

Can't make hardware myself nor am I knowledgeable in Arduino software, but I'd love to help out testing if possible.

PsychoFox11, 2024-07-24:
I only know what I've learned from this project, but if speeds are comparable to current carts it would be a SLOW dump on those 512MB ones for sure. I can just about go for dinner during a 128MB ROM dump lol.

PsychoFox11, 2024-07-24:
Also, looks like pin 1 is used for power on GBA, and ping 4 on Everdrive. Software can move some pins but not the voltage/power, so it would likely need an adapter at the least. At that point, why not just make an evercade to SD adapter and skip the additional hardware?

TopHatHipster, 2024-07-24:
> At that point, why not just make an evercade to SD adapter and skip the additional hardware?

As stated in my issue - I can't make hardware myself hence my suggestion to make it a possible software feature.

However, thanks for the clarification why it wouldn't be possible with another adapter due to the power pins. Will close the issue, due to this blocking problem. 👍

nsx0r, 2024-07-24:
@smesgr9000 made a cool and simple adapter that uses a GameBoy slot and plugs directly to a microSD port: https://github.com/smesgr9000/microcade
However, no 2 Evercade cartridges are identical so there's no way to compare/verify 2 dumps of the same game.

TopHatHipster, 2024-07-24:
> However, no 2 Evercade cartridges are identical so there's no way to compare/verify 2 dumps of the same game.

It's more so about the files used by said cartridges. AFAIK they should be exactly the same and are checksum checked by the OS present on Everdrive devices.

nsx0r, 2024-07-24:
> > However, no 2 Evercade cartridges are identical so there's no way to compare/verify 2 dumps of the same game.
>
> It's more so about the files used by said cartridges. AFAIK they should be exactly the same and are checksum checked by the OS present on Everdrive devices.

the files are identical, yes, I'm talking about image (dumps) of the entire cartridge/media, which the OSCR does for cartridges. So even if the OSCR could backup Evercade cartridges, there would be no easy way to automatically identify the cartridge and set the proper settings for dumping.

smesgr9000, 2024-07-24:
yes and no
yes the files are mostly identical. BUT because save states, statistics and _UPDATES_ to the cartridge are stored on card you need to track which files are actually the ROM for every cartridge. There are reports where updates to the cart have bricked the cards file structure and aren't detected by Evercade anymore. Plus an update could also replace ROMs of course.  After all it is just a SD-Card in odd housing.
To be honest I would bother supporting this on cardreader if you could just use your ordinary PC.

Closed 2024-07-24.

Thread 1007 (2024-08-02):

Batman Forever (Sega Genesis) not dumping padding correctly

PsychoFox11, 2024-08-02:
### OSCR firmware version

14

### OSCR hardware version

HW5

### Attach OSCR_LOG.txt file here

OSCR HW5 V14.0

[+] Mega Drive/Genesis

[+] Game Cartridge

Cart Info

Name: BATMANFOREVER
bramCheck: 0100
Size: 32 MBit
ChkS: BC5F
Sram: None

Press Button...

[+] Read ROM

Saving to MD/ROM/BATMANFOREVER/1123/...
[*******************]
Internal checksum...Error
533C

CRC32... 795F8C5E -> Not found

### System used

Select a system

### Describe the issue.

Creating a new issue for this specifically, as I can reproduce it and gathered more info about the behavior. The other issue also mentions Turrican, but I can dump that fine consistently, and may be an issue with a bad cart. Batman Forever seems to be an actual OSCR issue though.

I am not able to get a good dump of Batman Forever (World) using the OSCR, and another user is experiencing the same which led to me looking into this.

It is a 4MB chip with a 3MB game on it (older ROMs were trimmed). However, starting at the beginning of the 4th MB, according to No-Intro's dump, which includes one from a Retrode, it should be all FF for the last 1MB. The first 3MB dump fine, but then the 4th MB seems random - always a different checksum/CRC32. The game plays fine.

Typically this would lead me to believe that the last MB isn't mapped to the edge connector, and desoldering would be the only way to dump the full chip - however, a Retrode was able to do it, so it appears to be possible. It is a single chip, and any time Sega used chip sizes that were not a power of 2, multiple chips were used. It also doesn't overdump and return to the beginning.

Here's a comparison of one of my dumps (top) compared to what's known (bottom).

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

Every value I get in the padding is either 3C, 3E, 7C, or 7E - and 1C a few times at the beginning then not again - but never in the same order.

Here's the PCB (thanks to @fakkuyuu for reporting that this game didn't dump properly in general and providing this pic - my PCB is the same).
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

Anyone know what might be going on here?

sanni, 2024-08-02:
Try enabling the internal pull-up resistors on the data pins, then open bus should become 0xFF.

In [MD.ino line 696](https://github.com/sanni/cartreader/blob/master/Cart_Reader/MD.ino#L696)

Change:
````
// Switch data pins to read
void dataIn_MD() {
  DDRC = 0x00;
  DDRA = 0x00;
}
````

to:
````
// Switch data pins to read
void dataIn_MD() {
  DDRC = 0x00;
  DDRA = 0x00;
  // Enable Internal Pullups
  PORTC = 0xFF;
  PORTA = 0xFF;
}
````

PsychoFox11, 2024-08-02:
That works, should I keep it there permanently or would it cause issues with others, and we need to make it only do it for this cart?
@fakkuyuu making sure you see this

sanni, 2024-08-02:
I'll add it to the github code and make a remark about what it does for future reference.

fakkuyuu, 2024-08-02:
I've rewritten the code and was able to dump it. Thank you.
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

PsychoFox11, 2024-08-05:
While it does give us a dump that matches No-Intro now, if I understand correctly, the last 1MB isn't properly mapped, and this is more of a "write FF instead of random noise when you can't read it" type code.
So while it results in a cleaner, properly sized file, I don't think it confirms that FF is really on the chip - which is fine, I don't think that can be confirmed from the edge reader, and this matches what No-Intro has recorded. I'm guessing the Retrode does something similar as it only creates a match if you force the size to 4MB instead of the default trimmed 3MB.
If I get a chance, I'm going to desolder this chip and see if I can find out what's on it - something I'm still new to.
My guess is that it probably DOES continue the FF that the 3MB ends with, but I have encountered a few where the ROM written to the cart ended in FF but the blank padding after the end of the ROM was 00.
It only matters for full-chip preservationists. The game is being recorded just fine even in the noisy dump, but I like to be sure what's in there. If I find anything other than FF, I might revisit this (via a new issue) as I'd update No-Intro as welll.
I think it is good to mark this closed now.

Closed 2024-08-05.

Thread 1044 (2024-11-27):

Six-Slot PCB Text error

ccfman2004, 2024-11-27:
### OSCR firmware version

N/A

### OSCR hardware version

HW5 Rev6

### Attach OSCR_LOG.txt file here

_No response_

### System used

all/none/doesn't matter

### Describe the issue.

The text on the Six-Slot adapter says "2.5mm 50-Pin N64 Cartridge Slot". Shouldn't it say 2.54mm as the pin spacing was changed a while ago.

nsx0r, 2024-11-27:
The N64 slot does have a 2.5mm pitch, not 2.54mm (that's for the Sega Master System).

ccfman2004, 2024-11-27:
I feel like an idiot. I completely misread the change log. I didn't see the word "controller" in "Change N64 controller connector pitch to 2.54mm" for some reason. I hate it when my brain does that.

Sorry about that.

Closed 2024-11-27.

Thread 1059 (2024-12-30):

Cant dump NES Tetris (USA) ver

pandidand, 2024-12-30:
### OSCR firmware version

14.3

### OSCR hardware version

HW3

### Attach OSCR_LOG.txt file here

OSCR HW3 V14.3

[+] NES/Famicom

No data found.
Using manual selection
Select Mapping from List

NES CART READER

CURRENT SETTINGS

MAPPER:   1
PRG SIZE: 32K
CHR SIZE: 16K
RAM SIZE: 0K

Press Button...

[+] Read iNES Rom

Saving to NES/ROM/Tetris/12/...
[*******************]
CRC32... FE55AE10 -> Not found

Press Button...

### System used

NES/Famicom/Family Basic

### Describe the issue.

When dumping NES Tetris cartridge data (ROM), the cartridge is not recognized (which may be fine), so I select the Tetris version from the menu. Then it fails after dumping with CRC32... FE55AE10 -> Not found.

The cart itself is working (verified on original hardware afterwards), the dumped file looks weird and does not work in an emulator.
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

All my other carts (Zelda 1,2, Super Mario, ...) were dumped successfully, so I think my hardware is working fine. Its weird that especially tetris is not working ... I thought that this game has been dumped a thousand times.

Also the cart looks genuine to me:
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

nsx0r, 2024-12-31:
Hi, this should be fixed now https://github.com/sanni/cartreader/blob/2100cd55f60e8d6e411469f082990edf50dacdc4/Cart_Reader/NES.ino#L1853

JakubWaikat, 2024-12-31:
Hi, thanks for the very fast response. I have tested the fix, but it unfortunately did not work.

```
OSCR HW3 V14.5

[+] NES/Famicom

No data found.
Using manual selection
Select Mapping from List

NES CART READER

CURRENT SETTINGS

MAPPER:   1
PRG SIZE: 32K
CHR SIZE: 16K
RAM SIZE: 0K

Press Button...

[+] Read iNES Rom

Saving to NES/ROM/Tetris/19/...
[*******************]
CRC32... 892B4EC0 -> Not found

Press Button...
```

Is there anything I can do (send you some data or smth) to support you with debugging?

gemarcano, 2024-12-31:
Does Tetris not have a signature that can be picked up on by the OSCR? I find it odd you have to specify its information. With another SEROM cart, Dr. Mario, the firmware correctly identified the cart (even before the fix, I just couldn't dump it).

If you can analyze the dumped game, that can help to figure out what's going on. Specifically you'll want to look for repetitions of large blocks of data usually at some address power of two.

If I under the mapper for Tetris, your game dump should be structured as:
 - 16 bytes of header
 - 32 * 1024 (0x8000) bytes of PRG ROM
 - 16 * 1024 (0x4000) bytes of CHR ROM

Pre-fix, my PRG section was repeating every 16 * 1024 bytes (or, after removing the first 16 bytes, the first 0x4000 bytes were the same as the next 0x4000 bytes).

JakubWaikat, 2024-12-31:
I put the dump into HxD, there is only FF until 0x8000 and also the remainder does not look right IMO. Attached the .nes file:
[Tetris.zip](https://github.com/user-attachments/files/18283718/Tetris.zip)

gemarcano, 2024-12-31:
Interesting. I can try to take a look at the ROM, but if there's only FF until 0x8000 that sounds like a problem reading from PRG ROM. Even pre-fix at least one of my PRG pages looked right.

gemarcano, 2024-12-31:
We might need help from someone that knows more about the NES than me, because it sounds to me like some control signals are being ignored by your PRG (bad chip), or they're just not making it to the ROM (broken traces on cart, problems with socket, bad traces on adapter board).

Does your OSCR dump other NES games? And does Tetris work on a NES?

JakubWaikat, 2025-01-01:
Yes this is the weird thing ... the OSCR dumps other NES games well (Zelda 1,2; Super Mario Bros + Duckhunt, Mega Man 3; ...) without any issues and the NES cart works in the original hardware without any problems

gemarcano, 2025-01-01:
That's really odd. If other games are dumping, that most likely means that at least the normal control signals for the PRG ROM work. And honestly that should be all that's needed for a SEROM PCB cart, I think. And if Tetris works on the original cart, clearly the NES is reading the PRG ROM.

Hm. This is a wild guess, but if you have a way to check the voltage on the cart while it's plugged in, I wonder if your cart doesn't like that the voltage might be drooping below 4.7V? At least on my OSCR the Vcc on the cart was around 4.6V. Although in _theory_ the chips of that generation should work with voltages down to 4.5V.

Sadly I'm out of ideas. If this is something you want to continue investigating I'd hop on the OSCR Discord and see if there's someone there that might know more.

JakubWaikat, 2025-01-02:
I can probably try that tomorrow, otherwise I will ask in the discord. Thanks for the support!

JakubWaikat, 2025-01-05:
I took a measurement between pins 1 and 36 and got something between 4.640V to 4.720V but never going below 4.6V. I will try to consult discord.

splash5, 2025-01-07:
Could you try modify
`#define MODE_READ \
  { \
    PORTK = 0xFF; \
    DDRK = 0; \
  }`
to
`#define MODE_READ \
  { \
    PORTK = 0x00; \
    DDRK = 0; \
  }`
in NES.ino and try dump it again?

pandidand, 2025-01-07:
Thanks for the suggestion, I tried, but did not work, see the dump attached.
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
[Tetris.zip](https://github.com/user-attachments/files/18337434/Tetris.zip)

splash5, 2025-01-08:
Ok, so this means PRG ROM is never been activated.
Could you try add one line in read_prg_byte function and try again?
<code>
static unsigned char read_prg_byte(unsigned int address) {
  MODE_READ;
  PRG_READ;
  ROMSEL_HI;  // add this line
  set_address(address);
  PHI2_HI;
  set_romsel(address);
  _delay_us(1);
  return PINK;
}
</code>

pandidand, 2025-01-08:
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

I tried with `MODE_READ \ { \ PORTK = 0x00` and `MODE_READ \ { \ PORTK = 0xFF`, but unfortunatelly both did not work:
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

splash5, 2025-01-09:
Hmm that's strange. At least the CHR ROM should be able to dump without problem, because CHR ROM enable signal
is pretty simple.
I also tried wiring my MMC1 dev cart like SEROM and it dumped correctly, this means cartreader itself is able to dump SEROM.

Maybe you can try to check/clean cartridge connector on cartreader and cartridge's gold finger and try it again.

pandidand, 2025-01-14:
OK I checked the contacts anyways although I knew they were fine (since all my carts are in a good condition and I clean the contacts regularly), and I noticed that it may be the case, that my NES connector (of the OSCR) does not reach the contacts on the back side of the PCB.
See images here:
Front side:
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
Back side:
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

I have then inserted the cart into my NES adapter:
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

The fingers of the adapter are not going up that much, so I took a multimeter and checked the contacts and indeed they were not connecting. I have then managed with some strange angled insertion method to get the contacts connected (I assume barely) and then the dumping was working.

I have then verified with the latest main branch if the current code does dump that cart and it did also work.

So thanks everyone :)

I will close the issue now.

Closed 2025-01-14.

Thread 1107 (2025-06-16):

GBA: Nintendo e-reader always fails flash erasure

CaitSith2, 2025-06-16:
### OSCR firmware version

14.7

### OSCR hardware version

HW3

### Attach OSCR_LOG.txt file here

_No response_

### System used

Game Boy Advance

### Describe the issue.

I have figured out that the Nintendo e-reader does not allow read access to the last 128 bytes of the flash, regardless of the bank.  The reason for that, is that the hardware to access the e-reader card scanning camera lives in that region.  The end result is that when a blank check is done on the flash, the blank checking fails, because the last 128 bytes always returns zero.   The pitfall, is that if the flashing isn't allowed to proceed because of this, the e-reader ends up being bricked, as the e-reader calibration data lives on the flash.   This means a special case needs to be added for the Nintendo e-reader, (all 3 versions),  to ignore blank checking of the last 128 bytes of each flash bank.

sanni, 2025-06-17:
Is it the e-Reader+ with 1M flash since you mention banks?

from GBA.txt;
````
Card e-Reader (Japan).gba
A4EF4E95,PEAJ,04,FLASH_V124

Card e-Reader+ (Japan).gba
4139E7C3,PSAJ,08,FLASH1M_V103
````

If so would this work?

Replace [GBA.ino line 199-208:](https://github.com/sanni/cartreader/blob/master/Cart_Reader/GBA.ino#L199)
````
          // 131072 bytes are divided into two 65536 byte banks
          for (byte bank = 0; bank < 2; bank++) {
            switchBank_GBA(bank);
            setROM_GBA();
            // Card e-Reader+ does not allow access to last 128 bytes of a bank
            if (strcmp("PEAJ", cartID) == 0) {
              println_Log(F("Skipping last 128 bytes"));
              if (!blankcheckFLASH_GBA(65408))
                break;
              writeFLASH_GBA(!bank, 65408, bank ? 65536 : 0, 0);
              if (verifyFLASH_GBA(65408, bank ? 65536 : 0))
                break;
            }
            else {
              if (!blankcheckFLASH_GBA(65536))
                break;
              writeFLASH_GBA(!bank, 65536, bank ? 65536 : 0, 0);
              if (verifyFLASH_GBA(65536, bank ? 65536 : 0))
                break;
            }
          }
````

CaitSith2, 2025-06-18:
Some further tweaks were required to the code, specifically in blankcheckFLASH_GBA,  writeFLASH_GBA and verifyFLASH_GBA,  the inner loop that operates on 512 bytes at a time, needed to check if the end of declared flash size was reached, and stop if so.

For one thing, the two e-reader carts with the 1M flash, have game card IDs PSAJ and PSAE.  The other e-reader with only the 512K flash (and also lacks a link port passtrhough) has the ID PEAJ.

Regardless, All 3 of them are going to operate in the same way, in terms of the last 128 bytes not being writable to the flash.

For the 512K flash

```
            eraseFLASH_GBA();
            if (strcmp("PEAJ", cartID) == 0) {  // Japanese e-reader
              println_Log(F("Skipping last 128 bytes"));
              if (blankcheckFLASH_GBA(65408)) {
                writeFLASH_GBA(1, 65408, 0, 0);
                verifyFLASH_GBA(65408, 0);
              }
            }
            else {
              if (blankcheckFLASH_GBA(65536)) {
                writeFLASH_GBA(1, 65536, 0, 0);
                verifyFLASH_GBA(65536, 0);
              }
            }
```

And for the 1M flash
```
          // 131072 bytes are divided into two 65536 byte banks
          for (byte bank = 0; bank < 2; bank++) {
            switchBank_GBA(bank);
            setROM_GBA();
            // Card e-Reader+ does not allow access to last 128 bytes of a bank
            if (strcmp("PSAE", cartID) == 0 || strcmp("PSAJ", cartID) == 0) { // Japanese e-reader+, USA e-reader
              println_Log(F("Skipping last 128 bytes"));
              if (!blankcheckFLASH_GBA(65408))
                break;
              writeFLASH_GBA(!bank, 65408, bank ? 65536 : 0, 0);
              if (verifyFLASH_GBA(65408, bank ? 65536 : 0))
                break;
            }
            else {
              if (!blankcheckFLASH_GBA(65536))
                break;
              writeFLASH_GBA(!bank, 65536, bank ? 65536 : 0, 0);
              if (verifyFLASH_GBA(65536, bank ? 65536 : 0))
                break;
            }
          }
```

In blankcheckFLASH_GBA
```
  for (uint32_t currAddress = 0; currAddress < flashSize; currAddress += 512) {
    // Fill buffer
    for (int c = 0; c < 512; c++) {
      // Read byte
      sdBuffer[c] = readByteFlash_GBA(currAddress + c);
    }
    // Check buffer
    for (uint32_t currByte = 0; currByte < 512 && (currByte + currAddress) < flashSize; currByte++) {
      if (sdBuffer[currByte] != 0xFF) {
        print_Error(F("Erase failed"));
        currByte = 512;
        currAddress = flashSize;
        blank = 0;
      }
    }
  }
```

In writeFLASH_GBA
```
    if (!isAtmel) {
      for (uint32_t currAddress = 0; currAddress < flashSize; currAddress += 512) {
        //fill sdBuffer
        myFile.read(sdBuffer, 512);

        for (int c = 0; c < 512 && (currAddress + c) < flashSize; c++) {
          // Write command sequence
          writeByteFlash_GBA(0x5555, 0xaa);
          writeByteFlash_GBA(0x2aaa, 0x55);
          writeByteFlash_GBA(0x5555, 0xa0);
          // Write current byte
          writeByteFlash_GBA(currAddress + c, sdBuffer[c]);

          // Wait
          busyCheck_GBA(c);
        }
      }
    }
```

In verifyFLASH_GBA
```
  for (unsigned long currAddress = 0; currAddress < flashSize; currAddress += 512) {
    myFile.read(sdBuffer, 512);

    for (int c = 0; c < 512 && (currAddress + c) < flashSize; c++) {
      // Read byte
      if (sdBuffer[c] != readByteFlash_GBA(currAddress + c)) {
        wrError++;
      }
    }
  }
```

Closed 2025-07-09.

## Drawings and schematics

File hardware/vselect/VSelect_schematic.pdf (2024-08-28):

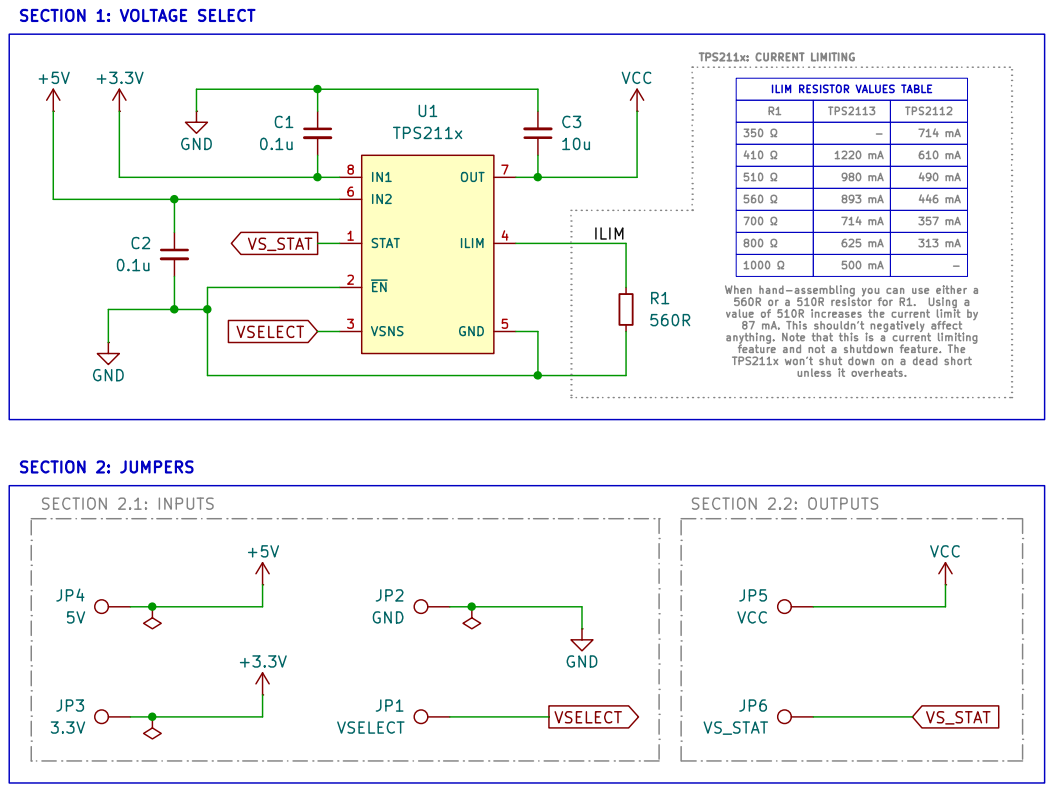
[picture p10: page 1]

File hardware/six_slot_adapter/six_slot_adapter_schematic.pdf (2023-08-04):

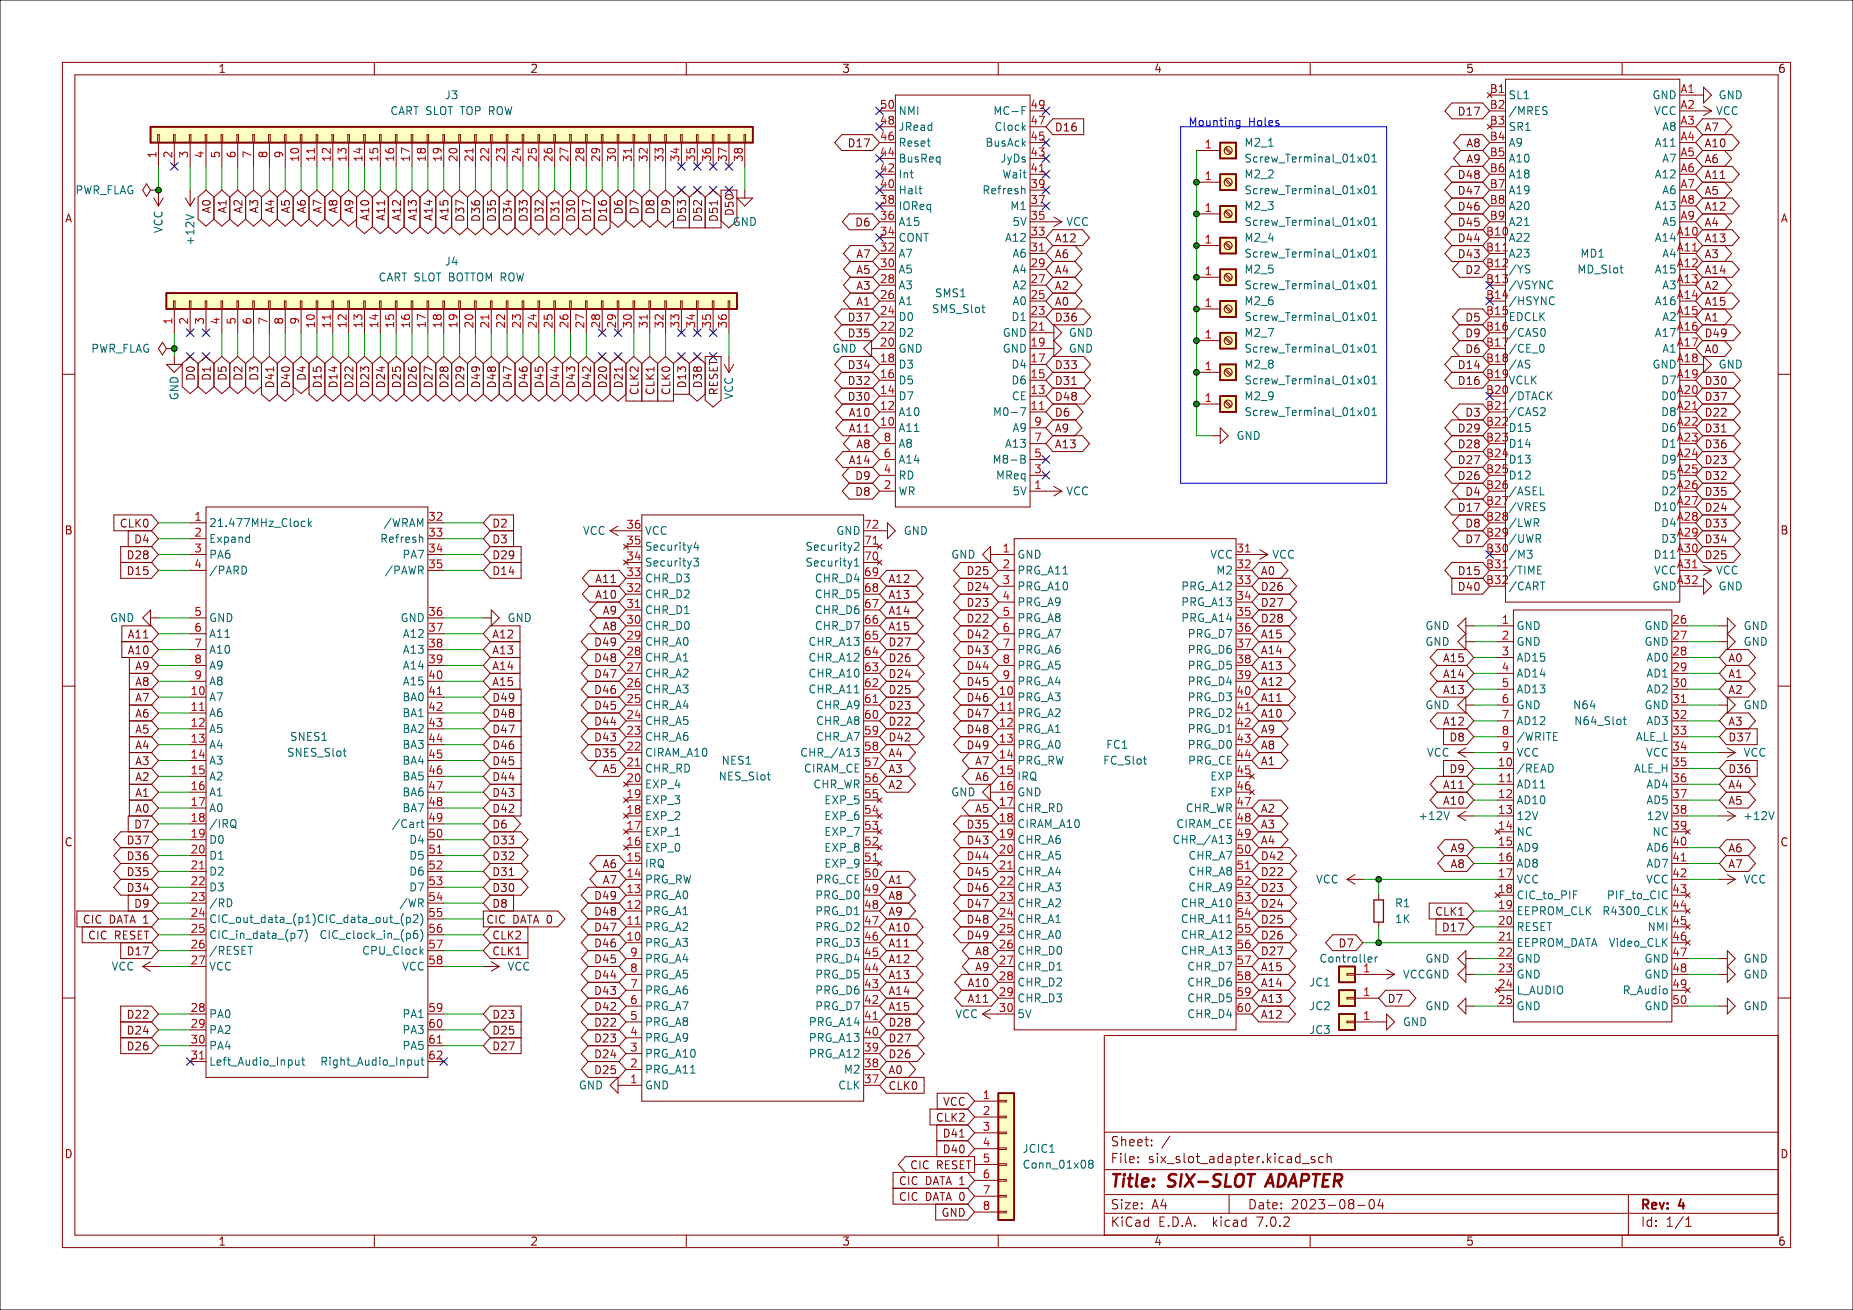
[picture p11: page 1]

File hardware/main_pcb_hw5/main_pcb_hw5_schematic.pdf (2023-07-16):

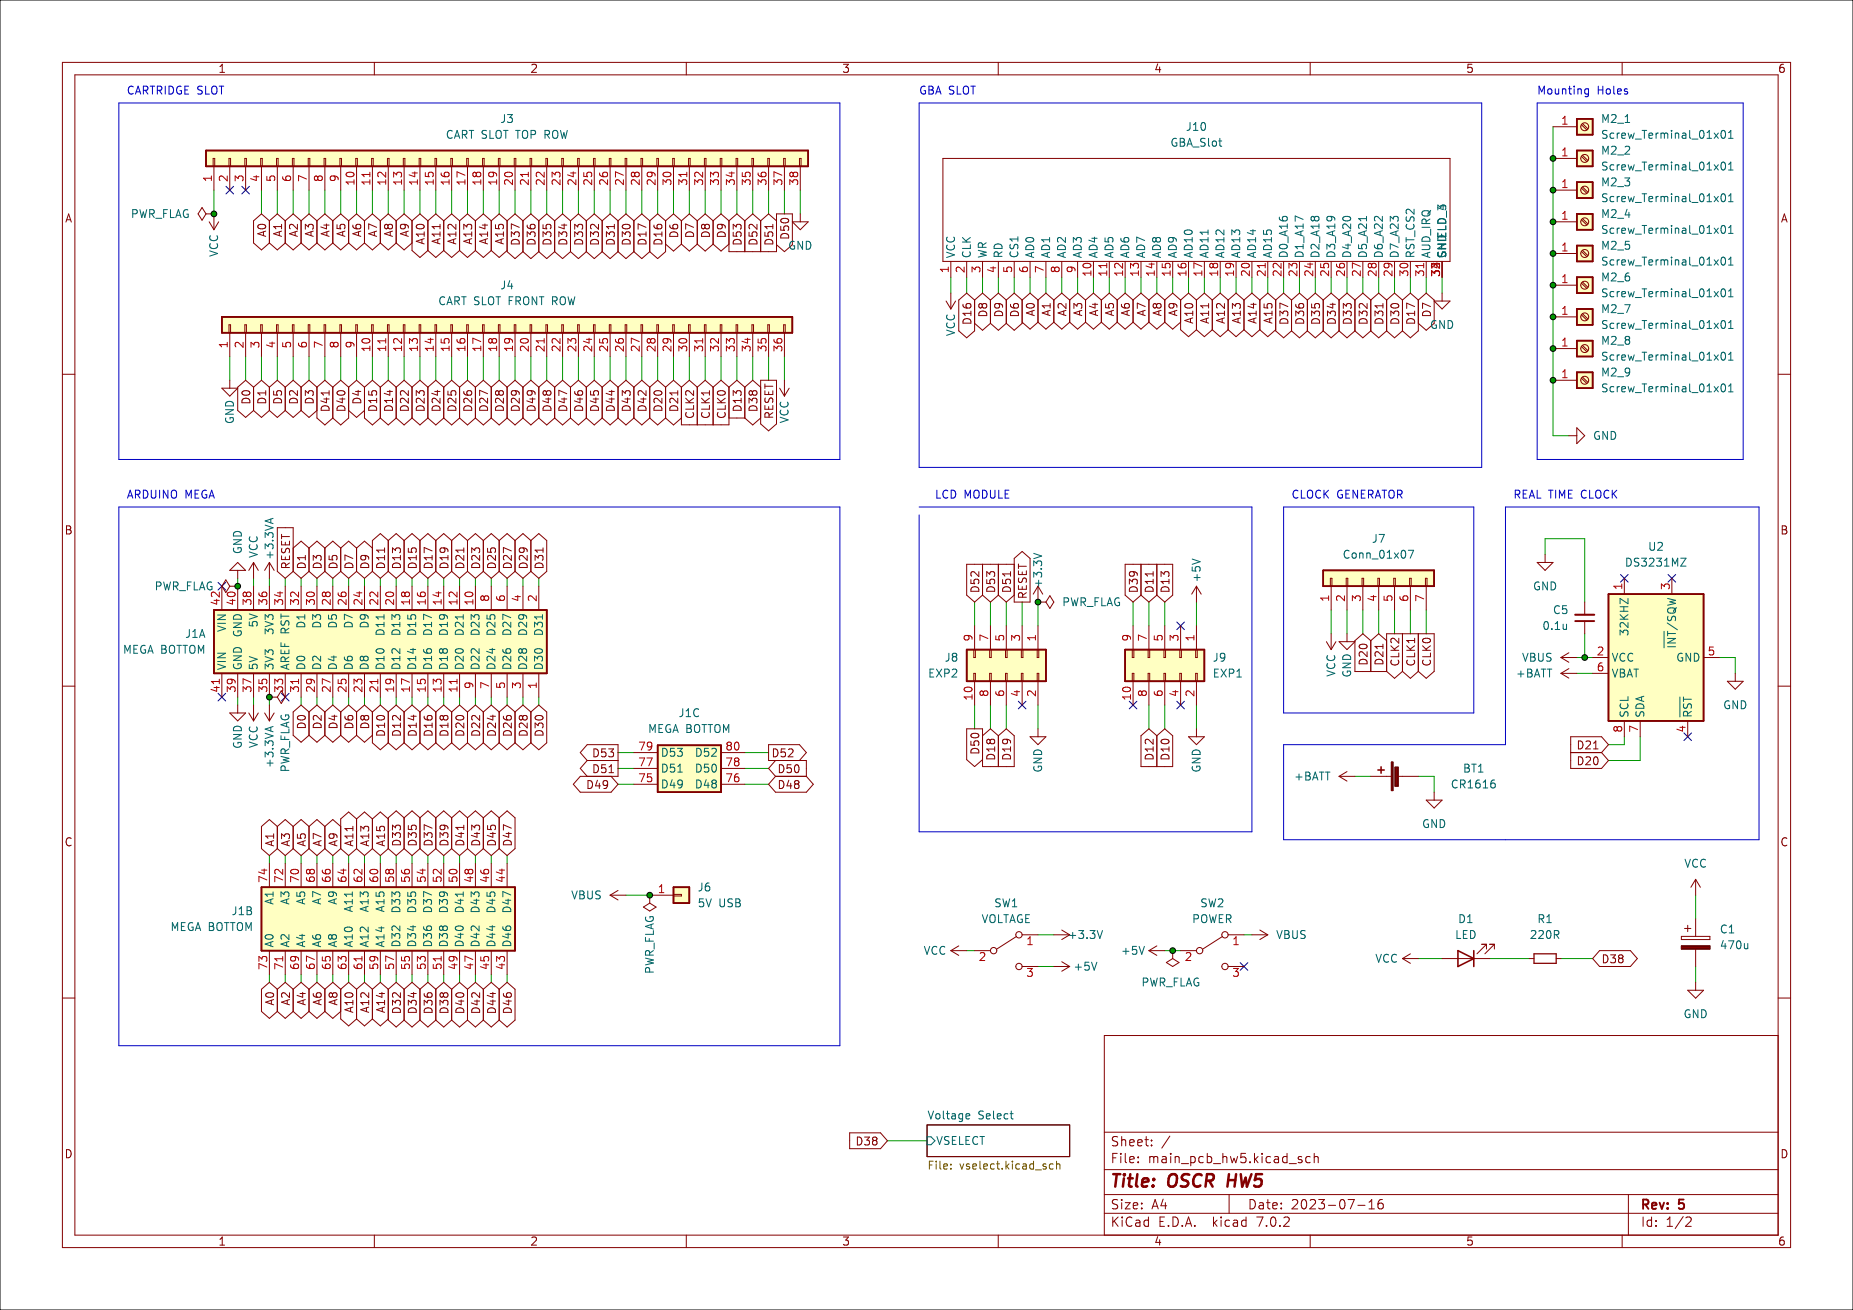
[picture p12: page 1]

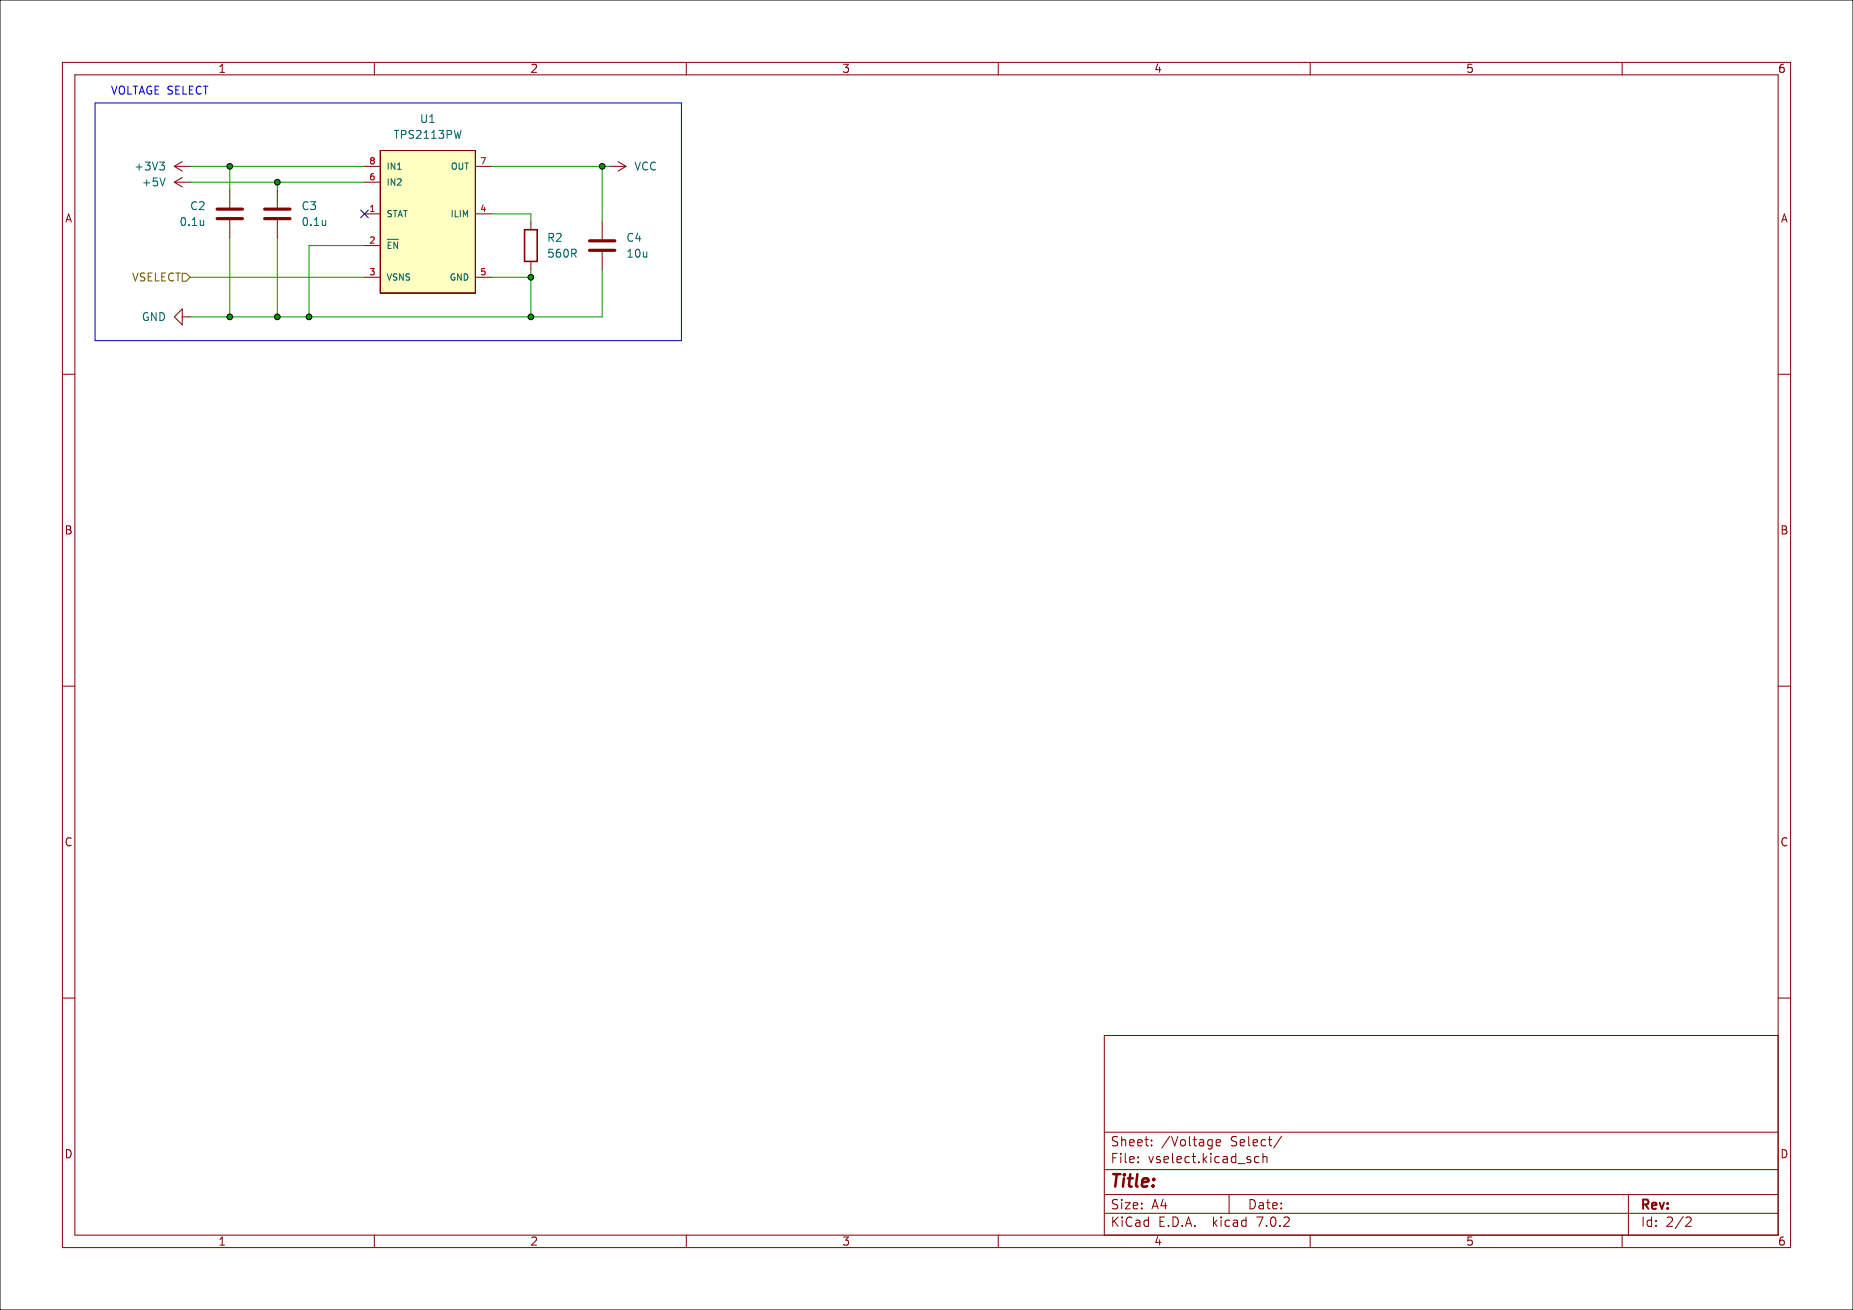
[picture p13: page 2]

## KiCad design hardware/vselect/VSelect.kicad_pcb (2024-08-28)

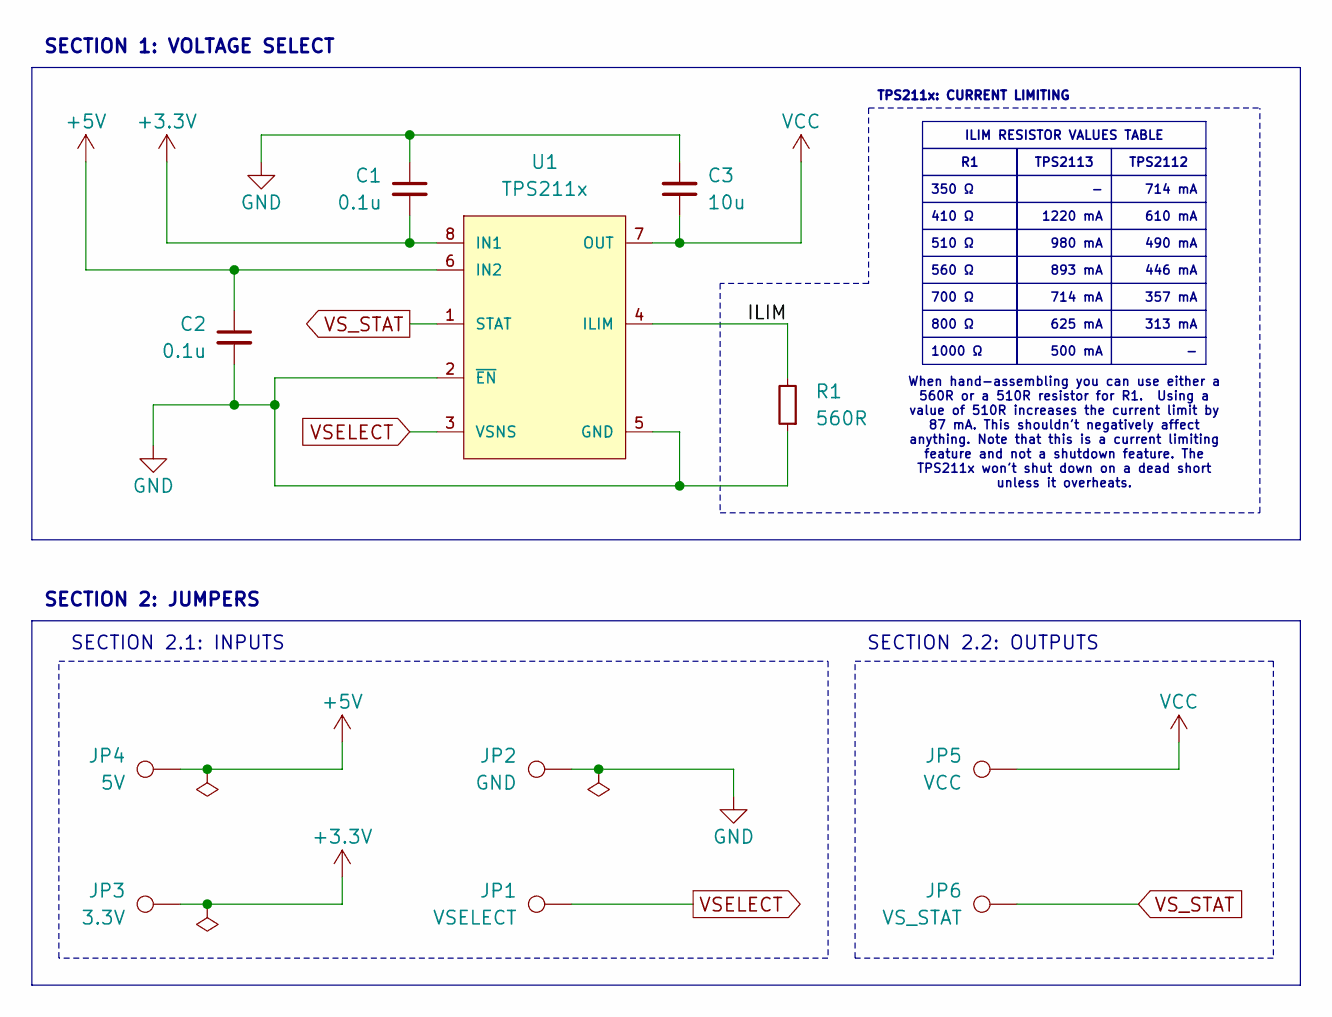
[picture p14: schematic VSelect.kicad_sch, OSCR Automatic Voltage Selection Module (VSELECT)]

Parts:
C1, C2: 0.1u; C_0402_1005Metric_Pad0.74x0.62mm_HandSolder; Part CL05B104KO5NNNC; LCSC C1525
C3: 10u; C_0402_1005Metric_Pad0.74x0.62mm_HandSolder; Part CL05A106MQ5NUNC; LCSC C15525
JP1: VSELECT; TestPoint_Pad_2.0x2.0mm
JP2: GND; TestPoint_Pad_2.0x2.0mm
JP3: 3.3V; Header - VSELECT - Switch Pad
JP4: 5V; Header - VSELECT - Switch Pad
JP5: VCC; Header - VSELECT - Switch Pad
JP6: VS_STAT; TestPoint_Pad_2.0x2.0mm
R1: 560R; R_0402_1005Metric_Pad0.72x0.64mm_HandSolder; Part 0402WGF5100TCE; LCSC C25123
U1: TPS211x; IC - VSELECT - TPS2113; Part Hand/TPS2113APWR (C130052); Machine/TPS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; LCSC C354512

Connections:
+3.3V: C1.2, JP3.1, U1.8 (IN1)
+5V: C2.1, JP4.1, U1.6 (IN2)
/ILIM: R1.2, U1.4 (ILIM)
GND: C1.1, C2.2, C3.2, JP2.1, R1.1, U1.2 (~EN), U1.5 (GND), U1.9 (GND)
VCC: C3.1, JP5.1, U1.7 (OUT)
VSELECT: JP1.1, U1.3 (VSNS)
VS_STAT: JP6.1, U1.1 (STAT)

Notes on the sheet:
350 Ω
SECTION 2: JUMPERS
700 Ω
TPS2113
510 Ω
446 mA
490 mA
980 mA
893 mA
1000 Ω
714 mA
313 mA
TPS211x: CURRENT LIMITING
500 mA
625 mA
560 Ω
357 mA
SECTION 2.2: OUTPUTS
610 mA
1220 mA
410 Ω
SECTION 2.1: INPUTS
ILIM RESISTOR VALUES TABLE
TPS2112
800 Ω
SECTION 1: VOLTAGE SELECT
When hand-assembling you can use either a 560R or a 510R resistor for R1. Using a value of 510R increases the current limit by 87 mA. This shouldn't negatively affect anything. Note that this is a current limiting feature and not a shutdown feature. The TPS211x won't shut down on a dead short unles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

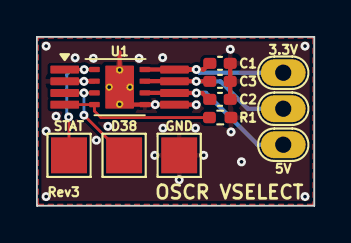
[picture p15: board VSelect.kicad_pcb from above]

Board: 2 copper layers, 15.4 x 9.4 mm, 11 parts (0 on the bottom side), 7 nets.

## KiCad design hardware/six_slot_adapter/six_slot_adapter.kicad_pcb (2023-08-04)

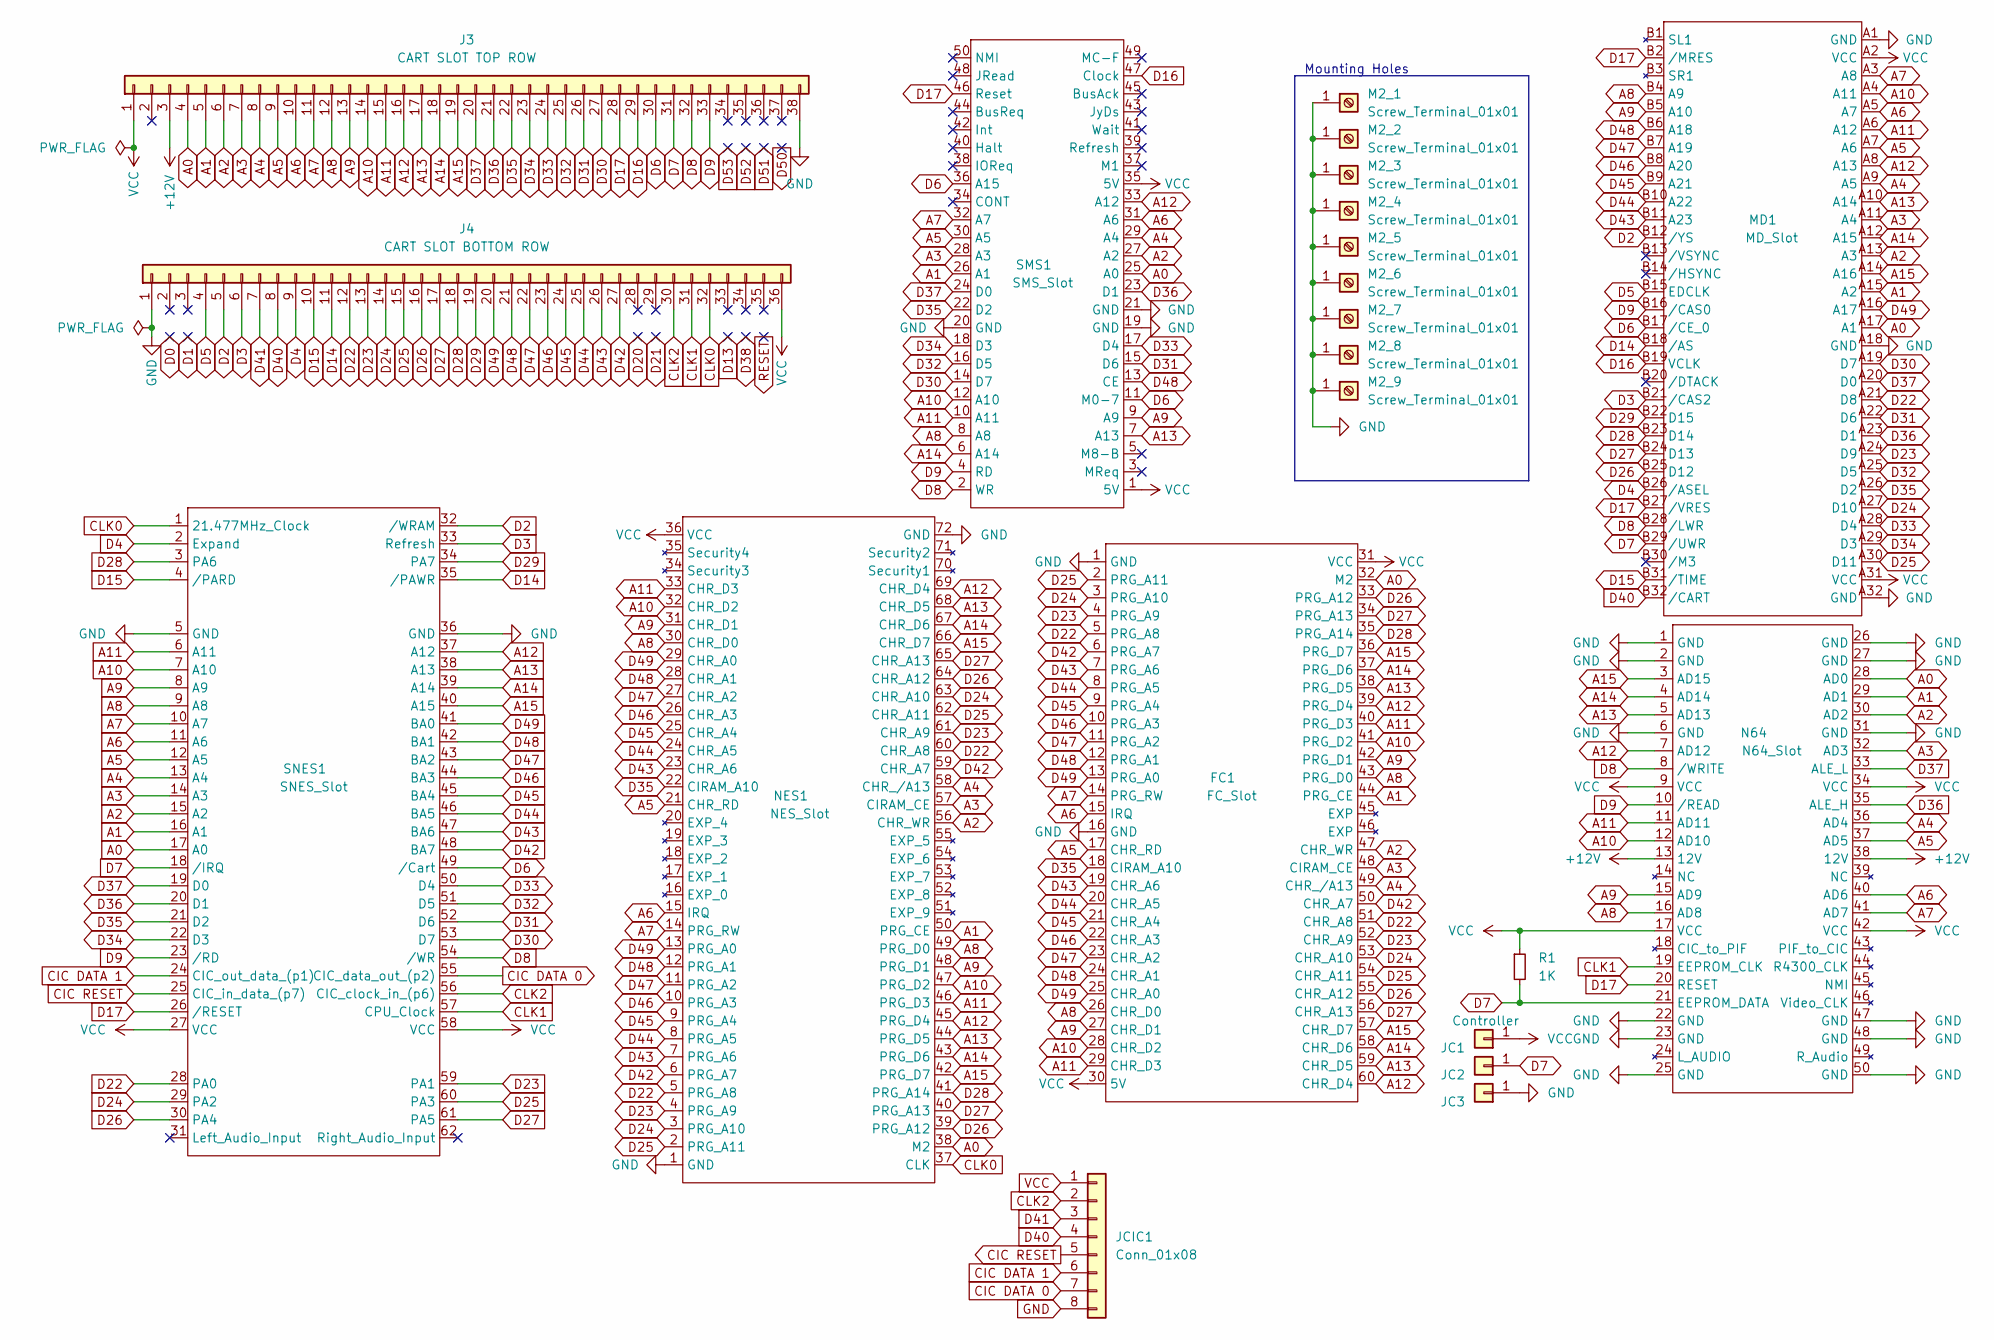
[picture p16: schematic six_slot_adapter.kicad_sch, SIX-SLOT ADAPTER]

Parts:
FC1: FC_Slot
J3: CART SLOT TOP ROW; PinSocket_1x38_P2.54mm_Vertical
J4: CART SLOT BOTTOM ROW; PinSocket_1x36_P2.54mm_Vertical
JC1: Controller; PinHeader_1x01_P2.54mm_Vertical
JC2, JC3: Conn_01x01; PinHeader_1x01_P2.54mm_Vertical
JCIC1: Conn_01x08; PinHeader_1x08_P2.54mm_Vertical
M2_1, M2_2, M2_3, M2_4, M2_5, M2_6, M2_7, M2_8, M2_9: Screw_Terminal_01x01; MountingHole_2.2mm_M2_ISO7380_Pad
MD1: MD_Slot
N64: N64_Slot; N64 Slot
NES1: NES_Slot
R1: 1K; R_Axial_DIN0207_L6.3mm_D2.5mm_P10.16mm_Horizontal
SMS1: SMS_Slot
SNES1: SNES_Slot; SNES Slot

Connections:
+12V: J3.3, N64.13 (12V), N64.38 (12V)
A0: FC1.32 (M2), J3.4, MD1.A17 (A1), N64.28 (AD0), NES1.38 (M2), SMS1.25 (A0), SNES1.17 (A0)
A1: FC1.44 (PRG_CE), J3.5, MD1.A15 (A2), N64.29 (AD1), NES1.50 (PRG_CE), SMS1.26 (A1), SNES1.16 (A1)
A2: FC1.47 (CHR_WR), J3.6, MD1.A13 (A3), N64.30 (AD2), NES1.56 (CHR_WR), SMS1.27 (A2), SNES1.15 (A2)
A3: FC1.48 (CIRAM_CE), J3.7, MD1.A11 (A4), N64.32 (AD3), NES1.57 (CIRAM_CE), SMS1.28 (A3), SNES1.14 (A3)
A4: FC1.49 (CHR_/A13), J3.8, MD1.A9 (A5), N64.36 (AD4), NES1.58 (CHR_/A13), SMS1.29 (A4), SNES1.13 (A4)
A5: FC1.17 (CHR_RD), J3.9, MD1.A7 (A6), N64.37 (AD5), NES1.21 (CHR_RD), SMS1.30 (A5), SNES1.12 (A5)
A6: FC1.15 (IRQ), J3.10, MD1.A5 (A7), N64.40 (AD6), NES1.15 (IRQ), SMS1.31 (A6), SNES1.11 (A6)
A7: FC1.14 (PRG_RW), J3.11, MD1.A3 (A8), N64.41 (AD7), NES1.14 (PRG_RW), SMS1.32 (A7), SNES1.10 (A7)
A8: FC1.26 (CHR_D0), FC1.43 (PRG_D0), J3.12, MD1.B4 (A9), N64.16 (AD8), NES1.30 (CHR_D0), NES1.49 (PRG_D0), SMS1.8 (A8), SNES1.9 (A8)
A9: FC1.27 (CHR_D1), FC1.42 (PRG_D1), J3.13, MD1.B5 (A10), N64.15 (AD9), NES1.31 (CHR_D1), NES1.48 (PRG_D1), SMS1.9 (A9), SNES1.8 (A9)
A10: FC1.28 (CHR_D2), FC1.41 (PRG_D2), J3.14, MD1.A4 (A11), N64.12 (AD10), NES1.32 (CHR_D2), NES1.47 (PRG_D2), SMS1.12 (A10), SNES1.7 (A10)
A11: FC1.29 (CHR_D3), FC1.40 (PRG_D3), J3.15, MD1.A6 (A12), N64.11 (AD11), NES1.33 (CHR_D3), NES1.46 (PRG_D3), SMS1.10 (A11), SNES1.6 (A11)
A12: FC1.39 (PRG_D4), FC1.60 (CHR_D4), J3.16, MD1.A8 (A13), N64.7 (AD12), NES1.45 (PRG_D4), NES1.69 (CHR_D4), SMS1.33 (A12), SNES1.37 (A12)
A13: FC1.38 (PRG_D5), FC1.59 (CHR_D5), J3.17, MD1.A10 (A14), N64.5 (AD13), NES1.44 (PRG_D5), NES1.68 (CHR_D5), SMS1.7 (A13), SNES1.38 (A13)
A14: FC1.37 (PRG_D6), FC1.58 (CHR_D6), J3.18, MD1.A12 (A15), N64.4 (AD14), NES1.43 (PRG_D6), NES1.67 (CHR_D6), SMS1.6 (A14), SNES1.39 (A14)
A15: FC1.36 (PRG_D7), FC1.57 (CHR_D7), J3.19, MD1.A14 (A16), N64.3 (AD15), NES1.42 (PRG_D7), NES1.66 (CHR_D7), SNES1.40 (A15)
CIC DATA 0: JCIC1.7, SNES1.55 (CIC_data_out_(p2))
CIC DATA 1: JCIC1.6, SNES1.24 (CIC_out_data_(p1))
CIC RESET: JCIC1.5, SNES1.25 (CIC_in_data_(p7))
CLK0: J4.32, NES1.37 (CLK), SNES1.1 (21.477MHz_Clock)
CLK1: J4.31, N64.19 (EEPROM_CLK), SNES1.57 (CPU_Clock)
CLK2: J4.30, JCIC1.2, SNES1.56 (CIC_clock_in_(p6))
D2: J4.5, MD1.B12 (/YS), SNES1.32 (/WRAM)
D3: J4.6, MD1.B21 (/CAS2), SNES1.33 (Refresh)
D4: J4.9, MD1.B26 (/ASEL), SNES1.2 (Expand)
D5: J4.4, MD1.B15 (EDCLK)
D6: J3.30, MD1.B17 (/CE_0), SMS1.11 (M0-7), SMS1.36 (A15), SNES1.49 (/Cart)
D7: J3.31, JC2.1, MD1.B29 (/UWR), N64.21 (EEPROM_DATA), R1.2, SNES1.18 (/IRQ)
D8: J3.32, MD1.B28 (/LWR), N64.8 (/WRITE), SMS1.2 (WR), SNES1.54 (/WR)
D9: J3.33, MD1.B16 (/CAS0), N64.10 (/READ), SMS1.4 (RD), SNES1.23 (/RD)
D14: J4.11, MD1.B18 (/AS), SNES1.35 (/PAWR)
D15: J4.10, MD1.B31 (/TIME), SNES1.4 (/PARD)
D16: J3.29, MD1.B19 (VCLK), SMS1.47 (Clock)
D17: J3.28, MD1.B2 (/MRES), MD1.B27 (/VRES), N64.20 (RESET), SMS1.46 (Reset), SNES1.26 (/RESET)
D22: FC1.5 (PRG_A8), FC1.51 (CHR_A8), J4.12, MD1.A21 (D8), NES1.5 (PRG_A8), NES1.60 (CHR_A8), SNES1.28 (PA0)
D23: FC1.4 (PRG_A9), FC1.52 (CHR_A9), J4.13, MD1.A24 (D9), NES1.4 (PRG_A9), NES1.61 (CHR_A9), SNES1.59 (PA1)
D24: FC1.3 (PRG_A10), FC1.53 (CHR_A10), J4.14, MD1.A27 (D10), NES1.3 (PRG_A10), NES1.63 (CHR_A10), SNES1.29 (PA2)
D25: FC1.2 (PRG_A11), FC1.54 (CHR_A11), J4.15, MD1.A30 (D11), NES1.2 (PRG_A11), NES1.62 (CHR_A11), SNES1.60 (PA3)
D26: FC1.33 (PRG_A12), FC1.55 (CHR_A12), J4.16, MD1.B25 (D12), NES1.39 (PRG_A12), NES1.64 (CHR_A12), SNES1.30 (PA4)
D27: FC1.34 (PRG_A13), FC1.56 (CHR_A13), J4.17, MD1.B24 (D13), NES1.40 (PRG_A13), NES1.65 (CHR_A13), SNES1.61 (PA5)
D28: FC1.35 (PRG_A14), J4.18, MD1.B23 (D14), NES1.41 (PRG_A14), SNES1.3 (PA6)
D29: J4.19, MD1.B22 (D15), SNES1.34 (PA7)
D30: J3.27, MD1.A19 (D7), SMS1.14 (D7), SNES1.53 (D7)
D31: J3.26, MD1.A22 (D6), SMS1.15 (D6), SNES1.52 (D6)
D32: J3.25, MD1.A25 (D5), SMS1.16 (D5), SNES1.51 (D5)
D33: J3.24, MD1.A28 (D4), SMS1.17 (D4), SNES1.50 (D4)
D34: J3.23, MD1.A29 (D3), SMS1.18 (D3), SNES1.22 (D3)
D35: FC1.18 (CIRAM_A10), J3.22, MD1.A26 (D2), NES1.22 (CIRAM_A10), SMS1.22 (D2), SNES1.21 (D2)
D36: J3.21, MD1.A23 (D1), N64.35 (ALE_H), SMS1.23 (D1), SNES1.20 (D1)
D37: J3.20, MD1.A20 (D0), N64.33 (ALE_L), SMS1.24 (D0), SNES1.19 (D0)
D40: J4.8, JCIC1.4, MD1.B32 (/CART)
D41: J4.7, JCIC1.3
D42: FC1.6 (PRG_A7), FC1.50 (CHR_A7), J4.27, NES1.6 (PRG_A7), NES1.59 (CHR_A7), SNES1.48 (BA7)
D43: FC1.7 (PRG_A6), FC1.19 (CHR_A6), J4.26, MD1.B11 (A23), NES1.7 (PRG_A6), NES1.23 (CHR_A6), SNES1.47 (BA6)
D44: FC1.8 (PRG_A5), FC1.20 (CHR_A5), J4.25, MD1.B10 (A22), NES1.8 (PRG_A5), NES1.24 (CHR_A5), SNES1.46 (BA5)
D45: FC1.9 (PRG_A4), FC1.21 (CHR_A4), J4.24, MD1.B9 (A21), NES1.9 (PRG_A4), NES1.25 (CHR_A4), SNES1.45 (BA4)
D46: FC1.10 (PRG_A3), FC1.22 (CHR_A3), J4.23, MD1.B8 (A20), NES1.10 (PRG_A3), NES1.26 (CHR_A3), SNES1.44 (BA3)
D47: FC1.11 (PRG_A2), FC1.23 (CHR_A2), J4.22, MD1.B7 (A19), NES1.11 (PRG_A2), NES1.27 (CHR_A2), SNES1.43 (BA2)
D48: FC1.12 (PRG_A1), FC1.24 (CHR_A1), J4.21, MD1.B6 (A18), NES1.12 (PRG_A1), NES1.28 (CHR_A1), SMS1.13 (CE), SNES1.42 (BA1)
D49: FC1.13 (PRG_A0), FC1.25 (CHR_A0), J4.20, MD1.A16 (A17), NES1.13 (PRG_A0), NES1.29 (CHR_A0), SNES1.41 (BA0)
GND: FC1.1 (GND), FC1.16 (GND), J3.38, J4.1, JC3.1, JCIC1.8, M2_1.1, M2_2.1, M2_3.1, M2_4.1, M2_5.1, M2_6.1, M2_7.1, M2_8.1, M2_9.1, MD1.A1 (GND), MD1.A18 (GND), MD1.A32 (GND), N64.1 (GND), N64.2 (GND), N64.6 (GND), N64.22 (GND), N64.23 (GND), N64.25 (GND), N64.26 (GND), N64.27 (GND), N64.31 (GND), N64.47 (GND), N64.48 (GND), N64.50 (GND), NES1.1 (GND), NES1.72 (GND), SMS1.19 (GND), SMS1.20 (GND), SMS1.21 (GND), SNES1.5 (GND), SNES1.36 (GND)
VCC: FC1.30 (5V), FC1.31 (VCC), J3.1, J4.36, JC1.1, JCIC1.1, MD1.A2 (VCC), MD1.A31 (VCC), N64.9 (VCC), N64.17 (VCC), N64.34 (VCC), N64.42 (VCC), NES1.36 (VCC), R1.1, SMS1.1 (5V), SMS1.35 (5V), SNES1.27 (VCC), SNES1.58 (VCC)

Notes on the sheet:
Mounting Holes

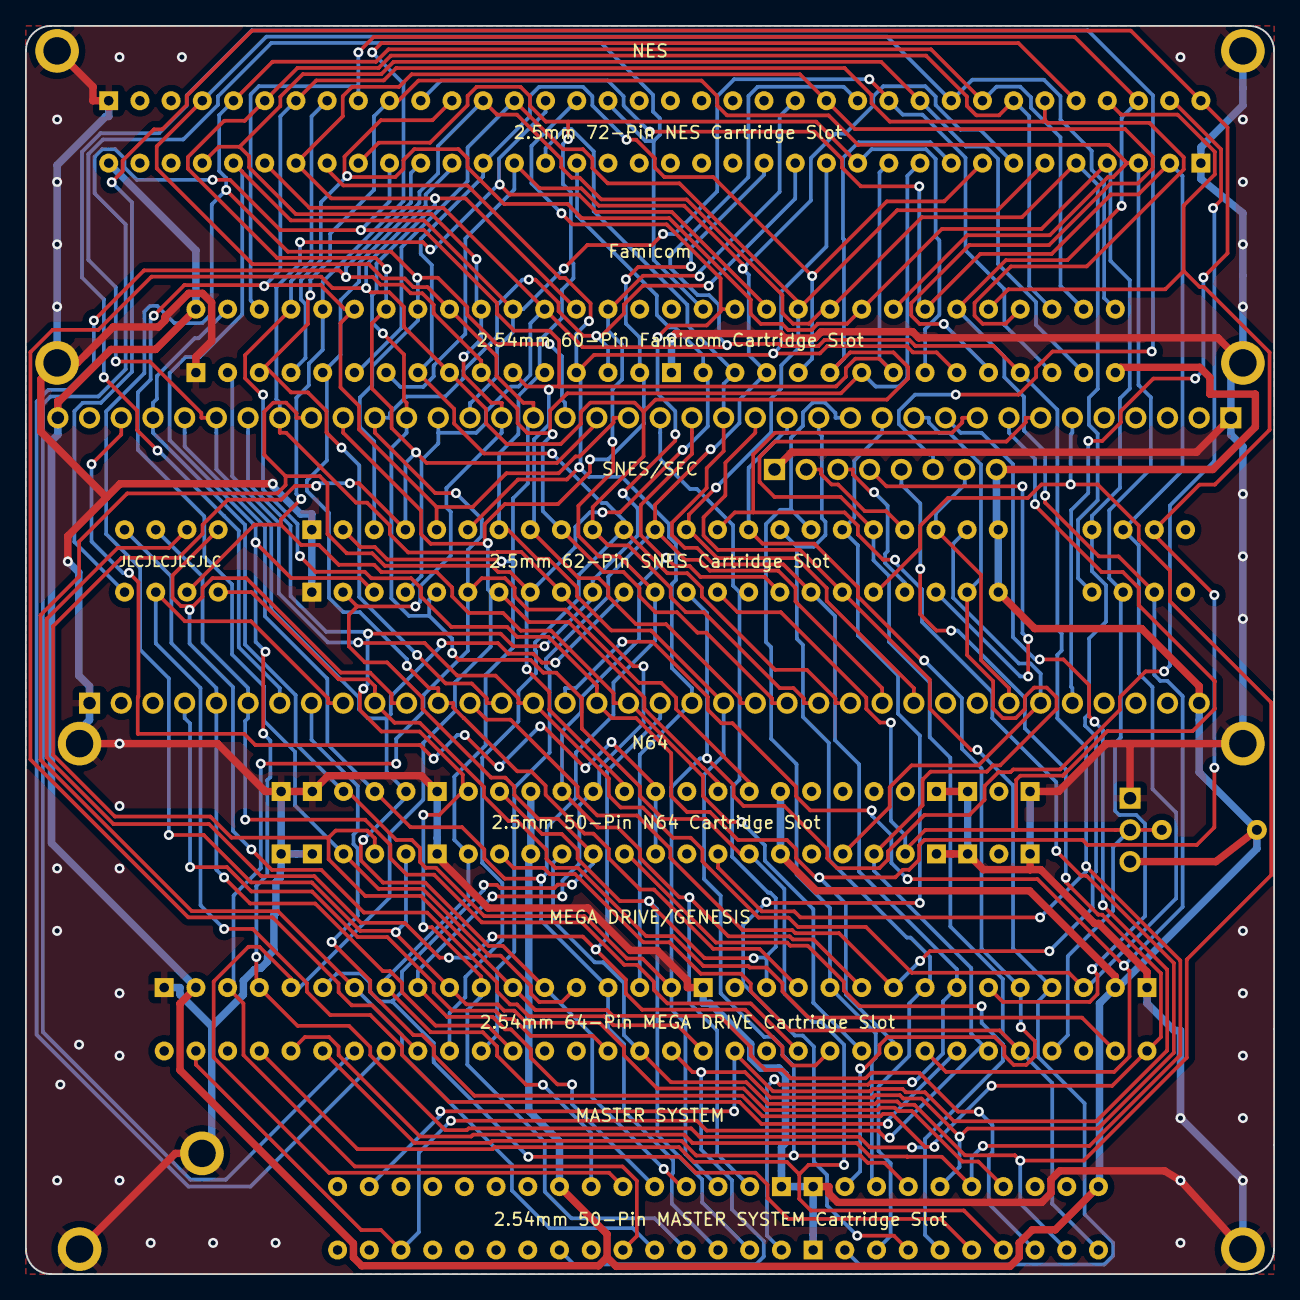
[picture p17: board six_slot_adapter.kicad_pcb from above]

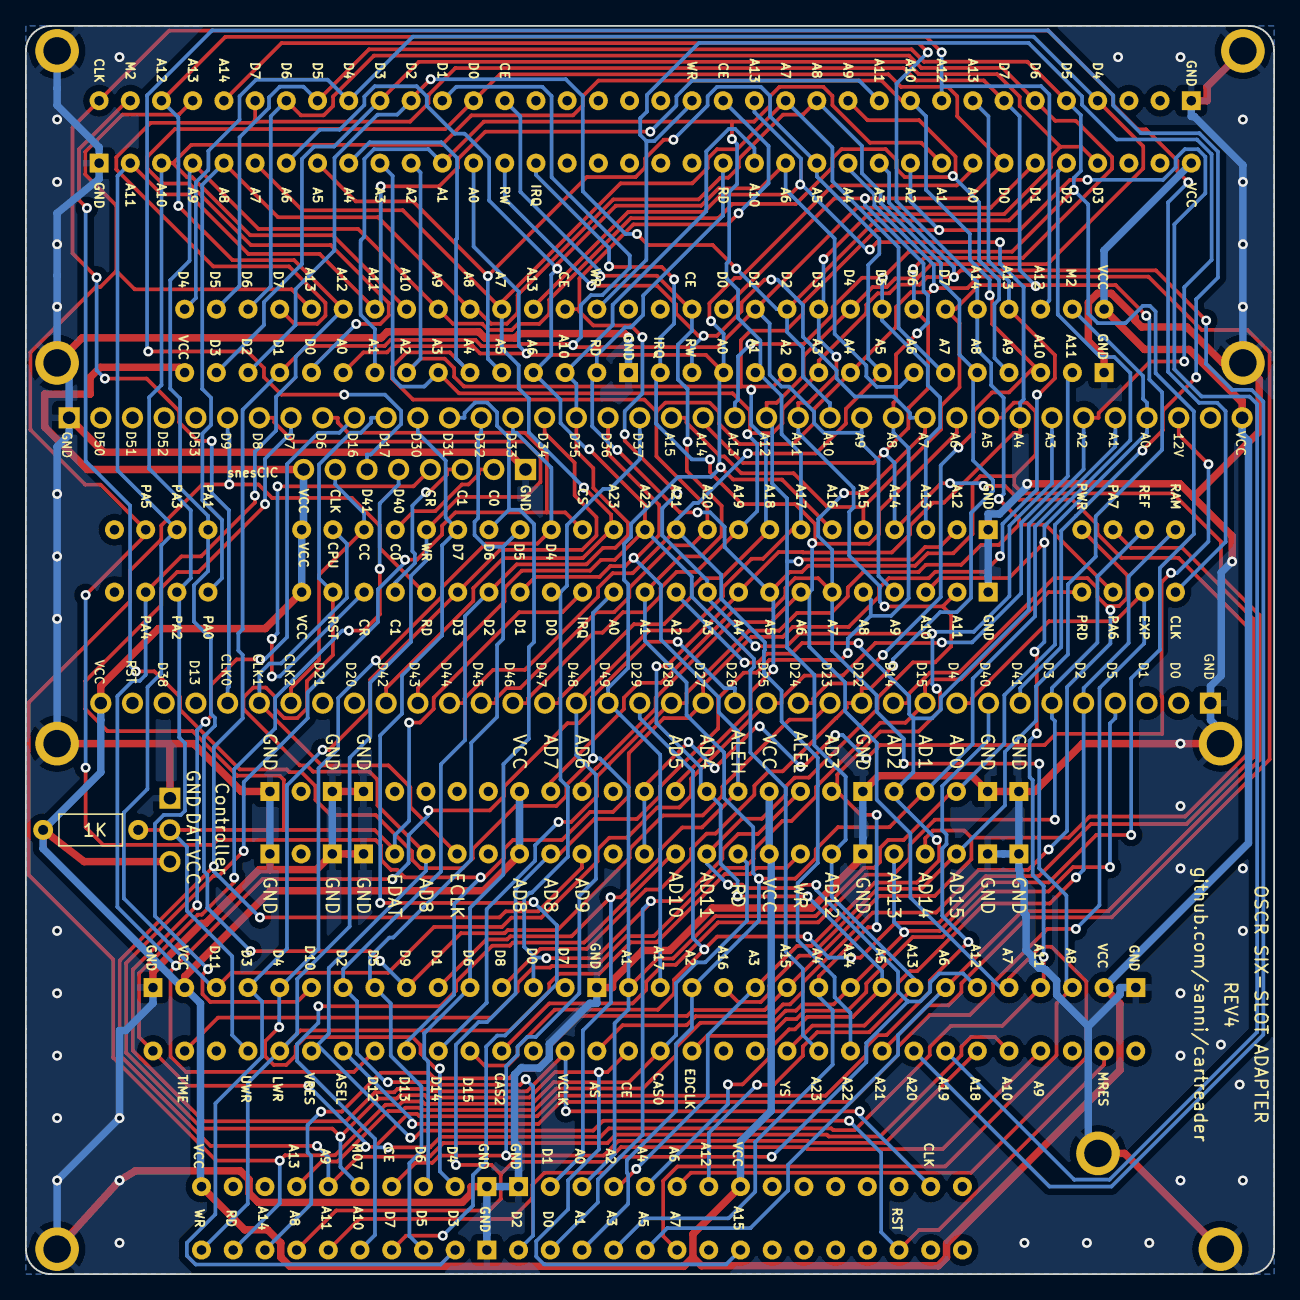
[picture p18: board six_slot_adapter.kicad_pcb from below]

Board: 2 copper layers, 100.0 x 100.0 mm, 22 parts (11 on the bottom side), 63 nets.

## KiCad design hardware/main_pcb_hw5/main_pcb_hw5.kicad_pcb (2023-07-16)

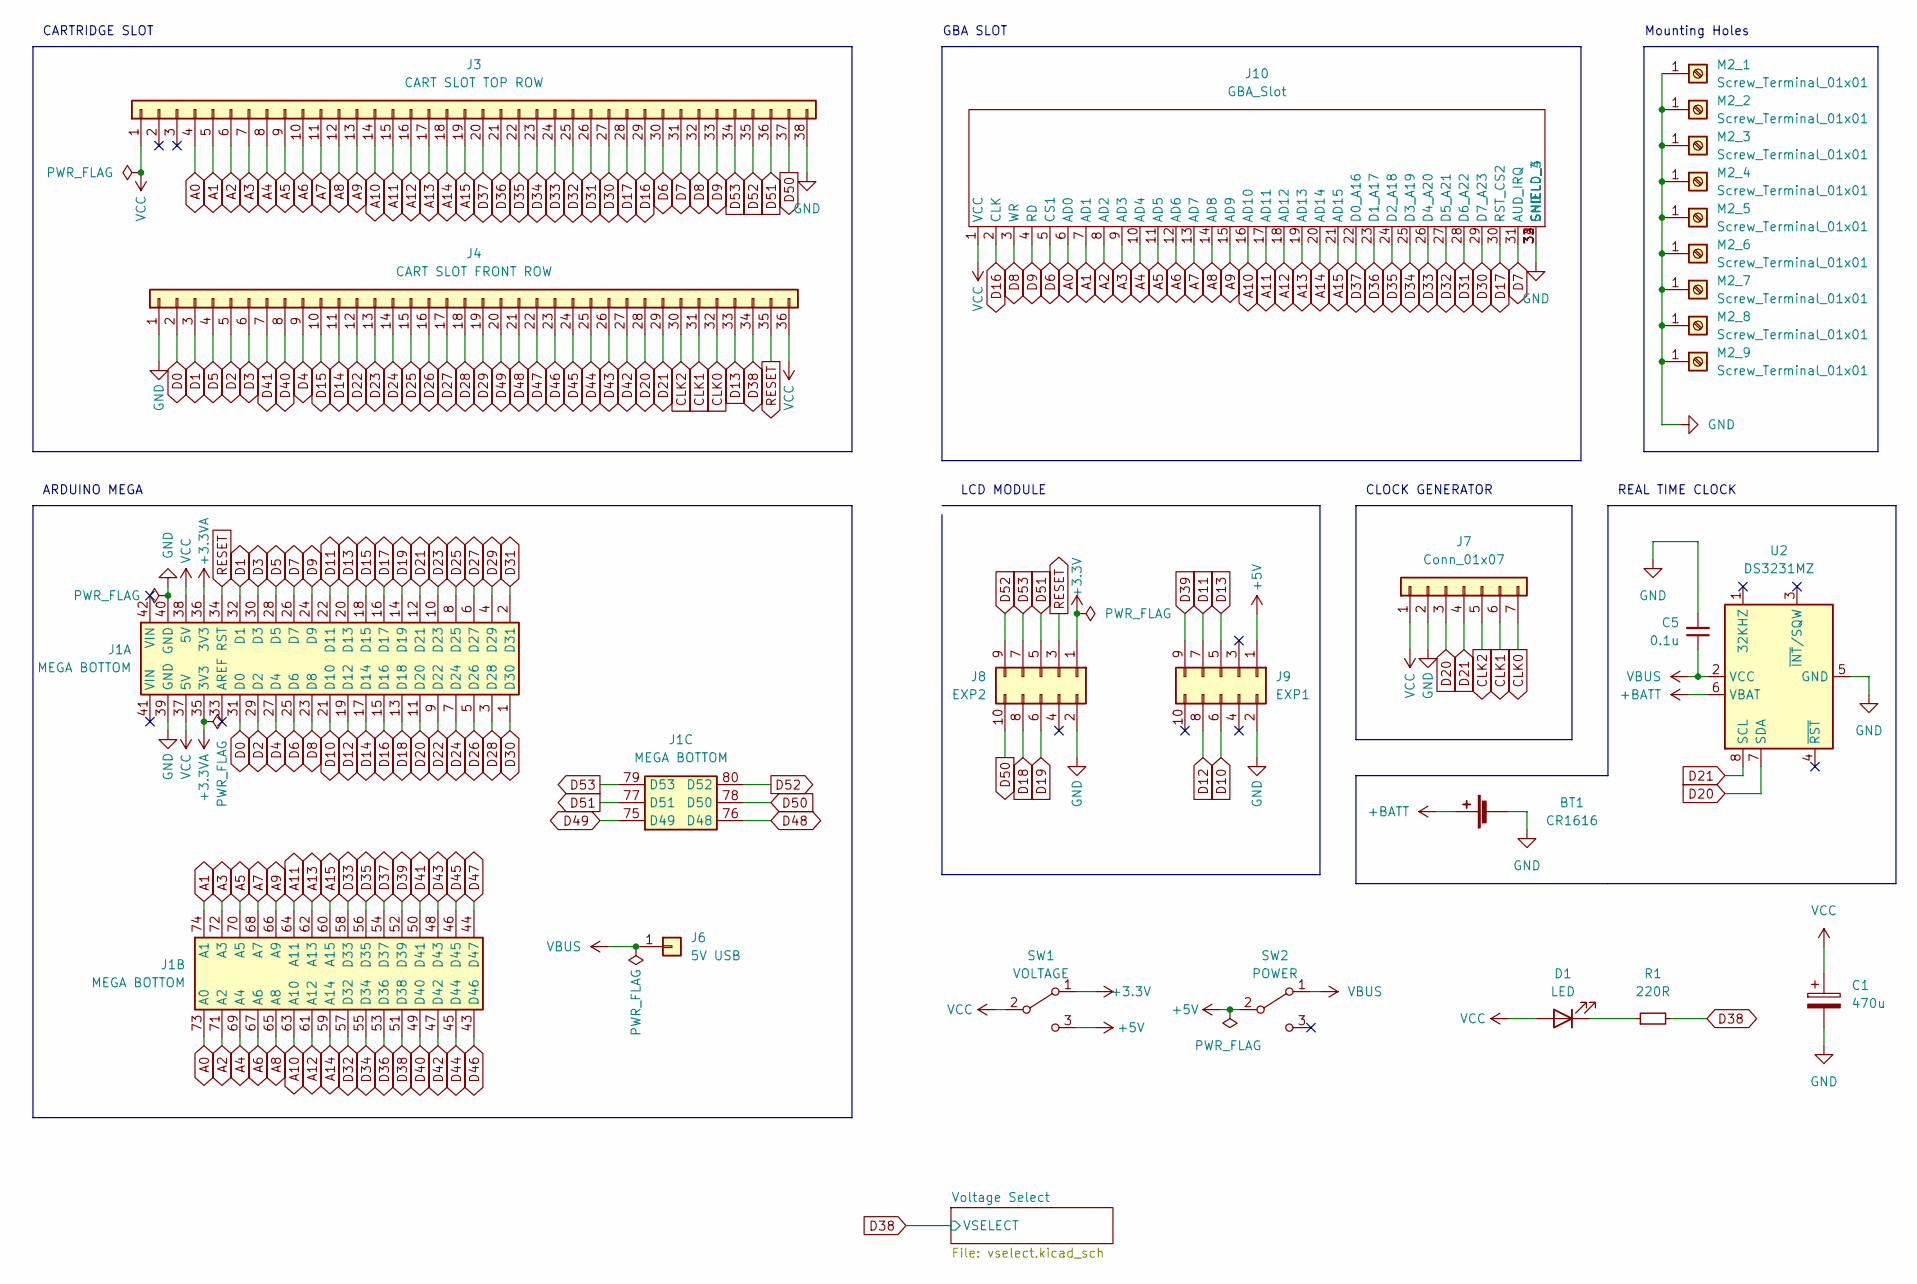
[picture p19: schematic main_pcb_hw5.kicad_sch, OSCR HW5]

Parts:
BT1: CR1616
C1: 470u; CP_Radial_D8.0mm_P3.50mm
C5: 0.1u; C_0402_1005Metric_Pad0.74x0.62mm_HandSolder; JLCPCB C307331
D1: LED; LED_D3.0mm
J1: MEGA BOTTOM; MEGA2560_PRO_MINI
J3: CART SLOT TOP ROW; Cartridge_Port_Adapter-Back
J4: CART SLOT FRONT ROW; Cartridge_Port_Adapter-Front
J6: 5V USB; PinHeader_1x01_P2.54mm_Vertical
J7: Conn_01x07; Clock_Generator_Header
J8: EXP2; LCD_Header
J9: EXP1; LCD_Header
J10: GBA_Slot
M2_1, M2_2, M2_3, M2_4, M2_5, M2_6, M2_7, M2_8, M2_9: Screw_Terminal_01x01
R1: 220R; R_Axial_DIN0207_L6.3mm_D2.5mm_P10.16mm_Horizontal
SW1: VOLTAGE; Power_Switch
SW2: POWER; Power_Switch
U2: DS3231MZ; SOIC-8_3.9x4.9mm_P1.27mm

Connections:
+3.3VA: J1.35 (3V3), J1.36 (3V3)
+5V: J9.1, SW1.3 (C), SW2.2 (B); also elsewhere on the board
+BATT: BT1.1 (+), U2.6 (VBAT)
A0: J1.73 (A0), J3.4, J10.6 (AD0)
A1: J1.74 (A1), J3.5, J10.7 (AD1)
A2: J1.71 (A2), J3.6, J10.8 (AD2)
A3: J1.72 (A3), J3.7, J10.9 (AD3)
A4: J1.69 (A4), J3.8, J10.10 (AD4)
A5: J1.70 (A5), J3.9, J10.11 (AD5)
A6: J1.67 (A6), J3.10, J10.12 (AD6)
A7: J1.68 (A7), J3.11, J10.13 (AD7)
A8: J1.65 (A8), J3.12, J10.14 (AD8)
A9: J1.66 (A9), J3.13, J10.15 (AD9)
A10: J1.63 (A10), J3.14, J10.16 (AD10)
A11: J1.64 (A11), J3.15, J10.17 (AD11)
A12: J1.61 (A12), J3.16, J10.18 (AD12)
A13: J1.62 (A13), J3.17, J10.19 (AD13)
A14: J1.59 (A14), J3.18, J10.20 (AD14)
A15: J1.60 (A15), J3.19, J10.21 (AD15)
CLK0: J4.32, J7.7
CLK1: J4.31, J7.6
CLK2: J4.30, J7.5
D0: J1.31 (D0), J4.2
D1: J1.32 (D1), J4.3
D2: J1.29 (D2), J4.5
D3: J1.30 (D3), J4.6
D4: J1.27 (D4), J4.9
D5: J1.28 (D5), J4.4
D6: J1.25 (D6), J3.30, J10.5 (CS1)
D7: J1.26 (D7), J3.31, J10.31 (AUD_IRQ)
D8: J1.23 (D8), J3.32, J10.3 (WR)
D9: J1.24 (D9), J3.33, J10.4 (RD)
D10: J1.21 (D10), J9.6
D11: J1.22 (D11), J9.7
D12: J1.19 (D12), J9.8
D13: J1.20 (D13), J4.33, J9.5
D14: J1.17 (D14), J4.11
D15: J1.18 (D15), J4.10
D16: J1.15 (D16), J3.29, J10.2 (CLK)
D17: J1.16 (D17), J3.28, J10.30 (RST_CS2)
D18: J1.13 (D18), J8.8
D19: J1.14 (D19), J8.6
D20: J1.11 (D20), J4.28, J7.3, U2.7 (SDA)
D21: J1.12 (D21), J4.29, J7.4, U2.8 (SCL)
D22: J1.9 (D22), J4.12
D23: J1.10 (D23), J4.13
D24: J1.7 (D24), J4.14
D25: J1.8 (D25), J4.15
D26: J1.5 (D26), J4.16
D27: J1.6 (D27), J4.17
D28: J1.3 (D28), J4.18
D29: J1.4 (D29), J4.19
D30: J1.1 (D30), J3.27, J10.29 (D7_A23)
D31: J1.2 (D31), J3.26, J10.28 (D6_A22)
D32: J1.57 (D32), J3.25, J10.27 (D5_A21)
D33: J1.58 (D33), J3.24, J10.26 (D4_A20)
D34: J1.55 (D34), J3.23, J10.25 (D3_A19)
D35: J1.56 (D35), J3.22, J10.24 (D2_A18)
D36: J1.53 (D36), J3.21, J10.23 (D1_A17)
D37: J1.54 (D37), J3.20, J10.22 (D0_A16)
D38: J1.51 (D38), J4.34, R1.2; also elsewhere on the board
D39: J1.52 (D39), J9.9
D40: J1.49 (D40), J4.8
D41: J1.50 (D41), J4.7
D42: J1.47 (D42), J4.27
D43: J1.48 (D43), J4.26
D44: J1.45 (D44), J4.25
D45: J1.46 (D45), J4.24
D46: J1.43 (D46), J4.23
D47: J1.44 (D47), J4.22
D48: J1.76 (D48), J4.21
D49: J1.75 (D49), J4.20
D50: J1.78 (D50), J3.37, J8.10
D51: J1.77 (D51), J3.36, J8.5
D52: J1.80 (D52), J3.35, J8.9
D53: J1.79 (D53), J3.34, J8.7
GND: BT1.2 (-), C1.2, C5.2, J1.39 (GND), J1.40 (GND), J3.38, J4.1, J7.2, J8.2, J9.2, J10.32 (GND), J10.33 (SHIELD_3), J10.34 (SHIELD_4), M2_1.1, M2_2.1, M2_3.1, M2_4.1, M2_5.1, M2_6.1, M2_7.1, M2_8.1, M2_9.1, U2.5 (GND); also elsewhere on the board
unnamed: D1.1 (K), R1.1
RESET: J1.34 (RST), J4.35, J8.3
VBUS: C5.1, J6.1, SW2.1 (A), U2.2 (VCC)
VCC: C1.1, D1.2 (A), J1.37 (5V), J1.38 (5V), J3.1, J4.36, J7.1, J10.1 (VCC), SW1.2 (B); also elsewhere on the board

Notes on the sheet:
LCD MODULE
REAL TIME CLOCK
CLOCK GENERATOR
CARTRIDGE SLOT
GBA SLOT
ARDUINO MEGA
Mounting Holes

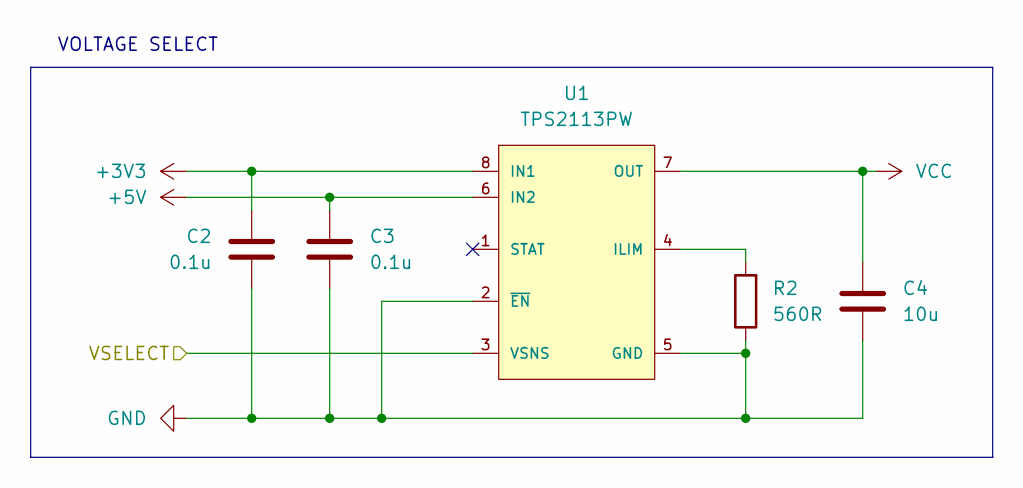
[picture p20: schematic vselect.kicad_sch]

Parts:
C2, C3: 0.1u; C_0402_1005Metric_Pad0.74x0.62mm_HandSolder; JLCPCB C307331
C4: 10u; C_0402_1005Metric_Pad0.74x0.62mm_HandSolder; JLCPCB C15525
R2: 560R; R_0402_1005Metric_Pad0.72x0.64mm_HandSolder; JLCPCB C137858
U1: TPS2113PW; Texas_Instruments-TPS2113PW-Level_A

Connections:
+5V: C3.1, U1.6 (IN2); also elsewhere on the board
D38: U1.3 (VSNS); also elsewhere on the board
GND: C2.1, C3.2, C4.2, R2.1, U1.2 (~EN), U1.5 (GND); also elsewhere on the board
unnamed: R2.2, U1.4 (ILIM)
VCC: C4.1, U1.7 (OUT); also elsewhere on the board

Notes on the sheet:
VOLTAGE SELECT

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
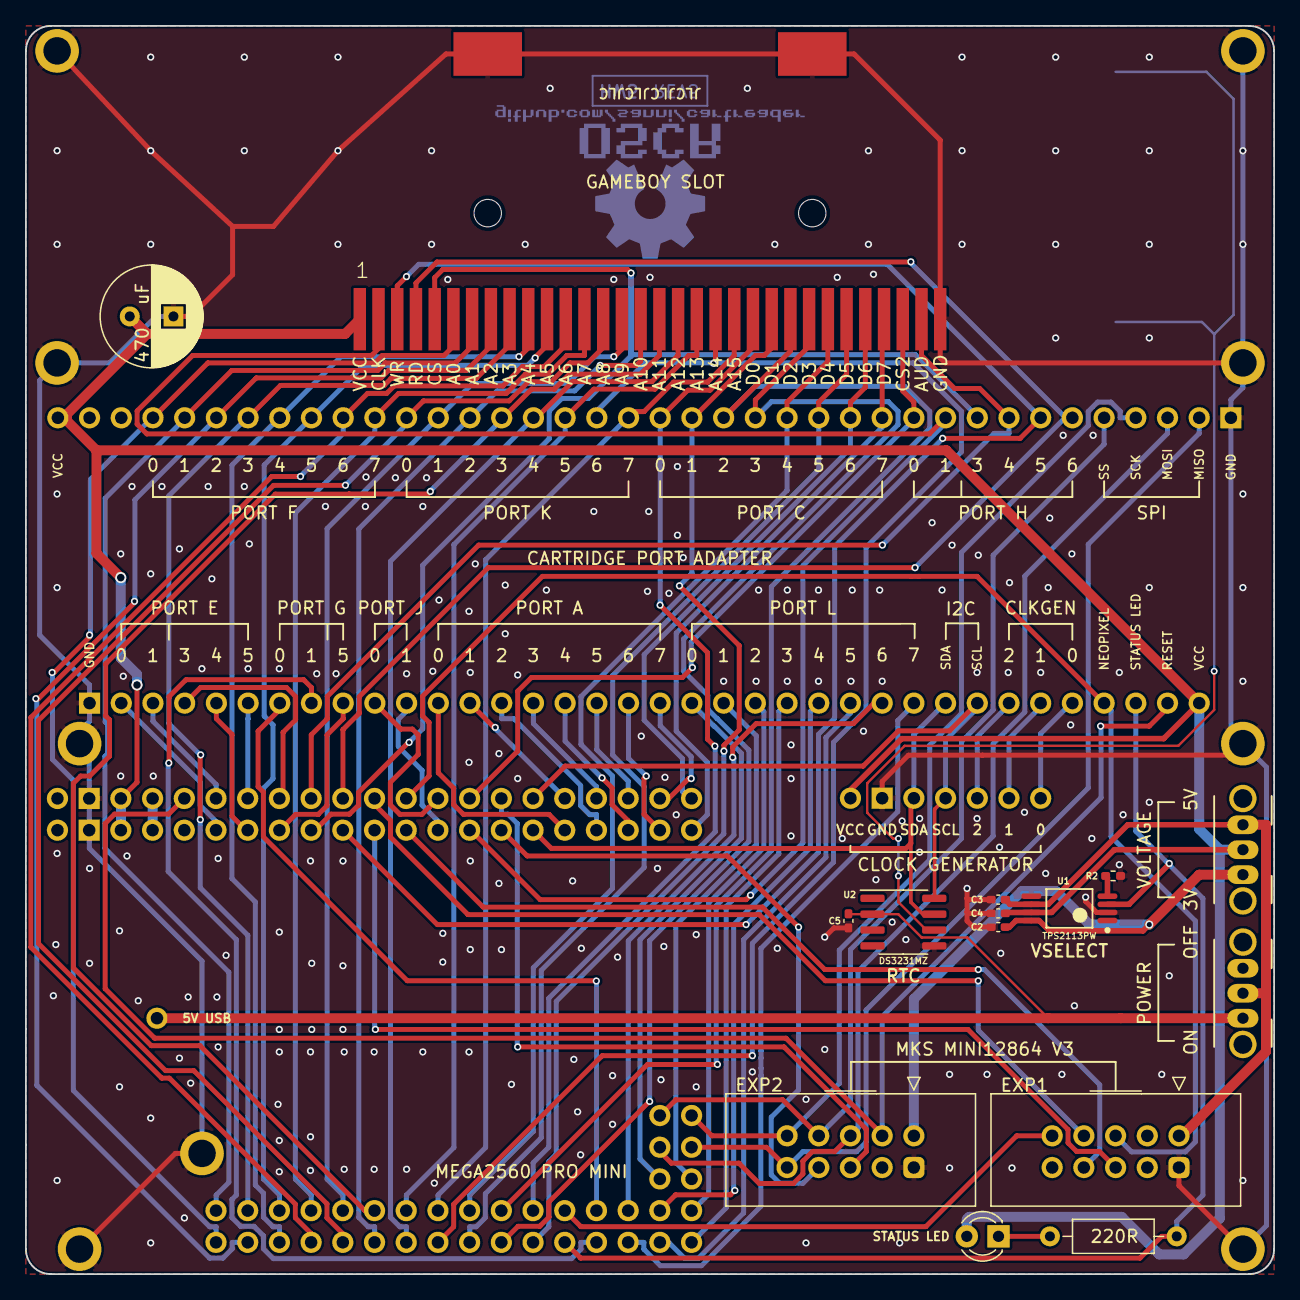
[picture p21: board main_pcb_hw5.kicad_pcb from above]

Board: 2 copper layers, 100.0 x 100.0 mm, 30 parts (1 on the bottom side), 83 nets.

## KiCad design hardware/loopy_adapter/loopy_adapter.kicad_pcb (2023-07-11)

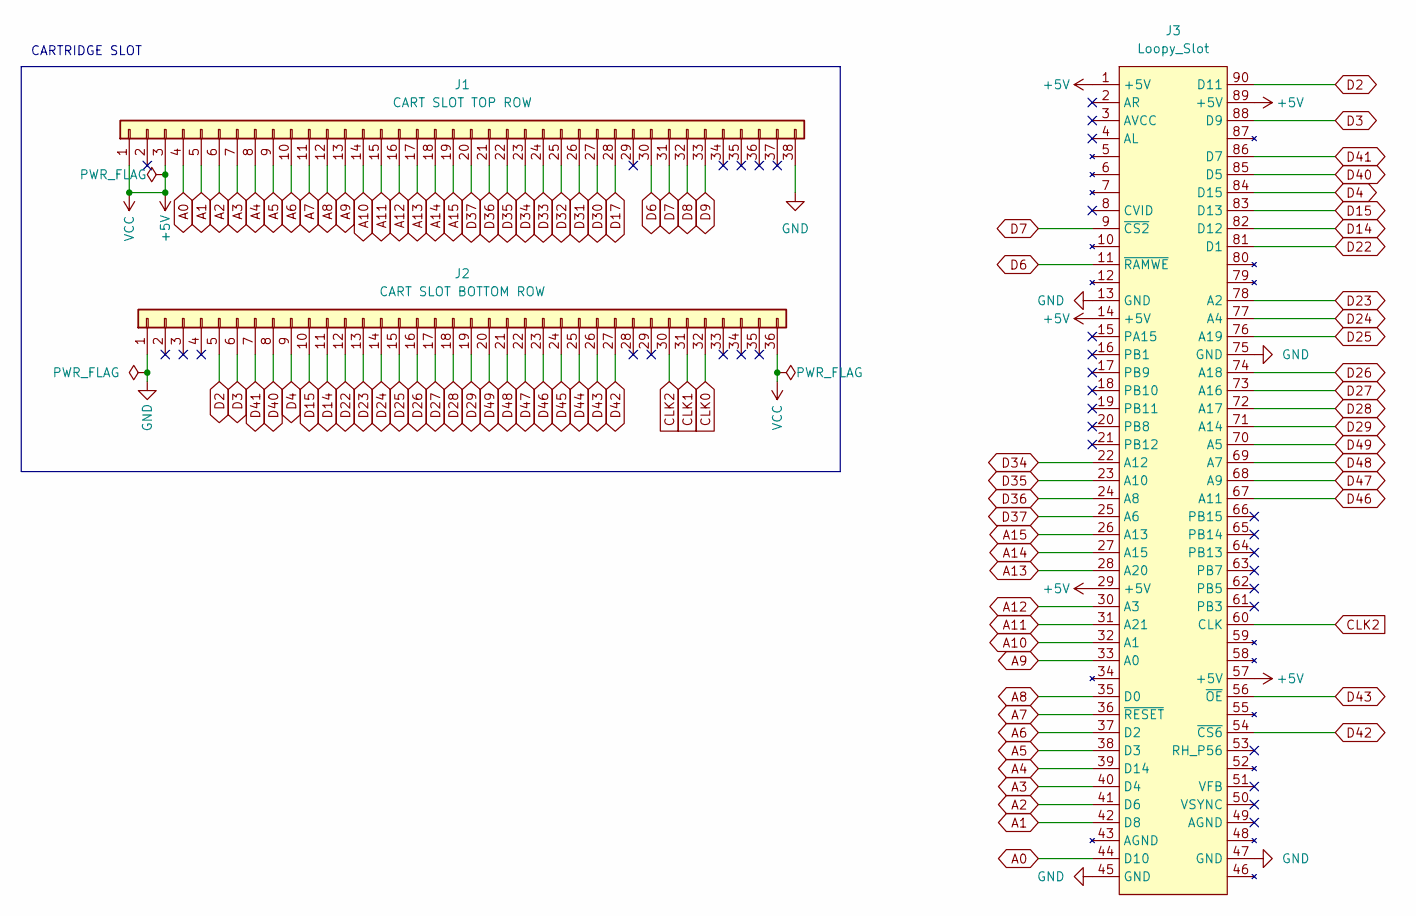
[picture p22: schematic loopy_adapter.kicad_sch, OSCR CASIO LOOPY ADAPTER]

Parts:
J1: CART SLOT TOP ROW; PinSocket_1x38_P2.54mm_Vertical
J2: CART SLOT BOTTOM ROW; PinSocket_1x36_P2.54mm_Vertical
J3: Loopy_Slot

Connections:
+5V: J1.1, J1.3, J2.36, J3.1 (+5V), J3.14 (+5V), J3.29 (+5V), J3.57 (+5V), J3.89 (+5V)
A0: J1.4, J3.44 (D10)
A1: J1.5, J3.42 (D8)
A2: J1.6, J3.41 (D6)
A3: J1.7, J3.40 (D4)
A4: J1.8, J3.39 (D14)
A5: J1.9, J3.38 (D3)
A6: J1.10, J3.37 (D2)
A7: J1.11, J3.36 (~RESET)
A8: J1.12, J3.35 (D0)
A9: J1.13, J3.33 (A0)
A10: J1.14, J3.32 (A1)
A11: J1.15, J3.31 (A21)
A12: J1.16, J3.30 (A3)
A13: J1.17, J3.28 (A20)
A14: J1.18, J3.27 (A15)
A15: J1.19, J3.26 (A13)
CLK0: J2.32
CLK1: J2.31
CLK2: J2.30, J3.60 (CLK)
D2: J2.5, J3.90 (D11)
D3: J2.6, J3.88 (D9)
D4: J2.9, J3.84 (D15)
D6: J1.30, J3.11 (~RAMWE)
D7: J1.31, J3.9 (~CS2)
D8: J1.32
D9: J1.33
D14: J2.11, J3.82 (D12)
D15: J2.10, J3.83 (D13)
D17: J1.28
D22: J2.12, J3.81 (D1)
D23: J2.13, J3.78 (A2)
D24: J2.14, J3.77 (A4)
D25: J2.15, J3.76 (A19)
D26: J2.16, J3.74 (A18)
D27: J2.17, J3.73 (A16)
D28: J2.18, J3.72 (A17)
D29: J2.19, J3.71 (A14)
D30: J1.27
D31: J1.26
D32: J1.25
D33: J1.24
D34: J1.23, J3.22 (A12)
D35: J1.22, J3.23 (A10)
D36: J1.21, J3.24 (A8)
D37: J1.20, J3.25 (A6)
D40: J2.8, J3.85 (D5)
D41: J2.7, J3.86 (D7)
D42: J2.27, J3.54 (~CS6)
D43: J2.26, J3.56 (~OE)
D44: J2.25
D45: J2.24
D46: J2.23, J3.67 (A11)
D47: J2.22, J3.68 (A9)
D48: J2.21, J3.69 (A7)
D49: J2.20, J3.70 (A5)
GND: J1.38, J2.1, J3.13 (GND), J3.45 (GND), J3.47 (GND), J3.75 (GND)

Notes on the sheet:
CARTRIDGE SLOT

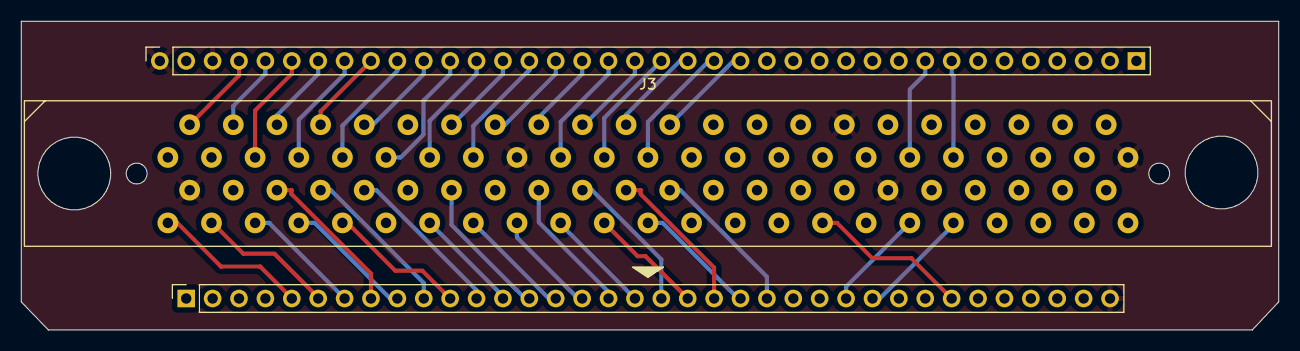
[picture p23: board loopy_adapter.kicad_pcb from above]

Board: 2 copper layers, 121.0 x 29.7 mm, 3 parts (0 on the bottom side), 46 nets.

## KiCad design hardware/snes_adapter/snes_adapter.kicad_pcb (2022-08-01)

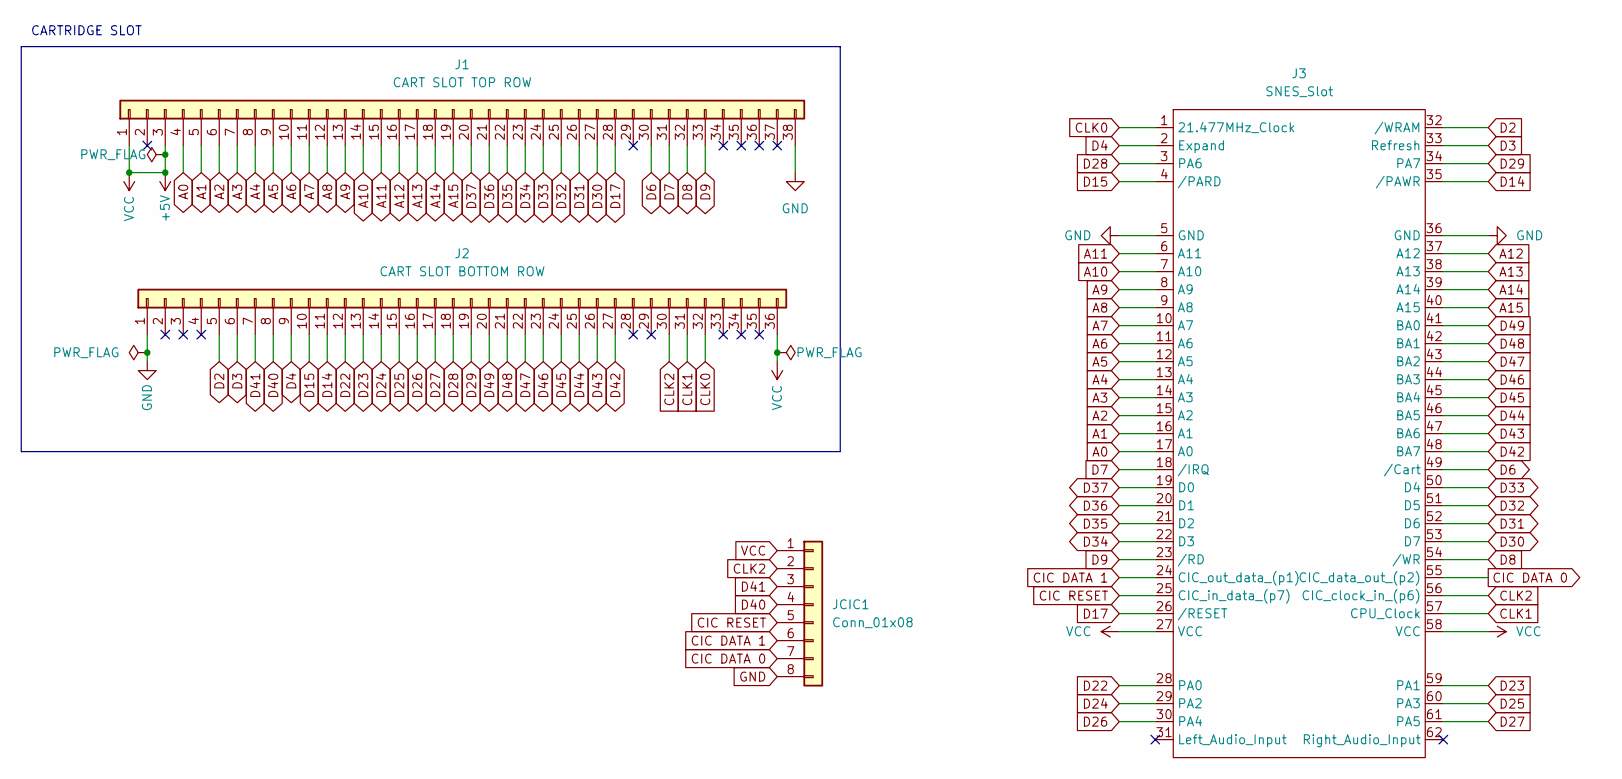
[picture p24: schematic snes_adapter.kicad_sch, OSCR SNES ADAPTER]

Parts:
J1: CART SLOT TOP ROW; PinSocket_1x38_P2.54mm_Vertical
J2: CART SLOT BOTTOM ROW; PinSocket_1x36_P2.54mm_Vertical
J3: SNES_Slot
JCIC1: Conn_01x08

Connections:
A0: J1.4, J3.17 (A0)
A1: J1.5, J3.16 (A1)
A2: J1.6, J3.15 (A2)
A3: J1.7, J3.14 (A3)
A4: J1.8, J3.13 (A4)
A5: J1.9, J3.12 (A5)
A6: J1.10, J3.11 (A6)
A7: J1.11, J3.10 (A7)
A8: J1.12, J3.9 (A8)
A9: J1.13, J3.8 (A9)
A10: J1.14, J3.7 (A10)
A11: J1.15, J3.6 (A11)
A12: J1.16, J3.37 (A12)
A13: J1.17, J3.38 (A13)
A14: J1.18, J3.39 (A14)
A15: J1.19, J3.40 (A15)
CIC DATA 0: J3.55 (CIC_data_out_(p2)), JCIC1.7
CIC DATA 1: J3.24 (CIC_out_data_(p1)), JCIC1.6
CIC RESET: J3.25 (CIC_in_data_(p7)), JCIC1.5
CLK0: J2.32, J3.1 (21.477MHz_Clock)
CLK1: J2.31, J3.57 (CPU_Clock)
CLK2: J2.30, J3.56 (CIC_clock_in_(p6)), JCIC1.2
D2: J2.5, J3.32 (/WRAM)
D3: J2.6, J3.33 (Refresh)
D4: J2.9, J3.2 (Expand)
D6: J1.30, J3.49 (/Cart)
D7: J1.31, J3.18 (/IRQ)
D8: J1.32, J3.54 (/WR)
D9: J1.33, J3.23 (/RD)
D14: J2.11, J3.35 (/PAWR)
D15: J2.10, J3.4 (/PARD)
D17: J1.28, J3.26 (/RESET)
D22: J2.12, J3.28 (PA0)
D23: J2.13, J3.59 (PA1)
D24: J2.14, J3.29 (PA2)
D25: J2.15, J3.60 (PA3)
D26: J2.16, J3.30 (PA4)
D27: J2.17, J3.61 (PA5)
D28: J2.18, J3.3 (PA6)
D29: J2.19, J3.34 (PA7)
D30: J1.27, J3.53 (D7)
D31: J1.26, J3.52 (D6)
D32: J1.25, J3.51 (D5)
D33: J1.24, J3.50 (D4)
D34: J1.23, J3.22 (D3)
D35: J1.22, J3.21 (D2)
D36: J1.21, J3.20 (D1)
D37: J1.20, J3.19 (D0)
D40: J2.8, JCIC1.4
D41: J2.7, JCIC1.3
D42: J2.27, J3.48 (BA7)
D43: J2.26, J3.47 (BA6)
D44: J2.25, J3.46 (BA5)
D45: J2.24, J3.45 (BA4)
D46: J2.23, J3.44 (BA3)
D47: J2.22, J3.43 (BA2)
D48: J2.21, J3.42 (BA1)
D49: J2.20, J3.41 (BA0)
GND: J1.38, J2.1, J3.5 (GND), J3.36 (GND), JCIC1.8
VCC: J1.1, J1.3, J2.36, J3.27 (VCC), J3.58 (VCC), JCIC1.1

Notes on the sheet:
CARTRIDGE SLOT

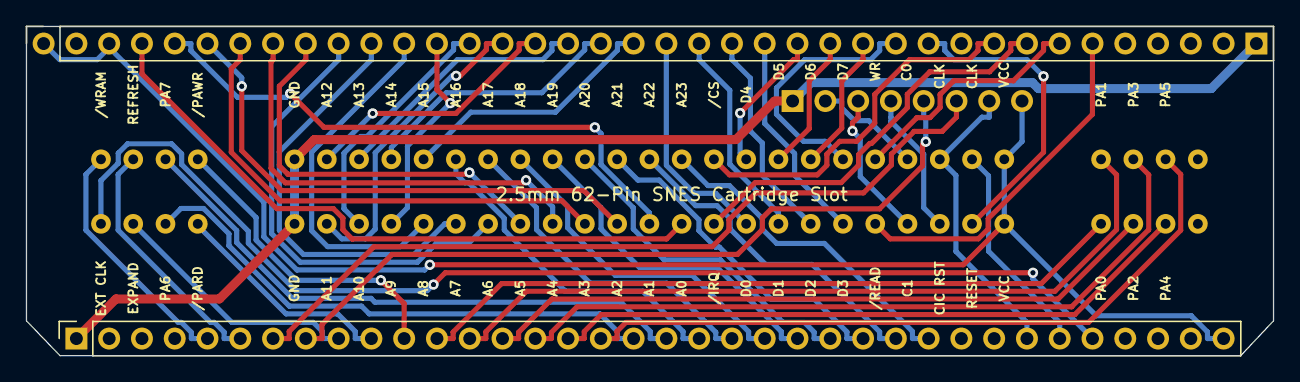
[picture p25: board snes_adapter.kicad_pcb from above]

Board: 2 copper layers, 96.6 x 25.5 mm, 4 parts (1 on the bottom side), 60 nets.

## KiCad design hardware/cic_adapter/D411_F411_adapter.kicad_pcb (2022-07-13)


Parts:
C1: 100nF
C2: 2.2uF
D411: DIP CIC
F411: SMD CIC
JCIC1: Conn_01x08

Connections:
CIC DATA 0: D411.1, F411.1, JCIC1.7
CIC DATA 1: D411.2, F411.2, JCIC1.6
CIC RESET: D411.10, F411.11, JCIC1.5
CLK2: D411.6, F411.7, JCIC1.2
D40: D411.7, F411.8, JCIC1.4
D41: D411.9, F411.10, JCIC1.3
GND: C1.2, D411.8, F411.9, JCIC1.8
RANDOM: C2.2, D411.3, F411.3
VCC: C1.1, C2.1, D411.4, D411.16, F411.4, F411.18, JCIC1.1


Board: 2 copper layers, 33.5 x 18.3 mm, 5 parts (1 on the bottom side), 9 nets.

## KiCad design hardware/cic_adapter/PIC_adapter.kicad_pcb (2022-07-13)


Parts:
C1: C_Small
JCIC1: Conn_01x08
PIC12F629: snesCIC
PIC16F630: SuperCIC
SMD_PIC12F629: snesCIC

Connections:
CIC DATA 0: JCIC1.7, PIC12F629.7, PIC16F630.10, SMD_PIC12F629.7
CIC DATA 1: JCIC1.6, PIC12F629.6, PIC16F630.9, SMD_PIC12F629.6
CIC RESET: JCIC1.5, PIC12F629.5, PIC16F630.8, SMD_PIC12F629.5
CLK2: JCIC1.2, PIC12F629.2, PIC16F630.2, SMD_PIC12F629.2
D40: JCIC1.4, PIC12F629.4, PIC16F630.13, SMD_PIC12F629.4
D41: JCIC1.3, PIC12F629.3, PIC16F630.11, SMD_PIC12F629.3
GND: C1.2, JCIC1.8, PIC12F629.8, PIC16F630.7, PIC16F630.14, SMD_PIC12F629.8
VCC: C1.1, JCIC1.1, PIC12F629.1, PIC16F630.1, PIC16F630.4, SMD_PIC12F629.1


Board: 2 copper layers, 33.5 x 18.3 mm, 5 parts (1 on the bottom side), 8 nets.

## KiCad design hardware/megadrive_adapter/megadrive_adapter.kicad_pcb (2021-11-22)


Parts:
J1: CART SLOT TOP ROW; PinSocket_1x38_P2.54mm_Vertical
J2: CART SLOT BOTTOM ROW; PinSocket_1x36_P2.54mm_Vertical
U1: MD_Slot

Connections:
+3V3: J1.2
A0: J1.4, U1.A17 (A1)
A1: J1.5, U1.A15 (A2)
A2: J1.6, U1.A13 (A3)
A3: J1.7, U1.A11 (A4)
A4: J1.8, U1.A9 (A5)
A5: J1.9, U1.A7 (A6)
A6: J1.10, U1.A5 (A7)
A7: J1.11, U1.A3 (A8)
A8: J1.12, U1.B4 (A9)
A9: J1.13, U1.B5 (A10)
A10: J1.14, U1.A4 (A11)
A11: J1.15, U1.A6 (A12)
A12: J1.16, U1.A8 (A13)
A13: J1.17, U1.A10 (A14)
A14: J1.18, U1.A12 (A15)
A15: J1.19, U1.A14 (A16)
CLK0: J2.32
CLK1: J2.31
CLK2: J2.30
D0: J2.2
D1: J2.3
D2: J2.5, U1.B12 (/YS)
D3: J2.6, U1.B21 (/CAS2)
D4: J2.9, U1.B26 (/ASEL)
D5: J2.4, U1.B15 (EDCLK)
D6: J1.30, U1.B17 (/CE_0)
D7: J1.31, U1.B29 (/UWR)
D8: J1.32, U1.B28 (/LWR)
D9: J1.33, U1.B16 (/CAS0)
D13: J2.33
D14: J2.11, U1.B18 (/AS)
D15: J2.10, U1.B31 (/TIME)
D16: J1.29, U1.B19 (VCLK)
D17: J1.28, U1.B2 (/MRES), U1.B27 (/VRES)
D20: J2.28
D21: J2.29
D22: J2.12, U1.A21 (D8)
D23: J2.13, U1.A24 (D9)
D24: J2.14, U1.A27 (D10)
D25: J2.15, U1.A30 (D11)
D26: J2.16, U1.B25 (D12)
D27: J2.17, U1.B24 (D13)
D28: J2.18, U1.B23 (D14)
D29: J2.19, U1.B22 (D15)
D30: J1.27, U1.A19 (D7)
D31: J1.26, U1.A22 (D6)
D32: J1.25, U1.A25 (D5)
D33: J1.24, U1.A28 (D4)
D34: J1.23, U1.A29 (D3)
D35: J1.22, U1.A26 (D2)
D36: J1.21, U1.A23 (D1)
D37: J1.20, U1.A20 (D0)
D38: J2.34
D40: J2.8
D41: J2.7
D42: J2.27
D43: J2.26, U1.B11 (A23)
D44: J2.25, U1.B10 (A22)
D45: J2.24, U1.B9 (A21)
D46: J2.23, U1.B8 (A20)
D47: J2.22, U1.B7 (A19)
D48: J2.21, U1.B6 (A18)
D49: J2.20, U1.A16 (A17)
D50: J1.37
D51: J1.36
D52: J1.35
D53: J1.34
GND: J1.38, J2.1, U1.A1 (GND), U1.A18 (GND), U1.A32 (GND)
RESET: J2.35
VCC: J1.1, J1.3, J2.36, U1.A2 (VCC), U1.A31 (VCC)

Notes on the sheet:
CARTRIDGE SLOT


Board: 2 copper layers, 96.6 x 25.5 mm, 3 parts (0 on the bottom side), 53 nets.

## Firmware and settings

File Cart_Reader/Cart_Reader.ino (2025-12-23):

/**********************************************************************************
                    Cartridge Reader for Arduino Mega2560

   This project represents a community-driven effort to provide
   an easy to build and easy to modify cartridge dumper.

   SD lib: https://github.com/greiman/SdFat
   LCD lib: https://github.com/olikraus/u8g2
   Neopixel lib: https://github.com/adafruit/Adafruit_NeoPixel
   Rotary Enc lib: https://github.com/mathertel/RotaryEncoder
   SI5351 lib: https://github.com/etherkit/Si5351Arduino
   RTC lib: https://github.com/adafruit/RTClib
   Frequency lib: https://github.com/PaulStoffregen/FreqCount

   Thanks to:
   MichlK - ROM Reader for Super Nintendo
   Jeff Saltzman - 4-Way Button
   Wayne and Layne - Video Game Shield menu
   skaman - Cart ROM READER SNES ENHANCED, Famicom Cart Dumper, 2600, 5200, 7800, ARC, ATARI8, BALLY, C64, COLV, FAIRCHILD,
   INTV, LEAP, LJ, LJPRO, MSX, ODY2, PCW, POKEMINI, PV1000, PYUUTA, RCA, TI99, TRS80, VBOY, VECTREX, WSV, VIC20, VSMILE modules
   Tamanegi_taro - PCE and Satellaview modules
   splash5 - GBSmart, Wonderswan, NGP and Super A'can modules
   partlyhuman - Casio Loopy & Atari Lynx module
   hkz & themanbehindthecurtain - N64 flashram commands
   Andrew Brown & Peter Den Hartog - N64 controller protocol
   libdragon - N64 controller checksum functions
   Angus Gratton - CRC32
   Snes9x - SuperFX sram fix
   insidegadgets - GBCartRead
   RobinTheHood - GameboyAdvanceRomDumper
   Gens-gs - Megadrive checksum
   fceux - iNes header
   PsyK0p4T - Sufami Turbo module
   LuigiBlood - SNES Game Processor RAM Cassette module
   herzmx - CPS3 module

   And a special Thank You to all coders and contributors on Github and the Arduino forum:
   Ancyker, Andy-miles, BacteriaMage, Borti4938, Breyell, ButThouMust, CaitSith2, Chomemel, Dakkaron, Ducky92, Fakkuyuu, Gemarcano,
   Hxlnt, InvalidInterrupt, Jiyunomegami, Joshman196, Karimhadjsalem, Kreeblah, Lesserkuma, LuigiBlood, Majorpbx, Mattiacci, Modman,
   Niklasweber, Nsx0r, Partlyhuman, Philenotfound, Pickle, Plaidpants, PsychoFox11, PsyK0p4T, Qufb, RWeick, Ramapcsx2, Sakman55,
   Scrap-a, Sdhizumi, Smesgr9000, Splash5, Tombo89, Uzlopak, Vogelfreiheit, Vpelletier, Wfmarques

   And to nocash for figuring out the secrets of the SFC Nintendo Power cartridge.

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
**********************************************************************************/

#include "OSCR.h"

/******************************************
   Libraries
 *****************************************/

// SD Card
SdFs sd;
FsFile myFile;
#ifdef ENABLE_GLOBAL_LOG
FsFile myLog;
bool dont_log = false;
#endif

// AVR Eeprom
#include <EEPROM.h>
// forward declarations for "T" (for non Arduino IDE)
template<class T> int EEPROM_writeAnything(int ee, const T& value);
template<class T> int EEPROM_readAnything(int ee, T& value);

// Graphic SPI LCD
#ifdef ENABLE_LCD
#include <U8g2lib.h>
U8G2_ST7567_OS12864_F_4W_HW_SPI display(U8G2_R2, /* cs=*/12, /* dc=*/11, /* reset=*/10);
#endif

// Rotary Encoder
#ifdef ENABLE_ROTARY
#include <RotaryEncoder.h>
#define PIN_IN1 18
#define PIN_IN2 19
#ifdef rotate_counter_clockwise
RotaryEncoder encoder(PIN_IN2, PIN_IN1, RotaryEncoder::LatchMode::FOUR3);
#else
RotaryEncoder encoder(PIN_IN1, PIN_IN2, RotaryEncoder::LatchMode::FOUR3);
#endif
int rotaryPos = 0;
#endif

// Choose RGB LED type
#ifdef ENABLE_NEOPIXEL
// Neopixel
#include <Adafruit_NeoPixel.h>
Adafruit_NeoPixel pixels(3, 13, NEO_GRB + NEO_KHZ800);
#endif

typedef enum COLOR_T {
  blue_color,
  red_color,
  purple_color,
  green_color,
  turquoise_color,
  yellow_color,
  white_color,
  black_color,
} color_t;

// Graphic I2C OLED
#ifdef ENABLE_OLED
#include <U8g2lib.h>
U8G2_SSD1306_128X64_NONAME_F_HW_I2C display(U8G2_R0, /* reset=*/U8X8_PIN_NONE);
#endif

// Etherkit Clock Generator
#include <si5351.h>
Si5351 clockgen;
bool i2c_found;

// RTC Library
#ifdef ENABLE_RTC
#define _RTC_H
#include "RTClib.h"
#endif

// Clockgen Calibration
#ifdef OPTION_CLOCKGEN_CALIBRATION
#include "FreqCount.h"
#endif

void _print_FatalError(void) __attribute__((noreturn));
void print_FatalError(const __FlashStringHelper* errorMessage) __attribute__((noreturn));
void print_FatalError(byte errorMessage) __attribute__((noreturn));

/******************************************
  End of inclusions and forward declarations
 *****************************************/

template<class T> int EEPROM_writeAnything(int ee, const T& value) {
  const byte* p = (const byte*)(const void*)&value;
  unsigned int i;
  for (i = 0; i < sizeof(value); i++)
    EEPROM.write(ee++, *p++);
  return i;
}

template<class T> int EEPROM_readAnything(int ee, T& value) {
  byte* p = (byte*)(void*)&value;
  unsigned int i;
  for (i = 0; i < sizeof(value); i++)
    *p++ = EEPROM.read(ee++);
  return i;
}

/******************************************
  Common Strings
 *****************************************/
#define press_button_STR 0
#define sd_error_STR 1
#define reset_STR 2
#define did_not_verify_STR 3
#define _bytes_STR 4
#define error_STR 5
#define create_file_STR 6
#define open_file_STR 7
#define file_too_big_STR 8
#define done_STR 9
#define saving_to_STR 10
#define verifying_STR 11
#define flashing_file_STR 12
#define press_to_change_STR 13
#define right_to_select_STR 14
#define rotate_to_change_STR 15
#define press_to_select_STR 16

// This array holds the most often used strings
constexpr char string_press_button0[] PROGMEM = "Press Button...";
constexpr char string_sd_error1[] PROGMEM = "SD Error";
constexpr char string_did_not_verify3[] PROGMEM = "did not verify";
constexpr char string_bytes4[] PROGMEM = " bytes ";
constexpr char string_error5[] PROGMEM = "Error: ";
constexpr char string_create_file6[] PROGMEM = "Can't create file";
constexpr char string_open_file7[] PROGMEM = "Can't open file";
constexpr char string_file_too_big8[] PROGMEM = "File too big";
constexpr char string_done9[] PROGMEM = "Done";
constexpr char string_saving_to10[] PROGMEM = "Saving to ";
constexpr char string_verifying11[] PROGMEM = "Verifying...";
constexpr char string_flashing_file12[] PROGMEM = "Flashing file ";
constexpr char string_press_to_change13[] PROGMEM = "Press left to Change";
constexpr char string_right_to_select14[] PROGMEM = "and right to Select";
constexpr char string_rotate_to_change15[] PROGMEM = "Rotate to Change";
constexpr char string_press_to_select16[] PROGMEM = "Press to Select";

static constexpr const char* const string_table[] PROGMEM = {
  string_press_button0, string_sd_error1, FSTRING_RESET,
  string_did_not_verify3, string_bytes4, string_error5, string_create_file6,
  string_open_file7, string_file_too_big8, string_done9, string_saving_to10,
  string_verifying11, string_flashing_file12, string_press_to_change13,
  string_right_to_select14, string_rotate_to_change15, string_press_to_select16
};

void print_STR(byte string_number, boolean newline) {
  if (newline)
    println_Msg(FS(pgm_read_word(string_table + string_number)));
  else
    print_Msg(FS(pgm_read_word(string_table + string_number)));
}

/******************************************
  Defines
 *****************************************/

// optimization-safe nop delay
#define NOP __asm__ __volatile__("nop\n\t")

// Button timing
#define debounce 20        // ms debounce period to prevent flickering when pressing or releasing the button
#define DCgap 250          // max ms between clicks for a double click event
#define holdTime 2000      // ms hold period: how long to wait for press+hold event
#define longHoldTime 5000  // ms long hold period: how long to wait for press+hold event

/******************************************
   Variables
 *****************************************/
#ifdef ENABLE_ROTARY
// Button debounce
boolean buttonState = HIGH;          // the current reading from the input pin
boolean lastButtonState = HIGH;      // the previous reading from the input pin
unsigned long lastDebounceTime = 0;  // the last time the output pin was toggled
unsigned long debounceDelay = 50;    // the debounce time; increase if the output flickers
#endif

#ifdef ENABLE_OLED
// Button 1
boolean buttonVal1 = HIGH;           // value read from button
boolean buttonLast1 = HIGH;          // buffered value of the button's previous state
boolean DCwaiting1 = false;          // whether we're waiting for a double click (down)
boolean DConUp1 = false;             // whether to register a double click on next release, or whether to wait and click
boolean singleOK1 = true;            // whether it's OK to do a single click
long downTime1 = -1;                 // time the button was pressed down
long upTime1 = -1;                   // time the button was released
boolean ignoreUp1 = false;           // whether to ignore the button release because the click+hold was triggered
boolean waitForUp1 = false;          // when held, whether to wait for the up event
boolean holdEventPast1 = false;      // whether or not the hold event happened already
boolean longholdEventPast1 = false;  // whether or not the long hold event happened already
// Button 2
boolean buttonVal2 = HIGH;           // value read from button
boolean buttonLast2 = HIGH;          // buffered value of the button's previous state
boolean DCwaiting2 = false;          // whether we're waiting for a double click (down)
boolean DConUp2 = false;             // whether to register a double click on next release, or whether to wait and click
boolean singleOK2 = true;            // whether it's OK to do a single click
long downTime2 = -1;                 // time the button was pressed down
long upTime2 = -1;                   // time the button was released
boolean ignoreUp2 = false;           // whether to ignore the button release because the click+hold was triggered
boolean waitForUp2 = false;          // when held, whether to wait for the up event
boolean holdEventPast2 = false;      // whether or not the hold event happened already
boolean longholdEventPast2 = false;  // whether or not the long hold event happened already
#endif

// Variables for the menu
int choice = 0;
// Temporary array that holds the menu option read out of progmem
char menuOptions[7][20];
boolean ignoreError = 0;

// File browser
#define FILENAME_LENGTH 100
#define FILEPATH_LENGTH 132
#define FILEOPTS_LENGTH 20

char fileName[FILENAME_LENGTH];
char filePath[FILEPATH_LENGTH];
byte currPage;
byte lastPage;
byte numPages;
boolean root = 0;
boolean filebrowse = 0;

// Common
// 21 chars for ROM name, one char for termination
char romName[22];
unsigned long sramSize = 0;
int romType = 0;
byte saveType;
word romSize = 0;
word numBanks = 128;
char checksumStr[9];
bool errorLvl = 0;
byte romVersion = 0;
char cartID[5];
unsigned long cartSize;
unsigned int flashid;
char flashid_str[5];
char vendorID[5];
unsigned long fileSize;
unsigned long sramBase;
unsigned long flashBanks;
bool flashX16Mode;
bool flashSwitchLastBits;

// Variable to count errors
unsigned long writeErrors;

// Operation mode
CORES mode = CORE_MAX;

//remember folder number to create a new folder for every game
int foldern;
// 4 chars for console type, 4 chars for SAVE/ROM, 21 chars for ROM name, 4 chars for folder number, 3 chars for slashes, one char for termination, one char savety
char folder[38];

// Array that holds the data
byte sdBuffer[512];

// soft reset Arduino: jumps to 0
// using the watchdog timer would be more elegant but some Mega2560 bootloaders are buggy with it
void (*resetArduino)(void) __attribute__((noreturn)) = 0;

// Progressbar
void draw_progressbar(uint32_t processedsize, uint32_t totalsize);

// used by MD and NES modules
byte eepbit[8];
byte eeptemp;

// Array to hold iNES header
byte iNES_HEADER[16];
//ID 0-3
//ROM_size 4
//VROM_size 5
//ROM_type 6
//ROM_type2 7
//ROM_type3 8
//Upper_ROM_VROM_size 9
//RAM_size 10
//VRAM_size 11
//TV_system 12
//VS_hardware 13
//reserved 14, 15

//******************************************
// CRC32
//******************************************
// CRC32 lookup table // 256 entries
constexpr uint32_t crc_32_tab[] PROGMEM = { /* CRC polynomial 0xedb88320 */
  0x00000000, 0x77073096, 0xee0e612c, 0x990951ba, 0x076dc419, 0x706af48f,
  0xe963a535, 0x9e6495a3, 0x0edb8832, 0x79dcb8a4, 0xe0d5e91e, 0x97d2d988,
  0x09b64c2b, 0x7eb17cbd, 0xe7b82d07, 0x90bf1d91, 0x1db71064, 0x6ab020f2,
  0xf3b97148, 0x84be41de, 0x1adad47d, 0x6ddde4eb, 0xf4d4b551, 0x83d385c7,
  0x136c9856, 0x646ba8c0, 0xfd62f97a, 0x8a65c9ec, 0x14015c4f, 0x63066cd9,
  0xfa0f3d63, 0x8d080df5, 0x3b6e20c8, 0x4c69105e, 0xd56041e4, 0xa2677172,
  0x3c03e4d1, 0x4b04d447, 0xd20d85fd, 0xa50ab56b, 0x35b5a8fa, 0x42b2986c,
  0xdbbbc9d6, 0xacbcf940, 0x32d86ce3, 0x45df5c75, 0xdcd60dcf, 0xabd13d59,
  0x26d930ac, 0x51de003a, 0xc8d75180, 0xbfd06116, 0x21b4f4b5, 0x56b3c423,
  0xcfba9599, 0xb8bda50f, 0x2802b89e, 0x5f058808, 0xc60cd9b2, 0xb10be924,
  0x2f6f7c87, 0x58684c11, 0xc1611dab, 0xb6662d3d, 0x76dc4190, 0x01db7106,
  0x98d220bc, 0xefd5102a, 0x71b18589, 0x06b6b51f, 0x9fbfe4a5, 0xe8b8d433,
  0x7807c9a2, 0x0f00f934, 0x9609a88e, 0xe10e9818, 0x7f6a0dbb, 0x086d3d2d,
  0x91646c97, 0xe6635c01, 0x6b6b51f4, 0x1c6c6162, 0x856530d8, 0xf262004e,
  0x6c0695ed, 0x1b01a57b, 0x8208f4c1, 0xf50fc457, 0x65b0d9c6, 0x12b7e950,
  0x8bbeb8ea, 0xfcb9887c, 0x62dd1ddf, 0x15da2d49, 0x8cd37cf3, 0xfbd44c65,
  0x4db26158, 0x3ab551ce, 0xa3bc0074, 0xd4bb30e2, 0x4adfa541, 0x3dd895d7,
  0xa4d1c46d, 0xd3d6f4fb, 0x4369e96a, 0x346ed9fc, 0xad678846, 0xda60b8d0,
  0x44042d73, 0x33031de5, 0xaa0a4c5f, 0xdd0d7cc9, 0x5005713c, 0x270241aa,
  0xbe0b1010, 0xc90c2086, 0x5768b525, 0x206f85b3, 0xb966d409, 0xce61e49f,
  0x5edef90e, 0x29d9c998, 0xb0d09822, 0xc7d7a8b4, 0x59b33d17, 0x2eb40d81,
  0xb7bd5c3b, 0xc0ba6cad, 0xedb88320, 0x9abfb3b6, 0x03b6e20c, 0x74b1d29a,
  0xead54739, 0x9dd277af, 0x04db2615, 0x73dc1683, 0xe3630b12, 0x94643b84,
  0x0d6d6a3e, 0x7a6a5aa8, 0xe40ecf0b, 0x9309ff9d, 0x0a00ae27, 0x7d079eb1,
  0xf00f9344, 0x8708a3d2, 0x1e01f268, 0x6906c2fe, 0xf762575d, 0x806567cb,
  0x196c3671, 0x6e6b06e7, 0xfed41b76, 0x89d32be0, 0x10da7a5a, 0x67dd4acc,
  0xf9b9df6f, 0x8ebeeff9, 0x17b7be43, 0x60b08ed5, 0xd6d6a3e8, 0xa1d1937e,
  0x38d8c2c4, 0x4fdff252, 0xd1bb67f1, 0xa6bc5767, 0x3fb506dd, 0x48b2364b,
  0xd80d2bda, 0xaf0a1b4c, 0x36034af6, 0x41047a60, 0xdf60efc3, 0xa867df55,
  0x316e8eef, 0x4669be79, 0xcb61b38c, 0xbc66831a, 0x256fd2a0, 0x5268e236,
  0xcc0c7795, 0xbb0b4703, 0x220216b9, 0x5505262f, 0xc5ba3bbe, 0xb2bd0b28,
  0x2bb45a92, 0x5cb36a04, 0xc2d7ffa7, 0xb5d0cf31, 0x2cd99e8b, 0x5bdeae1d,
  0x9b64c2b0, 0xec63f226, 0x756aa39c, 0x026d930a, 0x9c0906a9, 0xeb0e363f,
  0x72076785, 0x05005713, 0x95bf4a82, 0xe2b87a14, 0x7bb12bae, 0x0cb61b38,
  0x92d28e9b, 0xe5d5be0d, 0x7cdcefb7, 0x0bdbdf21, 0x86d3d2d4, 0xf1d4e242,
  0x68ddb3f8, 0x1fda836e, 0x81be16cd, 0xf6b9265b, 0x6fb077e1, 0x18b74777,
  0x88085ae6, 0xff0f6a70, 0x66063bca, 0x11010b5c, 0x8f659eff, 0xf862ae69,
  0x616bffd3, 0x166ccf45, 0xa00ae278, 0xd70dd2ee, 0x4e048354, 0x3903b3c2,
  0xa7672661, 0xd06016f7, 0x4969474d, 0x3e6e77db, 0xaed16a4a, 0xd9d65adc,
  0x40df0b66, 0x37d83bf0, 0xa9bcae53, 0xdebb9ec5, 0x47b2cf7f, 0x30b5ffe9,
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
};

// Defined as a macros, as compiler disregards inlining requests and these are
// performance-critical functions.
#define UPDATE_CRC(crc, ch) \
  do { \
    uint8_t idx = ((crc) ^ (ch)) & 0xff; \
    uint32_t tab_value = pgm_read_dword(crc_32_tab + idx); \
    (crc) = tab_value ^ ((crc) >> 8); \
  } while (0)

uint32_t updateCRC(const byte* buffer, size_t length, uint32_t crc) {
  for (size_t c = 0; c < length; c++) {
    UPDATE_CRC(crc, buffer[c]);
  }
  return crc;
}

uint32_t calculateCRC(const byte* buffer, size_t length) {
  uint32_t crc = 0xFFFFFFFF;
  crc = updateCRC(buffer, length, crc);
  return ~crc;
}

uint32_t calculateCRC(FsFile& infile) {
  int32_t byte_count;
  uint32_t crc = 0xFFFFFFFF;

  while ((byte_count = infile.read(sdBuffer, sizeof(sdBuffer))) > 0) {
    crc = updateCRC(sdBuffer, byte_count, crc);
  }
  return ~crc;
}

// Calculate rom's CRC32 from SD
uint32_t calculateCRC(char* fileName, char* folder, unsigned long offset) {
  FsFile infile;
  uint32_t result;

  sd.chdir(folder);
  if (infile.open(fileName, O_READ)) {
    infile.seek(offset);
    result = calculateCRC(infile);
    infile.close();
    return result;
  } else {
    display_Clear();
    print_Msg(F("File "));
    //print_Msg(folder);
    //print_Msg(F("/"));
    //print_Msg(fileName);
    print_FatalError(F(" not found"));
    return 0;
  }
}

/******************************************
   CRC Functions for Atari, Fairchild, Ody2, Arc, etc. modules
 *****************************************/
#if (defined(ENABLE_ODY2) || defined(ENABLE_ARC) || defined(ENABLE_FAIRCHILD) || defined(ENABLE_MSX) || defined(ENABLE_POKE) || defined(ENABLE_2600) || defined(ENABLE_7800) || defined(ENABLE_C64) || defined(ENABLE_VECTREX) || defined(ENABLE_NES) || defined(ENABLE_LYNX) || defined(ENABLE_ATARI8) || defined(ENABLE_BALLY) || defined(ENABLE_LEAP) || defined(ENABLE_LJ) || defined(ENABLE_LJPRO) || defined(ENABLE_PV1000) || defined(ENABLE_PYUUTA) || defined(ENABLE_RCA) || defined(ENABLE_TI99) || defined(ENABLE_TRS80) || defined(ENABLE_VIC20) || defined(ENABLE_VSMILE) || defined(ENABLE_CPS3))

void printCRC(char* checkFile, uint32_t* crcCopy, unsigned long offset) {
  uint32_t crc = calculateCRC(checkFile, folder, offset);
  char tempCRC[9];

  if (crcCopy != NULL) {
    *crcCopy = crc;
  }

  sprintf(tempCRC, "%08lX", crc);
  print_Msg(F("CRC: "));
  println_Msg(tempCRC);
  display_Update();
}
#endif
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
void loop() {
  switch (mode) {
#ifdef ENABLE_N64
    case CORE_N64_CART: return n64CartMenu();
    case CORE_N64_CONTROLLER: return n64ControllerMenu();
#endif
#ifdef ENABLE_SNES
    case CORE_SNES: return snesMenu();
#endif
#if (defined(ENABLE_SFM) && defined(ENABLE_SNES))
    case CORE_SFM: return sfmMenu();
#ifdef ENABLE_FLASH
    case CORE_SFM_FLASH: return sfmFlashMenu();
#endif
    case CORE_SFM_GAME: return sfmGameOptions();
#endif
#ifdef ENABLE_GBX
    case CORE_GB: return gbMenu();
    case CORE_GBA: return gbaMenu();
    case CORE_GBM: return gbmMenu();
#if defined(ENABLE_FLASH)
    case CORE_GB_GBSMART: return gbSmartMenu();
    case CORE_GB_GBSMART_FLASH: return gbSmartFlashMenu();
    case CORE_GB_GBSMART_GAME: return gbSmartGameOptions();
#endif
#endif
#ifdef ENABLE_FLASH8
    case CORE_FLASH8: return flashromMenu8();
#ifdef ENABLE_FLASH16
    case CORE_FLASH16: return flashromMenu16();
    case CORE_EPROM: return epromMenu();
#endif
#endif
#ifdef ENABLE_MD
    case CORE_MD_CART: return mdCartMenu();
    case CORE_SEGA_CD: return segaCDMenu();
#endif
#ifdef ENABLE_PCE
    case CORE_PCE: return pceMenu();
#endif
#if (defined(ENABLE_SV) && defined(ENABLE_SNES))
    case CORE_SV: return svMenu();
#endif
#ifdef ENABLE_NES
    case CORE_NES: return nesMenu();
#endif
#ifdef ENABLE_SMS
    case CORE_SMS: return smsMenu();
#endif
#ifdef ENABLE_WS
    case CORE_WS: return wsMenu();
#endif
#ifdef ENABLE_NGP
    case CORE_NGP: return ngpMenu();
#endif
#ifdef ENABLE_INTV
    case CORE_INTV: return intvMenu();
#endif
#ifdef ENABLE_COLV
    case CORE_COL: return colMenu();
#endif
#ifdef ENABLE_VBOY
    case CORE_VBOY: return vboyMenu();
#endif
#ifdef ENABLE_WSV
    case CORE_WSV: return wsvMenu();
#endif
#ifdef ENABLE_PCW
    case CORE_PCW: return pcwMenu();
#endif
#ifdef ENABLE_ODY2
    case CORE_ODY2: return ody2Menu();
#endif
#ifdef ENABLE_ARC
    case CORE_ARC: return arcMenu();
#endif
#ifdef ENABLE_FAIRCHILD
    case CORE_FAIRCHILD: return fairchildMenu();
#endif
#ifdef ENABLE_SUPRACAN
    case CORE_SUPRACAN: return suprAcanMenu();
#endif
#ifdef ENABLE_MSX
    case CORE_MSX: return msxMenu();
#endif
#ifdef ENABLE_POKE
    case CORE_POKE: return pokeMenu();
#endif
#ifdef ENABLE_LOOPY
    case CORE_LOOPY: return loopyMenu();
#endif
#ifdef ENABLE_C64
    case CORE_C64: return c64Menu();
#endif
#ifdef ENABLE_2600
    case CORE_2600: return a2600Menu();
#endif
#ifdef ENABLE_5200
    case CORE_5200: return a5200Menu();
#endif
#ifdef ENABLE_7800
    case CORE_7800: return a7800Menu();
#endif
#ifdef ENABLE_LYNX
    case CORE_LYNX: return lynxMenu();
#endif
#ifdef ENABLE_VECTREX
    case CORE_VECTREX: return vectrexMenu();
#endif
#ifdef ENABLE_JAGUAR
    case CORE_JAGUAR: return jagMenu();
#endif
#if (defined(ENABLE_ST) && defined(ENABLE_SNES))
    case CORE_ST: return stMenu();
#endif
#if (defined(ENABLE_GPC) && defined(ENABLE_SNES))
    case CORE_GPC: return gpcMenu();
#endif
#ifdef ENABLE_ATARI8
    case CORE_ATARI8: return atari8Menu();
#endif
#ifdef ENABLE_BALLY
    case CORE_BALLY: return ballyMenu();
#endif
#ifdef ENABLE_LJ
    case CORE_LJ: return ljMenu();
#endif
#ifdef ENABLE_LJPRO
    case CORE_LJPRO: return ljproMenu();
#endif
#ifdef ENABLE_PV1000
    case CORE_PV1000: return pv1000Menu();
#endif
#ifdef ENABLE_VIC20
    case CORE_VIC20: return vic20Menu();
#endif
#ifdef ENABLE_LEAP
    case CORE_LEAP: return leapMenu();
#endif
#ifdef ENABLE_RCA
    case CORE_RCA: return rcaMenu();
#endif
#ifdef ENABLE_TI99
    case CORE_TI99: return ti99Menu();
#endif
#ifdef ENABLE_PYUUTA
    case CORE_PYUUTA: return pyuutaMenu();
#endif
#ifdef ENABLE_TRS80
    case CORE_TRS80: return trs80Menu();
#endif
#ifdef ENABLE_VSMILE
    case CORE_VSMILE: return vsmileMenu();
#endif
#if (defined(ENABLE_CPS3) && defined(ENABLE_FLASH8) && defined(ENABLE_FLASH16))
    case CORE_CPS3_CART: return flashromCPS_Cartridge();
    case CORE_CPS3_128SIMM: return flashromCPS_SIMM2x8();
    case CORE_CPS3_64SIMM: return flashromCPS_SIMM4x8();
#endif
    case CORE_MAX: return resetArduino();
  }
}

//******************************************
// End of File
//******************************************

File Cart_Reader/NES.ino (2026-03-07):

//******************************************
// NES MODULE
//******************************************
// mostly copy&pasted from "Famicom Dumper" 2019-08-31 by skaman
// also based on "CoolArduino" by HardWareMan
// Pinout changes: LED and CIRAM_A10

#ifdef ENABLE_NES

//Line Content
//37   Supported Mappers
//185  Defines
//211  Variables
//242  Menus
//456  Setup
//486  No-Intro SD Database Functions
//803  Low Level Functions
//1012 File Functions
//1083 Config Functions
//1704 ROM Functions
//3534 RAM Functions
//3934 Eeprom Functions
//4122 NESmaker Flash Cart Functions

struct mapper_NES {
  uint16_t mapper;
  uint8_t prglo;
  uint8_t prghi;
  uint8_t chrlo;
  uint8_t chrhi;
  uint8_t ramlo;
  uint8_t ramhi;
};

/******************************************
  Supported Mappers
 *****************************************/
// Supported Mapper Array (iNES Mapper #s)
// Format = {mapper,prglo,prghi,chrlo,chrhi,ramlo,ramhi}
static const struct mapper_NES PROGMEM mapsize[] = {
  { 0, 0, 1, 0, 1, 0, 2 },  // Nintendo NROM                                       [sram r/w]
  { 1, 1, 5, 0, 5, 0, 3 },  // Nintendo SxROM (MMC1B)                              [sram r/w]
  { 2, 2, 4, 0, 0, 0, 0 },  // Nintendo UxROM
  { 3, 0, 1, 0, 9, 0, 0 },  // Nintendo CNROM
  { 4, 1, 5, 0, 6, 0, 1 },  // Nintendo TxROM / HKROM (MMC3)                       [sram/prgram r/w]
  { 5, 3, 5, 5, 7, 0, 3 },  // Nintendo ExROM (MMC5)                               [sram r/w]
  // 6 - irrelevant (FFE RAM cartridges)
  { 7, 2, 4, 0, 0, 0, 0 },  // Nintendo AxROM
  // 8 - irrelevant (FFE RAM cartridges)
  { 9, 0, 3, 0, 5, 0, 0 },   // Nintendo PNROM (MMC2)
  { 10, 0, 4, 4, 5, 1, 1 },  // Nintendo FJROM / FKROM (MMC4)                      [sram r/w]
  { 11, 1, 3, 1, 5, 0, 0 },  // Color Dreams
  { 12, 0, 5, 0, 7, 0, 0 },  // 哥德 [Gēdé] SL-5020B
  { 13, 1, 1, 0, 0, 0, 0 },  // Nintendo CPROM (Videomation)
  // 14 - 哥德 [Gēdé] SL-1632 (武士魂/Samurai Spirits 8 characters version) [TODO]
  { 15, 6, 6, 0, 0, 0, 0 },  // K-1029 / K-1030P
  { 16, 3, 4, 5, 6, 0, 1 },  // Bandai FCG                                         [eep r/w]
  // 17 - irrelevant (FFE RAM cartridges)
  { 18, 3, 4, 5, 6, 0, 1 },  // Jaleco SS 8806                                     [sram r/w]
  { 19, 3, 4, 5, 6, 0, 1 },  // Namco N129/N163                                    [sram/prgram r/w]
  // 20 - irrelevant (FDS emulation)
  { 21, 4, 4, 5, 7, 0, 1 },  // Konami VRC4a / VRC4c                               [sram r/w]
  { 22, 3, 3, 5, 7, 0, 0 },  // Konami 351618 (VRC2a)
  { 23, 3, 3, 5, 7, 0, 0 },  // Konami VRC2b / VRC4e / VRC4f
  { 24, 0, 4, 0, 6, 0, 0 },  // Konami 351951 (VRC6a)
  { 25, 3, 4, 5, 7, 0, 1 },  // Konami VRC2c / VRC4b / VRC4d                       [sram r/w]
  { 26, 0, 4, 0, 6, 1, 1 },  // Konami 351949A (VRC6b)                             [sram r/w]
  { 27, 0, 7, 0, 8, 0, 0 },  // CC-21
  { 28, 5, 7, 0, 0, 0, 0 },  // Action 53
  { 29, 0, 3, 0, 3, 0, 0 },  // RET-CUFROM (Sealie Computing)
  { 30, 4, 5, 0, 0, 0, 0 },  // UNROM-512
  { 31, 6, 6, 0, 0, 0, 0 },  // 2A03 Puritans Album
  { 32, 3, 4, 5, 5, 0, 0 },  // Irem G-101
  { 33, 3, 4, 5, 6, 0, 0 },  // Taito TC0190 / TC0390
  { 34, 1, 9, 0, 4, 0, 0 },  // AVE NINA-001 / Nintendo BNROM
  { 35, 0, 7, 1, 8, 0, 0 },  // 晶太 [Jīngtài] EL870914C
  { 36, 0, 3, 1, 5, 0, 0 },  // TXC 01-22000-200/400
  { 37, 4, 4, 6, 6, 0, 0 },  // Nintendo ZZ (3-in-1)
  { 38, 1, 3, 0, 3, 0, 0 },  // 普澤 [Bit Corp.] PCI556 (Crime Busters)
  { 39, 3, 5, 0, 0, 0, 0 },  // Subor Study & Game 32-in-1 (duplicate of 241)
  { 40, 0, 3, 0, 3, 0, 0 },  // NTDEC 2722/2752
  { 41, 4, 4, 5, 5, 0, 0 },  // NTDEC 2399 (Caltron 6-in-1)
  { 42, 0, 3, 0, 5, 0, 0 },  // AC08/LH09 (FDS games hacked to cartridges)
  { 43, 2, 2, 0, 0, 0, 0 },  // TONY-I / YS-612 [88KiB]
  { 44, 5, 6, 7, 8, 0, 0 },  // Super HiK 7-in-1
  { 45, 3, 8, 0, 8, 0, 0 },  // TC3294 / GA23C
  { 46, 1, 6, 0, 8, 0, 0 },  // GameStation / RumbleStation
  { 47, 4, 5, 6, 7, 0, 0 },  // Nintendo NES-QJ (2-in-1)
  { 48, 3, 4, 6, 6, 0, 0 },  // Taito TC0690/TC0190+PAL16R4
  { 49, 0, 5, 0, 7, 0, 0 },  // 820401 / T-217 (Super HIK 4-in-1 MMC3 multicart)
  { 50, 3, 3, 0, 0, 0, 0 },  // N-32 (761214)
  // 51 - 820718C (11-in-1 Ball Games) [TODO]
  { 52, 0, 5, 0, 7, 0, 0 },  // Realtec 8213
  // 53 - Supervision 16-in-1 [TODO]
  // 54 - not used
  { 55, 1, 1, 0, 0, 0, 0 },  // NCN-35A / BTL-MARIO1-MALEE2 [56KiB]
  { 56, 0, 7, 0, 6, 0, 0 },  // Kaiser KS202 (SMB3)
  { 57, 0, 3, 0, 5, 0, 0 },  // GK 6-in-1
  { 58, 1, 6, 1, 6, 0, 0 },  // GK-192 (duplicate of 213)
  { 59, 0, 3, 0, 4, 0, 0 },  // BS-01/VT1512A (BMC-T3H53 + BMC-D1038)
  { 60, 1, 2, 1, 3, 0, 0 },  // Reset-based 4-in-1 NROM-128 multicarts
  { 61, 0, 5, 0, 5, 0, 0 },  // NTDEC GS-2017/0324
  { 62, 7, 7, 8, 8, 0, 0 },  // N-190B / K-1016 / K-1017P (Super 700-in-1)
  { 63, 8, 8, 0, 0, 0, 0 },  // NTDEC 2291 (Powerful multicart) / CH-011 / 82AB
  { 64, 2, 3, 4, 5, 0, 0 },  // Tengen 800032 (RAMBO-1)
  { 65, 3, 4, 5, 6, 0, 0 },  // Irem H-3001
  { 66, 2, 3, 2, 3, 0, 0 },  // Nintendo GNROM / MHROM
  { 67, 3, 3, 5, 5, 0, 0 },  // Sunsoft-3
  { 68, 3, 3, 5, 6, 0, 1 },  // Sunsoft-4                                          [sram r/w]
  { 69, 3, 4, 5, 6, 0, 1 },  // Sunsoft-5 (FME-5A, FME-5B, FME-7)                  [sram r/w]
  { 70, 3, 3, 5, 5, 0, 0 },  // Bandai UOROM
  { 71, 2, 4, 0, 0, 0, 0 },  // Codemasters BIC BF9093 / BF9097
  { 72, 3, 3, 5, 5, 0, 0 },  // Jaleco JF-17
  { 73, 3, 3, 0, 0, 0, 0 },  // Konami VRC3
  { 74, 0, 5, 0, 6, 0, 0 },  // 43-393 / 43-406 / 860908C
  { 75, 3, 3, 5, 5, 0, 0 },  // Konami VRC1
  { 76, 3, 3, 5, 5, 0, 0 },  // Namco 3446
  { 77, 3, 3, 3, 3, 0, 0 },  // Irem LROG017 (Napoleon Senki)
  { 78, 3, 3, 5, 5, 0, 0 },  // Jaleco JF-16 / Irem IF-12
  { 79, 1, 2, 2, 3, 0, 0 },  // AVE NINA-03, NINA-06, MB-91 / 聖謙 [Sachen] 3015, SA-016
  { 80, 3, 3, 5, 6, 0, 1 },  // Taito P3-33/34/36 (X1-005)                         [prgram r/w]
  // 81 - NTDEC N715021 (Super Gun) [TODO]
  { 82, 3, 3, 5, 6, 0, 1 },  // Taito P3-044 (X1-017, wrong bank order)            [prgram r/w]
  // 83 - Cony [TODO]
  // 84 - not used (PC-SMB2J)
  { 85, 3, 5, 0, 5, 0, 1 },  // Konami VRC7                                        [sram r/w]
  { 86, 3, 3, 4, 4, 0, 0 },  // Jaleco JF-13
  { 87, 0, 1, 2, 3, 0, 0 },  // Jaleco/Konami CNROM
  { 88, 3, 3, 5, 5, 0, 0 },  // Namco 3433
  { 89, 3, 3, 5, 5, 0, 0 },  // Sunsoft-2
  { 90, 0, 7, 1, 8, 0, 0 },  // 晶太 [Jīngtài] EL861226C
  { 91, 3, 5, 7, 8, 0, 0 },  // EJ-006-1 / 晶太 [Jīngtài] YY830624C/JY830848C
  { 92, 4, 4, 5, 5, 0, 0 },  // Jaleco JF-19
  { 93, 3, 3, 0, 0, 0, 0 },  // Sunsoft-3R
  { 94, 3, 3, 0, 0, 0, 0 },  // Nintendo UN1ROM
  { 95, 3, 3, 3, 3, 0, 0 },  // Namco 3425 (Dragon Buster)
  { 96, 3, 3, 0, 0, 0, 0 },  // Oeka Kids
  { 97, 4, 4, 0, 0, 0, 0 },  // Irem TAM-S1 (Kaiketsu Yanchamaru)
  // 98 - irrelevant (GBC to NES ports)
  // 99 - irrelevant (Nintendo Vs. System)
  // 100 - irrelevant (Nesticle MMC3)
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

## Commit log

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2020-08-14 Non swapped HuCARD adapter support. Changed Tennokoe Bank support to read/write files for each 2KB bank, one at a time.
    [PCE.ino]
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2021-04-06 Fix Ramtron GB Save read/write
    - [Ramtron datasheet](https://github.com/sanni/cartreader/files/6263159/001-86207_FM18W08_256-Kbit_32_K_8_Wide_Voltage_Byt-476756.zip)
    - [Write/Read capture](https://github.com/sanni/cartreader/files/6263148/write_read_gameboy_sram.zip) of the changed GB.ino from [Logic Analyzer](https://downloads.saleae.com/logic2/Logic+Setup+2.3.24-master.exe)
    [GB.ino]
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2021-04-15 V5.7: Add Clockgen option to N64 Eeprom
    Uncomment #define clockgen_installed in options.h and switch CLK1 switch to ON position. With Adafruit clockgen the eeprom now runs at the correct 2Mhz.
    [Cart_Reader.ino, N64.ino]
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2021-07-08 Update NGP.ino
    4M, 8M, 16M chips support added
    RomVersion detection fixed
    SystemType detection (NGP Monochrome or NGP Color) added
    [NGP.ino]
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2021-07-21 Fixes flashing MBC3; flash device id detection replaced by feature detection, adding compatibility for many repro flash carts.
    [Cart_Reader.ino, GB.ino]
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2021-12-11 GameShark Dump Compatability Update
    This has been confirmed to allow dumping v1.07, v1.09, v2.0-2.21, v3.2-3.3 with the below flash memory chips. Versions not listed may not work correctly or even be supported.
    SST 29LE010
    SST 28LF040
    AMTEL AT29LV010A
    SST 29EE010
    [N64.ino]
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2022-02-26 Add more cart info
    Correct COLOR flag for BANC09 and BANC0E
    Add info for Mobile WonderGate v1.1 cart
    Add developer name "SCC"
    [WS.ino]
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2022-07-06 Add no-intro database to NES
    This is just a beta release, stuff might be broken.
    [Cart_Reader.ino, FLASH.ino, GB.ino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]
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2022-07-23 Add support for missing GBA flash save chips (Atmel AT29LV512, Macronix MX29L512, Panasonic MN63F805MNP, SANYO LE26FV10N1TS)
    [GBA.ino]
2022-07-28 Fix 32KB GG
    32KB GG carts don't use mapper.
    Games sush as Columns, Woody Pop etc. are now dumped fine.
    [SMS.ino]
2022-07-30 Replace Frame STL with non-error version
    Replaces frame.stl with new design. 2 versions are being added.
    1 Main PCB Stand - No N64 Adapter (functionally the same as frame.stl)
    2 Main PCB Stand - Left N64 Adapter
    - same as 1 but with a modification to add a holder for the N64 Adapter to snap into
    [Main PCB Stand - Left N64 Adapter.step, Main PCB Stand - Left N64 Adapter.stl, Main PCB Stand - No N64 Adapter.step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]
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2022-08-19 Only correct SNES ROM size if non-standard size found in database, else trust header info to be correct
    [SNES.ino]
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2022-10-02 fixed mapper 30
    tested working with multiple NES and FC carts using UNROM-512
    [NES.ino]
2022-10-06 Increase romName array size from 17 to 22
    Crashed with Lufia II(Estpolis II) before.
    [Cart_Reader.ino, SNES.ino]
2022-10-08 V10.1 Move HW1/2/3 to same display lib as HW4/5
    ... bugs are to be expected :D
    [COLV.ino, Cart_Reader.ino, GBA.ino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]
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2022-10-22 Added NES mapper 60
    Added NES mapper 60 for reset-based NROM-128 4-in-1 multicarts.
    Tested working on 7 different NES carts.
    [NES.ino]
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2022-10-26 fix superfx sram size detection
    The header offsets were wrong so the size wasn't correctly computed and generally ended up defaulting to 32KB. Stunt Race FX, at least, uses 64KB and so only half the save data was being read.
    [SNES.ino]
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2022-10-28 All: Make flashid an integer
    flashid (almost) always contains the hexadecimal representation of two
    bytes, which then means it gets compares with strcmp, which in turn need
    another string argument. Instead, make it an integer, removing the need to
    call strcmp.
    Add a separate string representation for printing purposes (maybe this can be
    avoided by having the print function format it when needed ?).
    The only apparent case where flashid is not an hexadecimal representation
    of a pair of bytes is when N64 clears it to "CONF". Set flashid to zero
    this case.
    This saves about 500 bytes of program space and 200 bytes of ram.
    [Cart_Reader.ino, FLASH.ino, GB.ino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]
2022-10-28 PCE.ino: Skip strcpy to menuOptionspceCart
    Values can be directly composed/initialised in menuOptionspceCart, avoiding
    the need to strcpy to it.
    This saves about 100 bytes of ram by dropping a few global char arrays.
    Re-duplicates "Reset" string initialiser, but this should not be a big
    deal.
    [PCE.ino]
2022-10-28 Cart_Reader.ino: Simplify fileBrowser pagination.
    Also, this resolves a warning about `count` being potentially used
    uninitialised: when landing in the "Too many files" codepath.
    With this simplification, the limit on the number of files is removed. It
    is unclear whether that was intentional (maybe this was gating other
    issues ?)?
    [Cart_Reader.ino]
2022-10-28 Cart_Reader.ino: Drop convertPgm(const char* const [], byte, byte)
    This avoids code duplication between it and
    convertPgm(const char* const [], byte)
    for just 3 callers, when the callers can be easily updated to call the
    latter.
    [Cart_Reader.ino]
2022-10-28 Cart_Reader.ino: Assorted cosmetic changes to compareCRC.
    Shorten gamename to the number of bytes actually used in the code, more
    sizeof() use.
    [Cart_Reader.ino]
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2022-10-28 GBA.ino: Reduce gbaMenu size.
    Replace switch blocks which produce one output with const tables.
    Use functions instead of repeating code.
    Move common initial and final statements outside of blocks.
    Also, do not erase/flash second bank on dual-bank chips when the first one
    had failures.
    This saves about 520 bytes of code and increases ram use by 12 bytes.
    [GBA.ino]
2022-10-28 All: Factorise title generation from cart.
    Fix out-of-bound access when first byte is not an ascii printable
    character.
    Reduces program space use by 480 bytes.
    [Cart_Reader.ino, GB.ino, GBA.ino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]
2022-10-28 added NES mapper 91 + m36 typo fix
    added NES mapper 91 + m36 typo fix
    [NES.ino]
2022-10-29 Cart_Reader.ino: New variants of print_Error
    Tagged with noreturn so the compiler knows about the effect of
    forceReset=true.
    Ideally, print_Error should lose its forceReset argument so that:
    - print_Error never resets
    - print_FatalError always resets (and hosts the code doing so)
    so the compiler is more accurately aware of the execution flow.
    [Cart_Reader.ino]
2022-10-29 NES.ino: Convert nointro-disabled global variables into locals
    Also, remove dead error handling code: sd.exists internally opens the file
    and returns the produced status, so myFile.open return value should be the
    same.
    [NES.ino]
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2022-10-31 N64.ino: Assorted low-hanging fruits
    More sizeof() use, avoiding high-level loops when a callee can do it
    without the call overhead on every iteration, a bit of source code
    factorisation, avoiding initializers for large variables.
    [N64.ino]
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2022-10-31 Cart_Reader.ino: Factorise missing module error.
    Also, handle one such case in the HW3 main menu.
    [Cart_Reader.ino]
2022-10-31 All: Replace print_Error(*, boolean) calls with print_{,Fatal}Error(*)
    Also, make print_FatalError(*) independent from print_Error(*).
    Also, factorise common parts of print_Error(*).
    Frees 2336 bytes of program space and 5 bytes of global ram space.
    [COLV.ino, Cart_Reader.ino, FLASH.ino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]
2022-10-31 Fix reading/writing 4MB HiROM
    HiROM starts at bank 192 and has 64 banks so byte variable currBank overflows.
    [Cart_Reader.ino, GBA.ino, N64.ino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]
2022-11-01 SFM.ino, SNES.ino: Rework compiler warnings resolution
    I am not sure why I changed some variables from 16 bit types to 8 bit types
    when the warnings being resolved were only about signedness.
    Fixes: a555f21 ("All: Resolve all compiler and linker warnings")
    [SFM.ino, SNES.ino]
2022-11-01 SNES.ino: Restore code with side-effects
    This code was removed as part of
    a555f21 ("All: Resolve all compiler and linker warnings")
    because it was filling a 1kB buffer which was never read from.
    While I expect reading values from PINC should be invisible from the
    cartridge's perspective, writing to PORTL, PORTF and PORTK is definitely
    visible.
    I have currently no way of testing if this code is required, so in doubt
    restore the parts which have effects visible from the cartridge.
    [SNES.ino]
2022-11-01 Add fast scrolling through NES database
    Fast scrolling skips 30 entries at once.
    Also fixed lockup when browsing backwards on first database entry.
    [Cart_Reader.ino, NES.ino]
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2022-11-02 fixed NES mapper 206
    fixed NES mapper 206, tested working with FC game "Super Chinese"
    [NES.ino]
2022-11-02 actually fix all NAMCOT mappers similar to 206
    actually fix all NAMCOT mappers similar to 206
    [NES.ino]
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2022-11-05 Cart_Reader.ino: Simplify checkButton nesting
    Also, fixes a compiler warning on the HW4/5 function, which could reach
    the function's end without a "return" statement.
    [Cart_Reader.ino]
2022-11-05 Cart_Reader.ino: Move definitions after all forward declarations
    It seems the Arduino IDE picks the position of the first definition to
    insert all auto-generated forward declarations. This fails to compile if
    any of these generated forward declarations references a type included
    later.
    So, reorder the code a bit so the first definition happens strictly after
    the last inclusion.
    [Cart_Reader.ino]
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2022-11-11 fixed mapper 226
    forgot to set the high bit for bigger carts
    [NES.ino]
2022-11-11 fixed mapper 225/255
    i finally got 2 carts to confirm this is working with this fix
    [NES.ino]
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2022-11-25 Fix Vselect PCB
    5V and 3.3V were backwards on the headers to connect to the main PCB.
    Note: If you already ordered the PCB it still can be used, just install it upside down.
    [VSelect.kicad_pcb]
2022-12-10 [WIP] solving mappers with bus conflicts
    solving mappers with bus conflicts, mapper 2 is fixed, more to come after more testing
    [NES.ino]
2022-12-13 fixed mapper 63
    fixed mapper 63, tested working with Powerful 255-in-1 (CH-011 PCB)
    [NES.ino]
2022-12-14 fixed mapper 23
    fixed mapper 23, tested working with Ganbare Goemon 2
    [NES.ino]
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2022-12-22 added mappers 31, 57, 214 + fixes
    added mapper 31, 57, 214
    fixed 94, 97, 180 for bus conflicts
    fixed mapper 73 (see discussion https://github.com/sanni/cartreader/discussions/657 about Salamander)
    merged 200+212
    [NES.ino]
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2023-01-15 Fix display flicker on HW5 with Arc, Atari, Fairchild and Ody2 size/mapper selection
    [ARC.ino, ATARI.ino, FAIRCHILD.ino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]
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2023-01-30 Add support for Beggar Prince rev.1
    Fixes cart size, rom header provides wrong values
    [MD.ino]
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2023-02-10 Fix SRAM overflow in N64/MD, turn LED red if CRC not found
    [Cart_Reader.ino, MD.ino, N64.ino]
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2023-02-13 Update NGP.ino
    Fix path error for "Cotton (Japan)" and "Cotton (Europe)".
    Thx ickaze.
    [NGP.ino]
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2023-03-05 Update MD.ino
    - Add support for "Micro Machines 2 - Turbo Tournament (E)" and "Micro Machines - Military (E)"
    - "cartridges size fix" section was re-ordered by detected values
    [MD.ino]
2023-03-06 Update PCE.ino
    Improved convenience :
    - Tennokoe dumps are saved into a dedicated "./PCE/RAM/" folder
    - "Reset" command was moved to the very last option of PCE menu
    - Fixed the double button push when increasing/decreasing the bank index
    - Forced ROM size can be set via defined variable
    - Removed some repeated/unneeded function calls
    [PCE.ino]
2023-03-07 Update PCE.ino
    - fix a loop issue brought by yesterday's commit, when banks were increased/decreased and ROM dumped right after.
    - screen is now refreshing fine after bank increase/decrease or forced rom size
    - display the ROM size value to be set, before forcing it
    [PCE.ino]
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2023-03-30 Firmware Updater support, 3.3V Fix, and more
    Lots of changes/additions.
    Added:
    * Firmware Updater support: Supports the Firmware Updater app (release to follow soon). Enabled by default, can be disabled in the config.
    * 3.3V Fix (3V3FIX): Enable if you have stability issues when using 3.3V, works best with VSELECT. Disabled by default, can be enabled in the config.
    * `DynamicClockSerial`: Class that extends and modifies HardwareSerial to be compatible with a dynamically changing clock speed. Used through the `ClockedSerial` object/variable.
    * `OSCR.cpp` & `OSCR.h`: New files for storing globals. Only contains these new additions for now. More code cleanup to come.
    Changed:
    * Moved configur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
    [ARC.ino, ATARI.ino, COLV.ino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]
2023-04-02 Minor fixes/changes to six-slot adapter and git repository
    * Add JLCPCB order ID text to Six-Slot Adapter; you can select "specify location" for order number location when ordering from JLCPCB. It is placed so the SNES slot covers it. (PCB revision not incremented because it is only a minor change to the silkscreen.)
    * Added relative path for footprint and symbol libs to six-slot adapter project files.
    * Added footprint details/links to schematic symbols.
    * Added .gitignore and included most of the files that should remain local-only.
    [six_slot_adapter.kicad_pcb, six_slot_adapter.kicad_sch]
2023-04-06 Update SMS.ino
    SMS.ino rework :
    - new constants are used for adapters and systems (simplify conditions and checks)
    - dropped the feature to change adapter mode between two dumps (rarely used and adds many conditions)
    - added Retron 3in1 adapter for SMS dumping
    - added all possible rom sizes for SMS/GG and SG-1000 carts (40/48k mapping not yet supported)
    - during manual rom size selection, the offered values are adapted to selected system
    - moved code (function calls, function order...)
    - functions, variables, arrays renamed
    - comments added/modified
    More details listed in this thread : https://github.com/sanni/cartreader/discussions/742
    [SMS.ino]
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2023-04-11 [NES] fixed mapper 34
    fixed mapper 34, confirmed working thanks to Avalon
    [NES.ino]
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2023-04-15 [NES] Fixed mapper 3 CHR bus conflict
    Fixed mapper 3 CHR bus conflict
    [NES.ino]
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2023-04-24 Update MD.ino
    Fixed header checksum for :
    - Jeopardy! (USA)
    - Monopoly (USA)
    - Winter Olympic Games (USA)
    Moved code to other fixed games :
    - Fatman (Japan)
    Added support for :
    - YM2612 Instrument Editor (Aftermarket)
    - Decoder (Aftermarket)
    - Handy Harvy (Aftermarket)
    - Jim Power - The Lost Dimension in 3D (Aftermarket)
    [MD.ino]
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2023-05-24 Speed up checksum calculation by moving codes into rom dump procedure.
    Correct color flag for "BANC1A"
    Correct rom dump size of jss2/dknight to match db crc32
    [WS.ino]
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2023-06-26 Fix iNES header stored as text if CRC is not found in database
    [NES.ino]
2023-06-26 Fix automatic voltage selection (fixes #818)
    Fix for automatic voltage selection only working when 3V3FIX was enabled.
    [OSCR.cpp]
2023-06-26 Cleanup voltage requests
    The `setVoltage()` function should be called even when `ENABLE_VSELECT` is disabled because `ENABLE_3V3FIX` also uses it. There is no resource cost to do this as when both options are disabled the compiler will optimize this function out. This just "future proofs" the code so if that function ever does more it doesn't need updated everywhere. This applies to `setup_FlashVoltage()` as well.
    The changes to OSCR.cpp are just for code formatting and additional comments to clarify this.
    [ARC.ino, ATARI.ino, COLV.ino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]
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2023-07-06 Fixes issue with SRAM where writing to shared address port set control pins
    [LOOPY.ino]
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2023-08-14 Update GB.ino
    Removed unnecessary VSelect Option that may cause issues during compilation.
    [GB.ino]
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2023-09-13 Update N64.ino
    Update Xplorer64 functions in N64.ino to fix a potential issue for some hardware.
    [N64.ino]
2023-09-21 SNES.ino: Fix dumping Sound Novel Tsukuru (Japan) with same fix as for Derby Stallion '96 (Japan)
    [SNES.ino]
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2023-10-01 Update GB.ino
    This updates the GBC Gameshark functions to check the Chip ID before performing any other functions, which ensures a good connection with the Gameshark cartridge and prevents erroneous dumps or writes due to poor connection.
    [GB.ino]
2023-10-17 Fix Clock Gen Calibration Menu
    Function didn't display negative calibration factors correctly.
    Also added option to use the calibration factor without enabling the calibration menu to save some space.
    [Cart_Reader.ino]
2023-10-17 N64: Add error message if eeprom does not return data
    Should prevent problem as described in discussion #857
    [N64.ino]
2023-11-02 Update PCW.ino
    - Added : size detection for Multi-pack cartridges
    - Modified : dump function for Multi-pack cartridges
    - Added : timing fixes needed for recent HW revisions
    [PCW.ino]
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2024-02-29 Add support for MBC30 flash cart by HDR (thx to ManCloud)
    Two issues were resolved:
    - this flashcart uses the Audio-In pin instead of the WR pin
    - Writing 4MB gets stuck after bank 170 and needed the SRAM to be mapped (same as MBC5)
    [GB.ino]
2024-02-29 Update 7800.ino
    Add clock generator usage to fix timing issues (thanks to @smesgr9000)
    [7800.ino]
2024-02-29 Added ability to use config file for some options.
    A sample `config.txt` is in the SD folder. Currently the option is disabled by default and must be enabled.
    Also:
    * Eliminated the 5V spike at boot when VSELECT is installed and enabled. See discussion #906
    * Fixed a warning in `MD.ino`
    * Did some code cleanup, more cleanup to come.
    [config.txt]
2024-03-02 Code optimization, cleanup, and stylization
    * Reduced PROGMEM / DRAM usage slightly (Using defaults w/HW5: Before -> 214,668 bytes / 5,757 bytes; After -> 213,414 bytes / 5,751 bytes)
    * Optimized some menu options and calls
    * Added more string constants and implemented them where found.
    * Fixed some stylization
    * Constants should always be uppercase.
    * Features should use the `ENABLE_<feature name>` format.
    * Options for features should use the `OPTION_<feature name>_<option name>` format.
    * Added ENUMs for more clarity and better type checking.
    * Moved some defines over to `constexpr` and `const` types. These are preferred over preprocessor constants when not intended for use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
    [config.txt]
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2024-03-07 Update MD.ino
    Thanks to psychofox :
    - Fix Madden NFL 98 (USA)
    - More aftermarket games added
    [MD.ino]
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2024-04-27 replace 2600 cart selection code with code used in NES, COLV & INTV
    [2600.ino, 7800.ino]
2024-04-27 Update C64.ino
    Fix Issue #902 Handling of GAME and EXROM lines of C64 cartridges is wrong. Requires updated c64cart.txt on SD card.
    [C64.ino]
2024-04-28 replace C64 cart selection code with code used in NES, COLV & INTV
    [C64.ino]
2024-04-29 replace 5200 and ARC cart selection code with code used in NES, COLV & INTV
    [5200.ino, ARC.ino, COLV.ino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]
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2024-05-01 replace FAIRCHILD, ODY2, MSX and VECTREX cart selection code with code used in NES, COLV & INTV. Define "Database not found" in OSCR.cpp
    [2600.ino, 5200.ino, 7800.ino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]
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2024-05-01 fix issue #939. Remove duplicate write of laster buffer. Also add Berzerk Enhanced
    [2600.ino]
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2024-05-07 Fixed (added) missing FS() macro on some FSTRING constants
    This was causing two symptoms/bugs:
    * OSCR_LOG.txt was being spammed with random data.
    * The size of OSCR_LOG.txt would get so big that copying the log would take a long time, possibly minutes. Oftentimes this caused the display to appear to hang after searching for the CRC (after "->") but before displaying the result.
    If using the global log and a version of master since e61ac414d89556c941f0b8ca76e5d7d6684037f0 you should delete OSCR_LOG.txt from your SD card as it will likely be very large and continue to cause dumping to be slow.
    [Cart_Reader.ino, N64.ino]
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2024-05-24 support mapper > 255, implement mapper 446 submapper 0&1 - thanks to NewRisingSun for support, fix iNES2.0 mapper parsing of byte 8
    [NES.ino]
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2024-06-02 Fix compilation errors and warnings
    Fixing issues when only ENABLE_GBX was enabled or when compiling for a serial-only firmware.
    [Cart_Reader.ino]
2024-06-02 Add checks for unsafe configurations
    * Fixes #929
    * Updated `ci.yml` to define `GITHUB_CI`
    * Compilation will now error if VSELECT is enabled on hardware versions that don't support it (any version other than HW5).
    * HW4 and SERIAL might work but are untested. The error message for these versions reflects this.
    * Erroring when unsafe configurations are defined can be overridden by defining `ALLOW_UNSAFE_CONFIG` which will throw a warning instead.
    * This should only be done if trying to implement or test on a currently unsupported platform.
    * If both `GITHUB_CI` and `ALLOW_UNSAFE_CONFIG` are defined an error will be thrown causing the CI tests to fail. This is just in case someone makes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
    [OSCR.h]
2024-06-10 Fix compilation errors when the FLASH core is enabled without FLASH16
    Commit References:
    * a32c6b3bfff066b04d81faea0e578b80cb4a3108 - Added ATTENTION_3_3V flash string but placed the definition inside a FLASH16 ifdef.
    * 4d000418a8f4e4a29297f83e30922100da7b21f5 - Added use of writeWord_Flash to FLASH8 without removing the FLASH16 ifdef around it.
    [FLASH.ino]
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2024-07-24 Update PCE.ino
    Various changes
    - restore Reset option in PCE menu
    - fix wrong file creation location when reading multiple games in a row
    - simplified crc search
    [PCE.ino]
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2024-07-27 Fix for VRC2B Famicom Carts
    Instead of bank switching on a single bank and reading 1024 bytes
    at a time, this update switches 8 banks at a time and reads 8 KiB
    per iteration. The hypothesis is that the timing between
    bank switching and reading 1024 bytes at a time is insufficient for
    the mapper while reading in batches of 8 KiB allows for enough
    time for the data to be switched and accessible.
    This change fixes the ability to dump the following
    VRC2B Famicom cartridges:
    B27B8CF4 -> Contra (Japan).nes
    49123146 -> Getsu Fuuma Den (Japan).nes
    AC9895CC -> Dragon Scroll - Yomigaerishi Maryuu (Japan).nes
    Also verified a VRC4E Famicom Cartridge:
    C1FBF659 -> Akumajou Special - Boku Dracula-kun (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
    [NES.ino]
2024-07-29 SMS Updates
    1. SMS cart size detection algorithm is updated based on bank count instead of multiples of detected cart size from the header.
    2. SMS cart size detection is only invoked if the "TMR SEGA" header is parsed for non-JP carts.
    3. Manual selection of ROM size is now present in the SMS/GG menus to allow for manual override as detection algorithm does not work correctly for Cloud Master and Penguin Land US SMS carts.
    4. SG-1000 Operation menu now allows for reset instead of relying on a power cycle.
    [SMS.ino]
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2024-08-01 Atari 5200 Updates
    1. Added CRC database lookup for ROM dump validation and file renaming
    2. Added delays to improve successful ROM dumping. Especially helps with
    2-chip ROMs
    3. Fixed database mapper config for Star Trek (not a 2-chip ROM)
    [5200.ino, Cart_Reader.ino]
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2024-08-14 Update SMS.ino
    Fix wrong file creation location when reading multiple ROMs in a row
    [SMS.ino]
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2024-08-28 Fix/cleanup the VSELECT Module project files
    * Fixed the field name for the LCSC part number so the BOM exports with the part numbers.
    * Removed the test points from the schematic as they are no longer needed.
    * Added notes for setting the ILIM resistor to the schematic.
    * Added an image of the PCB and PDF of the schematic.
    Note: The PCB itself didn't change, so it is still Rev 3.
    [VSelect.kicad_pcb, VSelect.kicad_sch, VSelect_bom.csv]
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

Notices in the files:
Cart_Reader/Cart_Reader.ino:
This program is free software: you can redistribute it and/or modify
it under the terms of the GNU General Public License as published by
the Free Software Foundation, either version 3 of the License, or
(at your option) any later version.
